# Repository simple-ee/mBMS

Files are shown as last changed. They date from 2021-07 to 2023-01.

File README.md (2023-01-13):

# WARNING!
Just a reminder that this is a DIY product/solution so don’t use this for safety 
critical systems or in any situation where there could be a risk to life. 
There is no warranty, it may not work as expected or at all.

# modular BMS by simple-ee.com
This is what I am calling the modular BMS for an 8S LiFePO4 pack.  I've designed
this as three main parts.  Currently this design is functional and running my
system but I am in the progress of overhauling the design by upgrading from an 
8-bit ATmega328PB to a 32-bit SAMD21G18 using the arduino zero bootloader.

Right now I'm essentially maxed out resources and memory on the atmega328PB and
cannot add anymore features which is why I'm planning on upgrading the design.

Even though this design is now my old design its still very functional and very
stable as it has been running my 4kWh system for about 6 months and protecting 
the cells perfectly.  

The reason for making it a modular design is for easy upgradability and also,
considering the current chip shortage, is to replace sections of the board in
case there are no parts available.  This will prevent the need to redo and 
re-layout of the entire design.

I'm posting this design because I've learned a lot from other projects and feel
this will help a lot of people and want to give back.  Also smarter people than
me could take this design and help optomize the code and design and make this a
community BMS.

## the Table of Contents
1. [the Setup](#thesetup)
    1. [Software/Bootloader](#software)
    2. [Wiring and Connection](#connect)
2. [Pinout and Block Diagram](#pinout)
3. [Board Information](#information)
    1. [the Protection Board](#theProtectionBoard)
    2. [the BMS Board](#theBMSBoard)
    3. [the Passive Board](#thePassiveBoard)
    4. [the Display](#display)

## the SETUP 

### Software/Bootloader 
[Software Setup](https://github.com/simple-ee/mBMS/tree/main/Setup)

### Wiring and Connection 
#### Single 8S Pack Wiring Diagram
Here we have the wiring diagram for connecting the mBMS to an 8S pack and is considered a single pack system:

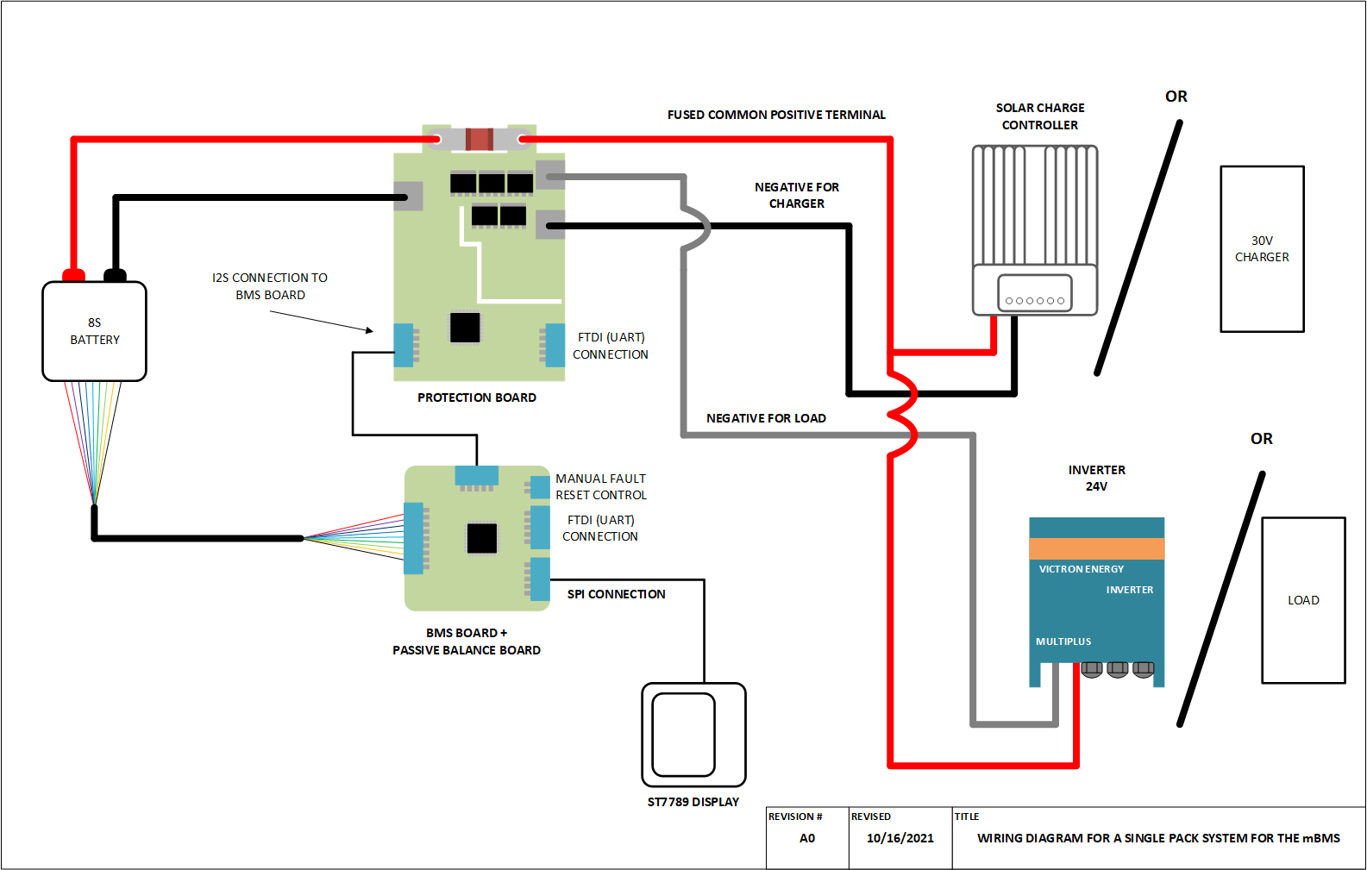
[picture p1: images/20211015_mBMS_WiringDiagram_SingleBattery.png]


#### Parallel multiple 8S Wiring Diagram
Here we have the wiring diagram for connecting multiple 8S packs in parallel.  Here each 8S pack is protected by its own mBMS and then they are paralleled together using 
ideal diodes to make sure that the other packs in parallel do not charge or discharge a pack that has gone into protection.  I designed the system this way to allow
for scalability of system storage.  By protecting each pack separately then you can, theoretically, add tens of hundreds of 8S packs in parallel when you need more storage
without having to reconfigure your system to add more storage or turn off the system to add more storage.

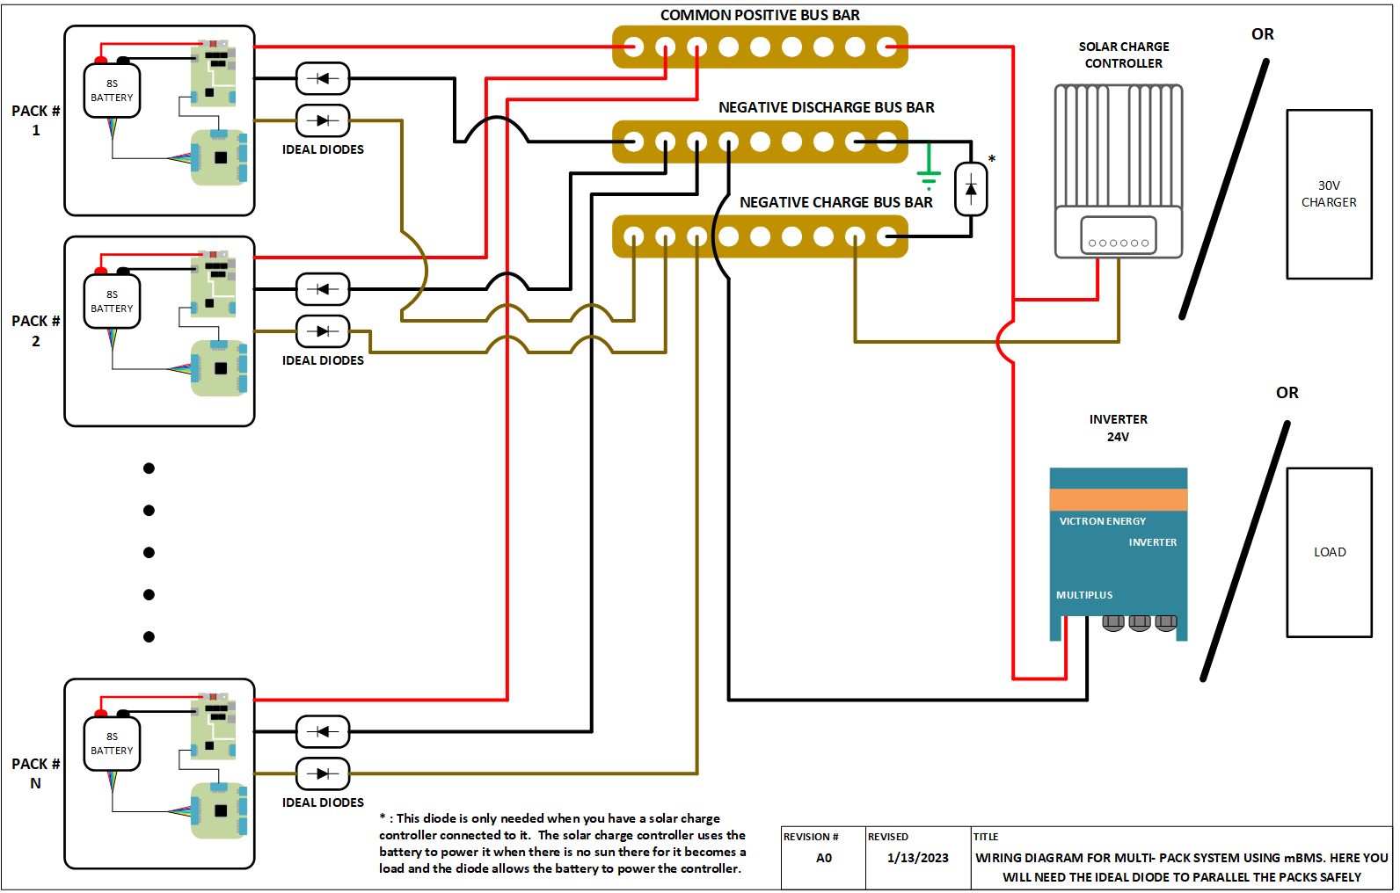
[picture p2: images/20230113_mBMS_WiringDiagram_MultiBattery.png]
 

## Pinout and Block Diagram 

### the Protection Board
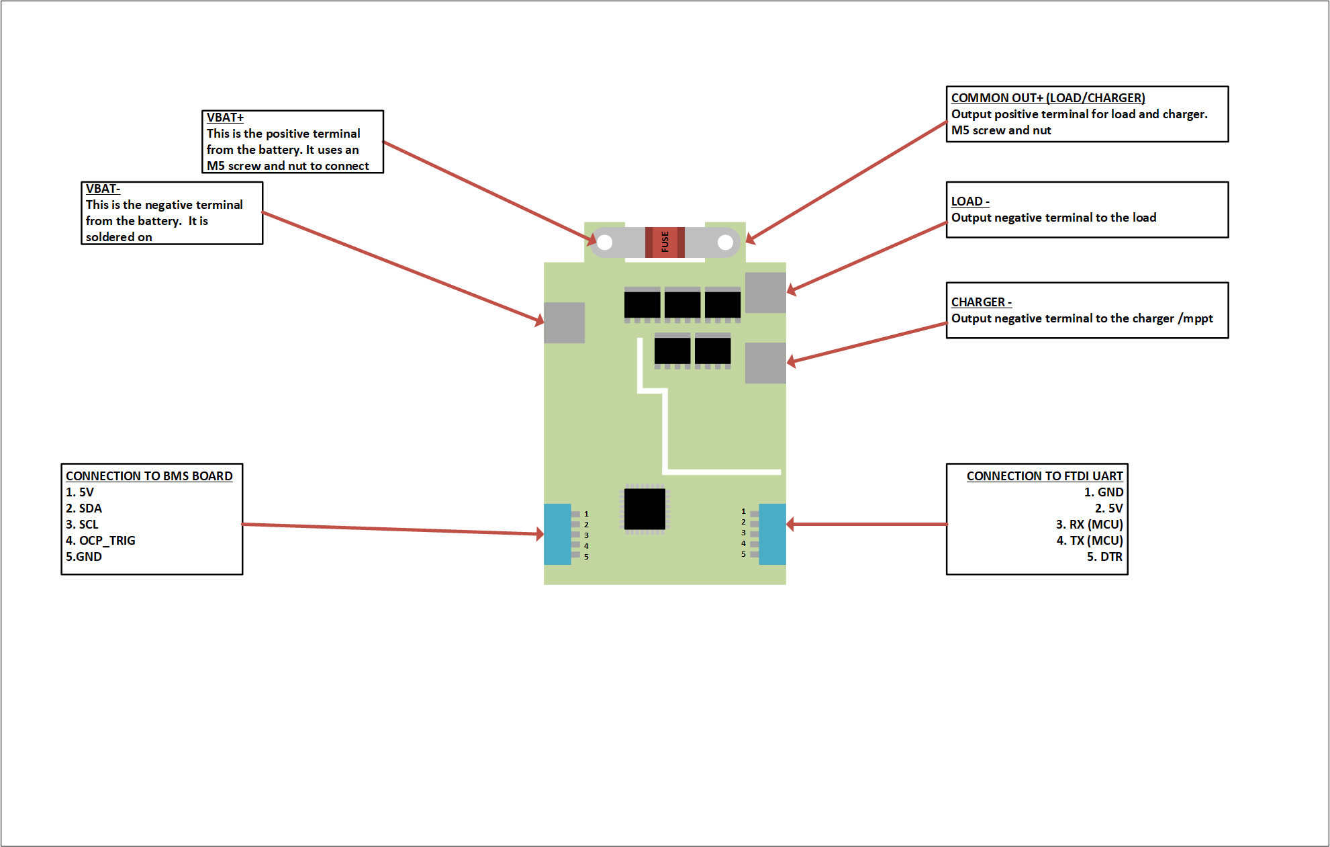
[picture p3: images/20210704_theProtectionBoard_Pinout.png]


## Board information 

### the Protection board 

[kicad Files and gerber files](https://github.com/simple-ee/mBMS/tree/main/Schematic/The%20Protection%20Board)

#### Rendered PCB
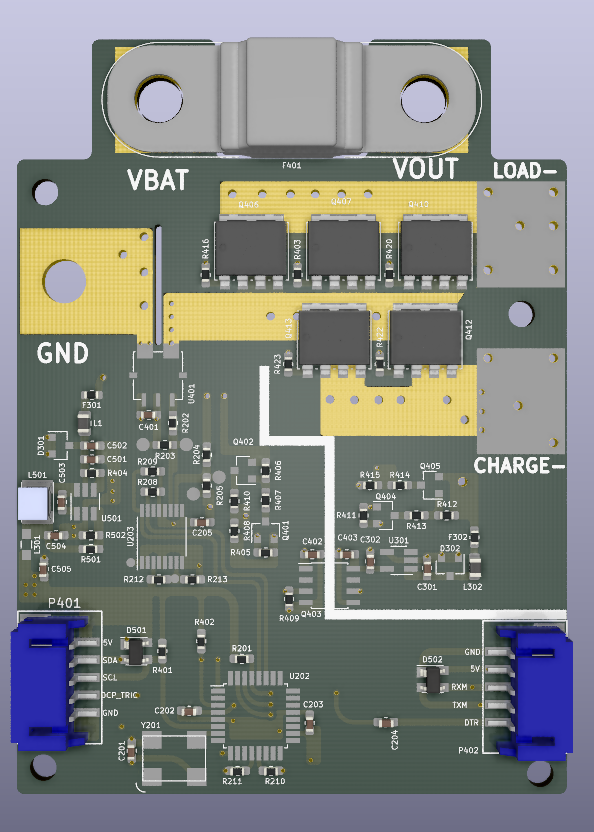
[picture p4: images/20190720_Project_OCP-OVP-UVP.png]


#### Actual PCB
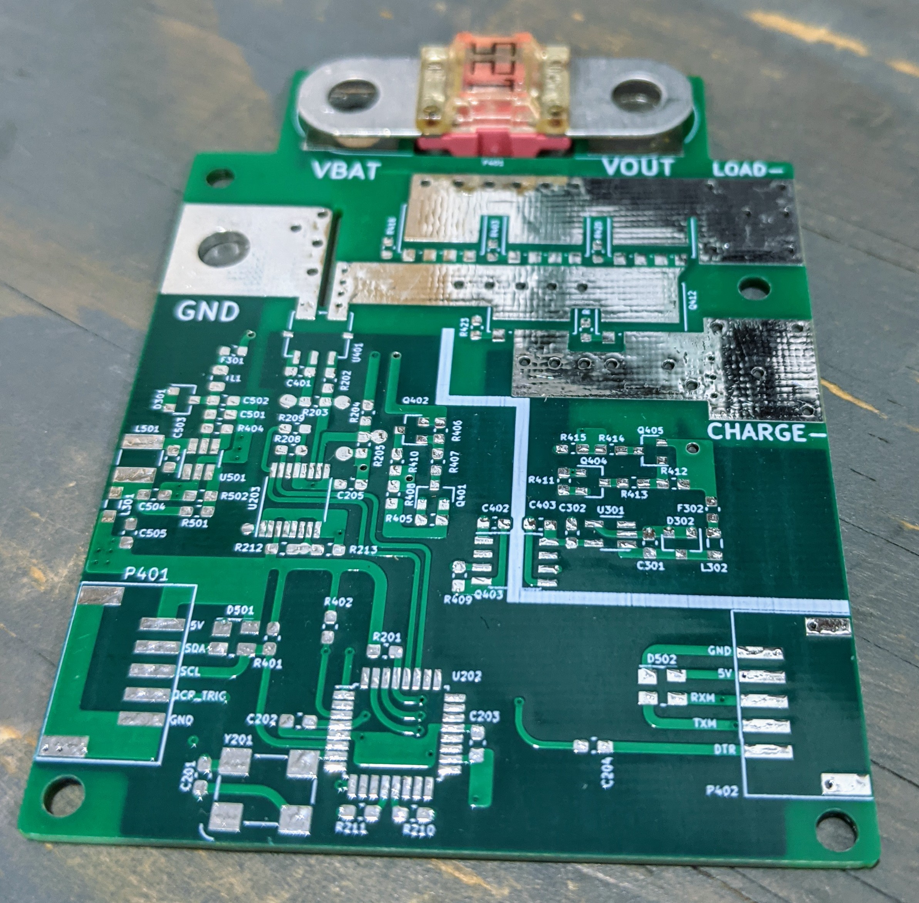
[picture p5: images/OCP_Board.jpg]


- This board will handle discharge and charge currents between the battery
and the external world.  
- It has the following specs:

    Item | Description
    -----|------------
    1 | 4-Channel 16-BIT ADC with an effective resolution of 16-Bit at 20sps
    2 | 100A hall effect current sensor
    3 | Up to 3 Discharge N-Channel MOSFETS with 0.7mOhm DCR and 425A current capability. ( Effective current handling per mosfet without heatsink is 30A)
    4 | Up to 2 charge N-Channle MOSFETS with 0.7mOhm DCR and 425A current capability. (Effective current handling per mosfet without heatsink is 30A)
    5 | Optoisolator to drive the charge mosfets as it is floating relative to the battery ground.
    6 | High efficiency buck converter to power the MCU and supporting circuits.
    7 | Low power LDO to power the secondary side of the optoisolator to drive the charge MOSFET
    8 | Two I2C ports, one to act as an internal COM for adc and display, andsecond one to act as external COM to relay information to BMS board
    9 | 125A fuse that will act as the short circuit protection with a breaking capacity of 1kA.

### the BMS Board 

[kicad Files and gerber files](https://github.com/simple-ee/mBMS/tree/main/Schematic/The%20BMS%20Board)

#### Rendered PCB
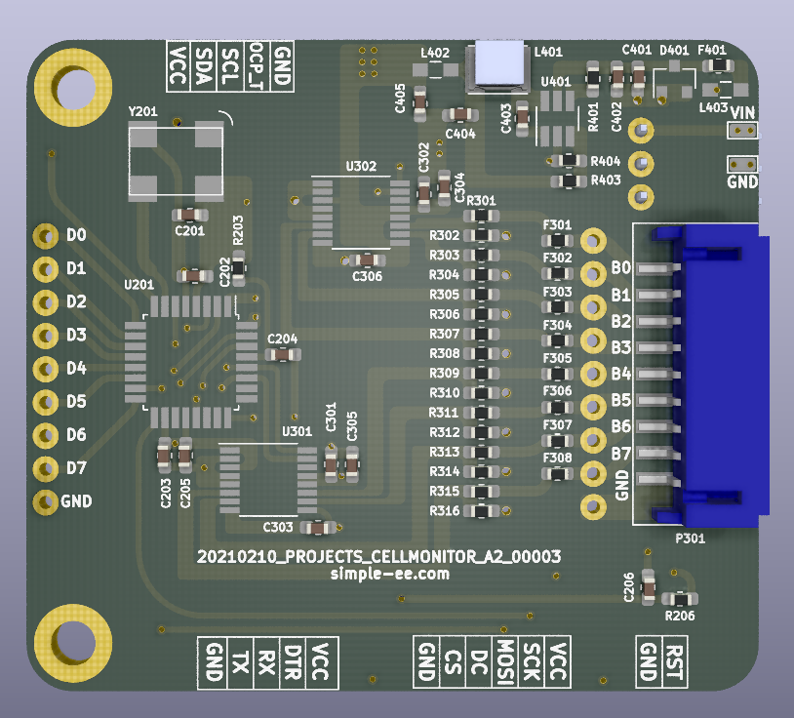
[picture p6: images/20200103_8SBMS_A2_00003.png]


#### Actual PCB
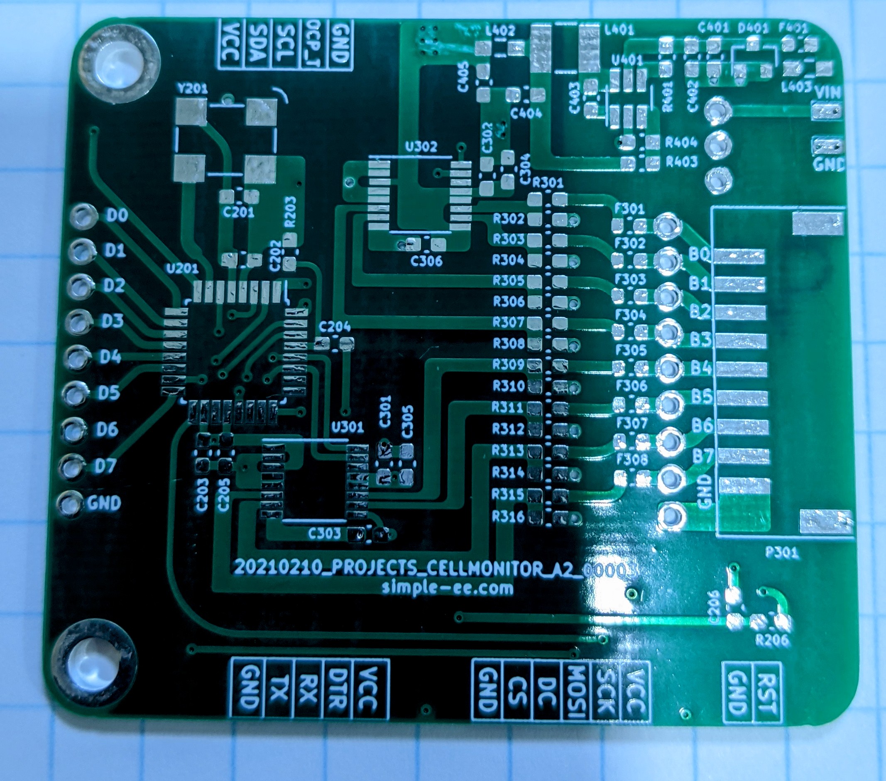
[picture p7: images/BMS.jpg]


- This board is handling the cell level monitoring function as well as sending
controls to the passive balance resistors for balancing the cells.  It 
incorporates cell level OVP and UVP which is configurable and also receives the
current values from the Protection board via I2C and then displays all values
on a TFT display either ST7735 or ST7789.  If for any reason a fault is triggered
or one of the configured protection values is triggered you can send a reset
fault command either via an external trigger button or serial command over uart.
- It has the following specs:

Item | Description
-----|------------
1 | x2 4-Channel 16-BIT ADC with an effective resolution of 16-BIT at 20sps
2 | External 16MHz Crystal oscillator
3 | External SPI port to connect TFT display
4 | Can be powered via the battery pack or external power source
5 | External action button. Default state is for reset fault condition

### the Passive Balance Board 

[kicad Files and gerber files](https://github.com/simple-ee/mBMS/tree/main/Schematic/The%20Passive%20Balance%20Board)

#### Rendered PCB
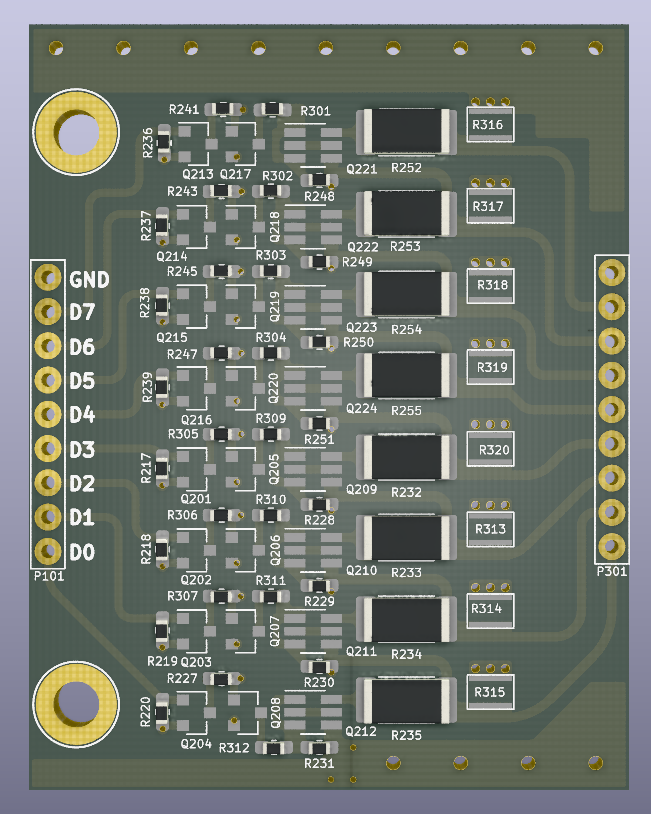
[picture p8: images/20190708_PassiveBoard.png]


#### Actual PCB
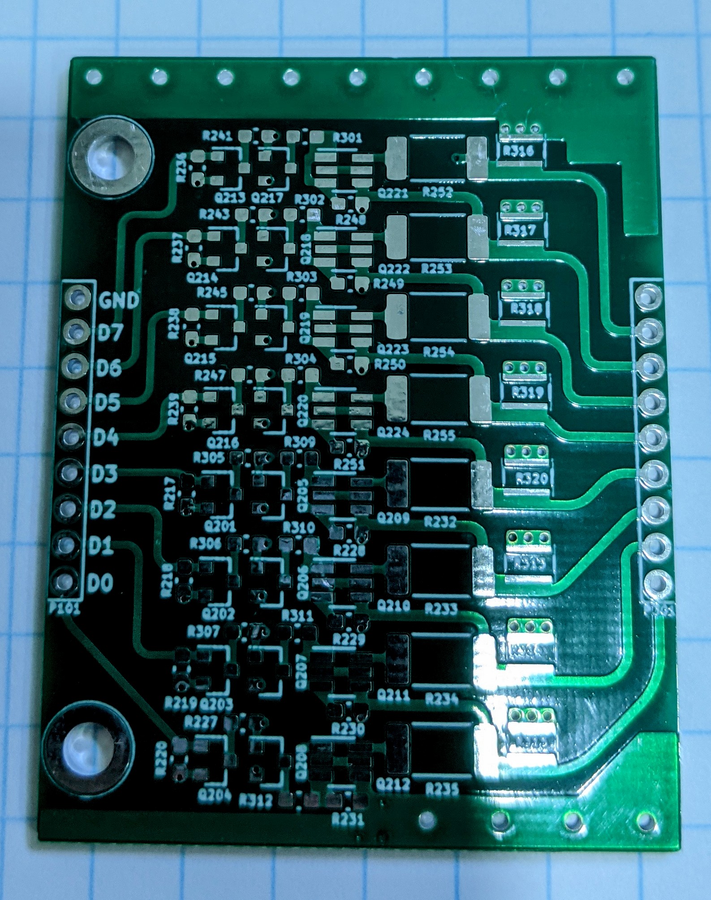
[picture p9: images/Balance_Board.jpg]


The passive board essentially is controlled by the BMS board to allow the 
bleeder resistor to slow down the rate of charge for that particular cell when
the BMS board detects that the cell is too high of a delta from the rest.

Currently I have a 2W 10R resistor but I'm having thermal issues because its 
quite a lot of power to dissapate over the whole board so I'd recommend a 22R 2W
resistor which is still good for what you need but will not cause any potential
damage.

The board also have the option of adding thermal jumpers and if you do decide to 
do that then I'd recommend a 2oz copper for that PCB.  Thermal jumpers are electrically
isolated and allow you to connect directly to ground without shorting anything
which is pretty awesome in my opinion.

Heres the link for the thermal jumpers.  They are really awesome but with the chip
shortage its a decent lead time for them.

https://www.digikey.com/en/products/detail/vishay-dale-thin-film/THJP0612AST1/11313314

### the Display (optional) 
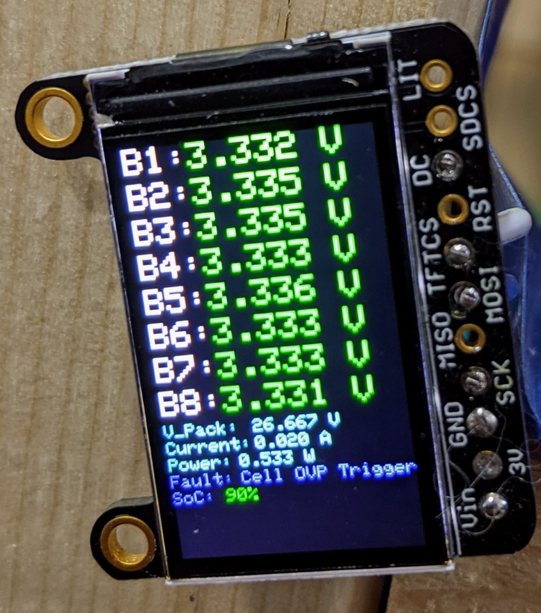
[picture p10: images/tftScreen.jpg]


Currently the SoC is not an implemented function its just a placeholder.  But if
anyone is willing to help out with this SoC code section then that would be 
awesome as I'm still not sure the best way to implement this.

The screen is to be used with the BMS board.  the Protection does not have 
the ability to use a SPI TFT display but if you use it on its own, then you can
add an I2C oled display because the secondary I2C will not be used.

Here is a link to the tft display that I used.
https://www.adafruit.com/product/4383

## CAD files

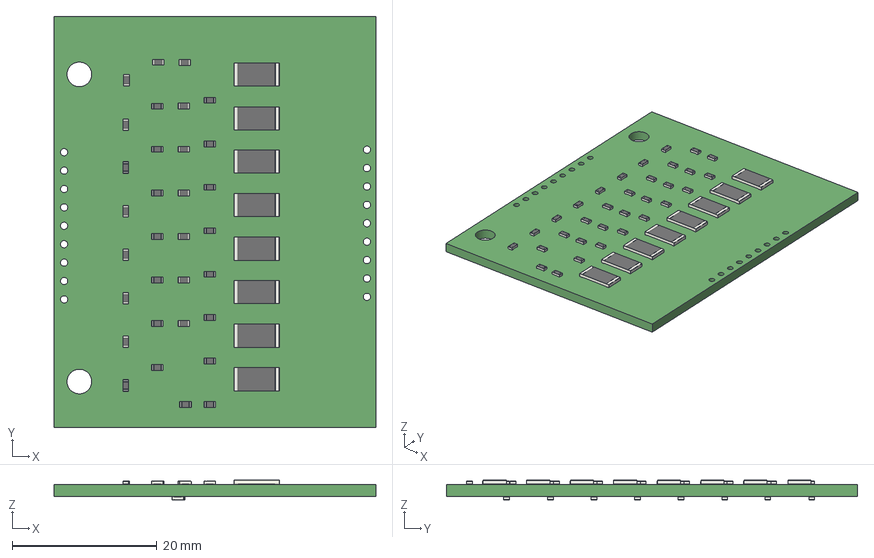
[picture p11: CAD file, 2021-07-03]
Schematic/The Passive Balance Board/20210213_Projects_PassiveBalanceBoard.step
44.5 x 56.8 x 2.75 mm

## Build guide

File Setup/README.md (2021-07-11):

# SETUP for modular BMS by simple-ee.com
Here we will choose the bootloader for this board, upload the arduino sketch,
and run through the different serial and I2C commands for both the Protection
board as well as the BMS board.

We will also run through the calibration of the adc inputs to get an accurate
voltage measurement and current measurement.

We will also run through the two different ways of using this system.
1. Using the Protection board on its own
2. Connecting the Protection board to the BMS board for cell level protection

## the Table of Contents
1. [the bootloader](#bootloader)
2. [Arduino Sketch](#sketch)
3. [the Protection Board Configuration](#protection)
4. [the BMS Board Configuration](#bms)

## Bootloader
Here I decided to use the minicore bootloader for the atmega328PB as it allowed
me to configure the arduino with various options, it seems very efficient in 
memory space and also supports the PB variant of atmega328

[minicore](https://github.com/MCUdude/MiniCore)

Note: Since I did not add the SPI pins on the board (MOSI,MISO) you will have
to install the bootloader before soldering it to the board.  You can follow the
guide below to add the bootloader using an arduino uno board:

[Install ardunio bootloader](https://www.arduino.cc/en/Tutorial/BuiltInExamples/ArduinoToBreadboard)

https://www.arduino.cc/en/Tutorial/BuiltInExamples/ArduinoToBreadboard

## Arduino sketch
Here is the source code link for both:

1. The Protection board
    1. [theProtectionBoard](https://github.com/simple-ee/mBMS/tree/main/Source%20Code/theProtectionBoard/)
2. The BMS Board
    1. [theBmsBoard](https://github.com/simple-ee/mBMS/tree/main/Source%20Code/theBMSBoard/20210703_theBMSBoard_A6)

Note: For board source code files, I created a second file called ADS1119.h which
I created to make using the ADC easier in the arduino code.  This file must be in the
same folder as the arduino ino.

## the Protection Board configuration

To perform setup you will need the following items:
1. Multimeter
2. UART FTDI adaptor, ex. [FTDI](https://www.amazon.com/HiLetgo-FT232RL-Converter-Adapter-Breakout/dp/B00IJXZQ7C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)
    1. Use the 5V configuration
3. a Pair of metal tweezers
4. 20V - 30V DC source, it could be connected to the battery 

After you upload the sketch to the Protection board, there are still a couple of
steps that need to be performed to get the unit up and operational.

In the arduino sketch, towards the end of the arduino code, you will find the
following serial monitor commands:

```c++
////////////////////////////////////////////////////////////////////////////////
// This function is called everytime a uart command is received.  We use it 
// combined with the arduino serial monitor to set variables and perform
// certain commands.
// example of command to send via serial monitor:
// ex. 1004, OCP, OVP, UVP
//     1004,30.00,29.00,21.00
//------------------------------------------------------------------------------
// List of commands
//------------------------------------------------------------------------------
// 1. 1001,2.500  | This is for performing a two point calibration for the 
//                | current measurement and then storing those values in 
//                | the eeprom.
//------------------------------------------------------------------------------
// 2. 1002,29.00  | This is for performing a two point calibration for the 
//                | voltage of the battery and then storing is in eeprom
//------------------------------------------------------------------------------
// 3. 1003,5.00   | This is for performing a two point calibration for the 
//                | system rail voltage and then storing is in eeprom
//------------------------------------------------------------------------------
// 4. 1004,30.00, | This is to enter new values for over current limit,
//    29.00,21.00 | over voltage limit, and under voltage limit
//------------------------------------------------------------------------------
// 5. 1005        | Future command place holder
//------------------------------------------------------------------------------
// 6. 1006        | Turns off the mosfets to prevent current flow
//------------------------------------------------------------------------------
// 7. 1007        | This resets any and all fault conditions and returns system
//                | to normal conditions
//------------------------------------------------------------------------------
// 8. 1008,0.01333| This sets the sensativity value for the current sensor
//------------------------------------------------------------------------------
// 9. 1009        | Outputs limits and revision number
//------------------------------------------------------------------------------
// 10. 1010       | Sets the interval value for display output
//------------------------------------------------------------------------------
// 11. 1011       | Sets the offsetcurrentzero value to help with getting a 
//                | a better current measurement
////////////////////////////////////////////////////////////////////////////////
```
Perform the following steps in order:
1. In serial monitor using the FTDI adaptor, set the BAUD rate to 115200
2. Initially you will not see anything on the monitor because we need to set
the interval of the serial print loop.
    1. Type in:
    ```c++
    1010, 1000
    ```
    This will set the interval to 1 second interval.  Since we are storing
    this value in eeprom, with a new MCU IC the eeprom has this value as 0 so
    the loop will not operate without entering a value in eeprom and this
    command stores the 1000 millisecond value in eeprom.

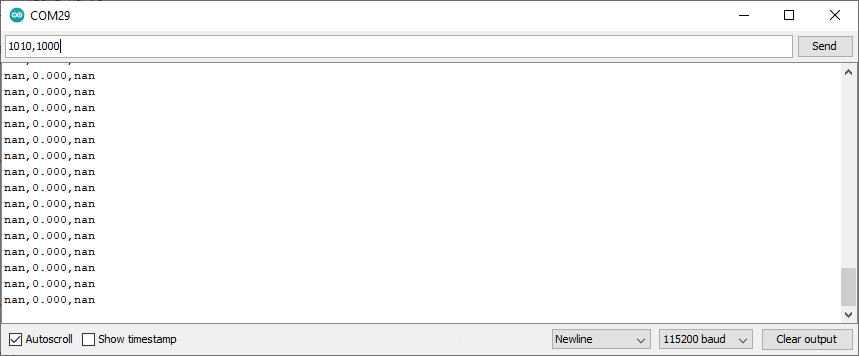
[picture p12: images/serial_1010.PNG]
    

2. Next we will set the sensativity value of the hall effect sensor
    1. Type in:
    ```c++
    1008, 0.01333
    ```
    This sets the sensativity value to 13.33mV

3. Now we will perform 1 of 3 two point calibration measurements.  Here you will
need to now power the board from a 20V-30V dc source ( your battery pack will
work just fine) instead of the ftdi board. You will also need the metal tweezers.
    1. First take a measurement of the output of the current sensor (pin 3) with
    you multimeter and write down that value.
    2. Next type in the following into the serial monitor but do not hit enter
    just yet:
    ```c++
    1001, 2.517
    ```
    The 2.500 is the voltage measurement you just took with your multimeter

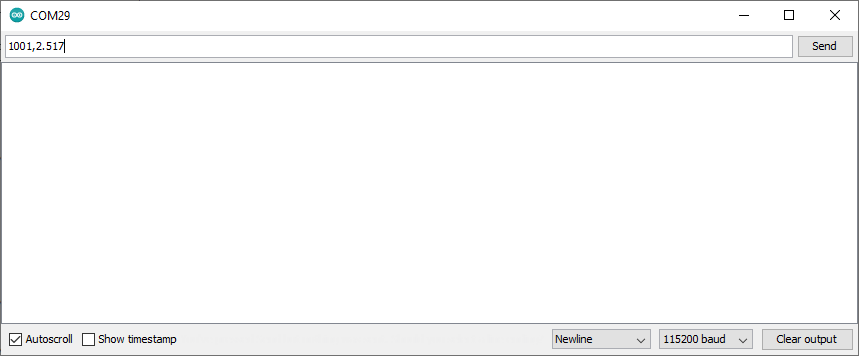
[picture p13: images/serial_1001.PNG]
    

    3. Now with the metal tweezers, short the points across resistor R203 with 
    your tweezers and then hit enter on the serial monitor.
    4. Hold the tweezers until the serial monitor prompts you with the following:
    ```c++
    Connect Full scale reference and enter value 1
    ```
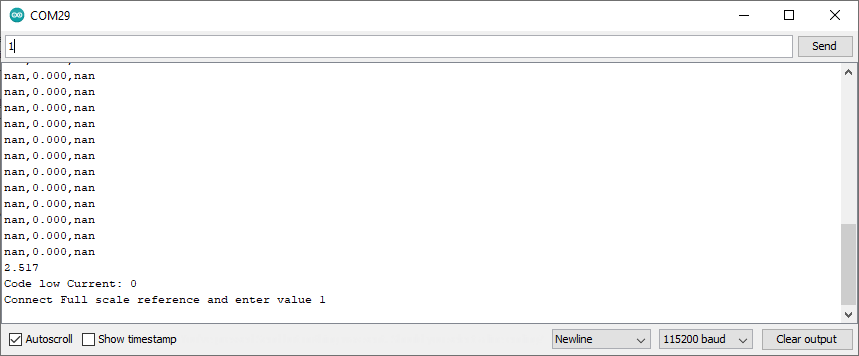
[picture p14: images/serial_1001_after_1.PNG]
    

    5. Then let go of the tweezers and enter 1 in the serial monitor.
    6. Now the current sensor is calibrated.

4. 2 of 3 two point calibration measurements.  Here you will
need to now power the board from a 20V-30V dc source ( your battery pack will
work just fine) instead of the ftdi board. You will also need the metal tweezers.
    1. First take a measurement at the VBAT+ terminal with your multimeter and
    write down that value.
    2. Next type in the following into the serial monitor but do not hit enter
    just yet:
    ```c++
    1002, 24.00
    ```

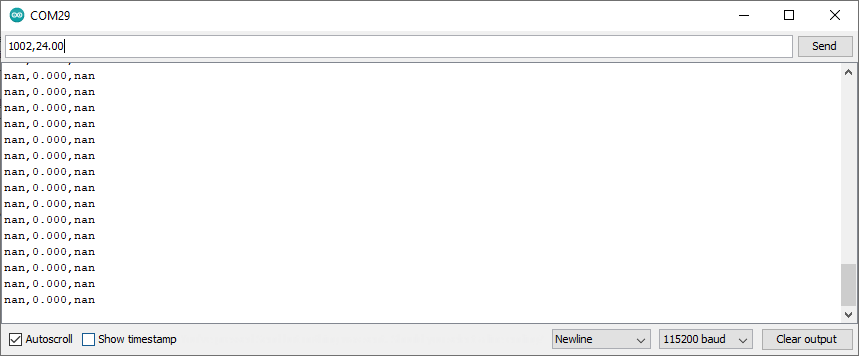
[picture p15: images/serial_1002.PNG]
    

    The 24.00 is the voltage measurement you jsut took with your multimeter

    3. Hold the tweezers across resistor R205 and then hit enter on the serial
    monitor.
    4. Hold the tweezers until the serial monitor prompts you with the following:
    ```c++
    Connect full scale reference and enter value 1
    ```

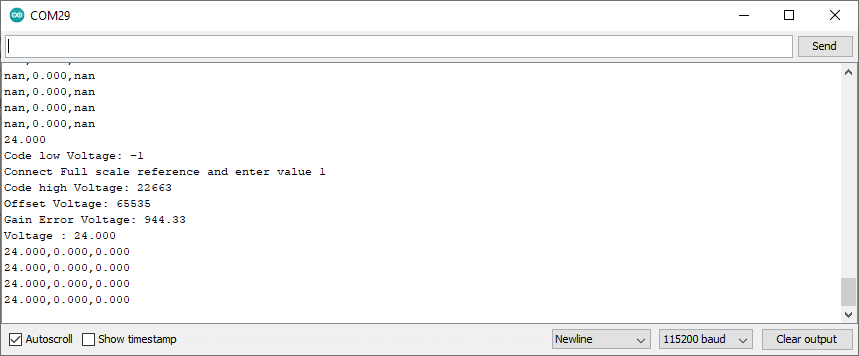
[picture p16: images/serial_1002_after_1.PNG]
    

    5. Then let go of the tweezers and enter 1 in the serial monitor.
    6. Now the battery voltage adc is calibrated.
5. Last we will perform 3 of 3 two point calibration.  This last calibration is
for the system rail at the output of the buck converter.  This is needed to get 
a good 0A reference for the current sensor since its bi-directional it takes
Vsystem/2 to get the 0A reference.
    1. First take a measurement at the output of the buck converter with the 
    multimeter and write down that value.
    2. Next type in the following into the serial monitor but do not hit enter 
    just yet:
    ```c++
    1003, 5.002
    ```
    The 5.002 represents the measurement system voltage

    3. Hold the tweezers across resistor R213 and the nhit enter on the serial
    monitor.
    4. Hold the tweezers until the serial monitor prompts you with the following:
    ```c++
    Connect full scale reference and enter value 1
    ```

    5. Then let go of the tweezers and enter 1 in the serial monitor.
    6. Now the system voltage adc is calibrated

The last step is to set the limit for the protection threshold values.
6. Enter the following into the serial monitor;
```c++
1004,30.00, 29.00, 21.00
```
The first value is the over-current threshold limit so the mosfets will stop
charging or discharging if the current hits this limit. 

The next value is the over-voltage threshold limit so the charging mosfet will
stop charging if the voltage threshold is hit.

The last value is the under-voltage threshold limit so the discharging mosfet will
stop discharging if the voltage of the pack goes below this value.

7. Last step is to set the offset zero current commands.  This automatically
eliminates any offset that will show a positive or negative current value
when no load is connected.
    1. Enter the following in serial monitor:
    ```c++ 
    1011
    ```  

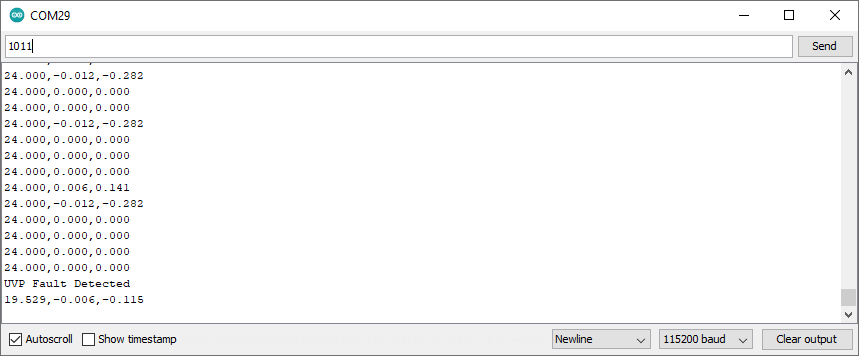
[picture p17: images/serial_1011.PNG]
    

Now you are ready to use the Protection Board.

## the BMS Board configuration

To perform setup you will need the following items:
1. Multimeter
2. UART FTDI adaptor, ex. [FTDI](https://www.amazon.com/HiLetgo-FT232RL-Converter-Adapter-Breakout/dp/B00IJXZQ7C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)
    1. Use the 5V configuration
4. Here there are two options you can go about for adc calibration:
    1. 8S battery or
    2. A stackable 8 series voltage reference. Here is a link to the REF50 which
    is what I use to calibrate my BMS:
        1. Link: [Stackable Voltage Reference](https://www.ti.com/lit/an/sbaa203/sbaa203.pdf?ts=1625974619837&ref_url=https%253A%252F%252Fwww.google.com%252F)

After you upload the sketch to the BMS boar, there are still a couple of steps that
you need to perform before the system is up and running.

In the arduino sketch, towards the end of the arduni code, you will find the 
following serial monitor commands:

```c++
////////////////////////////////////////////////////////////////////////////////
// This function is called everytime a uart command is received.  We use it 
// combined with the arduino serial monitor to set variables and perform
// certain commands.
// example of command to send via serial monitor:
// ex. 101, UVP
//     101, 2.70
//------------------------------------------------------------------------------
// List of commands
//------------------------------------------------------------------------------
// 1. 10          | Resets two point calibration values
//------------------------------------------------------------------------------
// 2. 11          | Blank Function 
//------------------------------------------------------------------------------
// 3. 12,3.00,6.00, | Two point calibration for the adc values.  First set 
//    9.00,12.00,   | the jumper to external power for the bms board, then
//    15.00,18.00,  | apply voltages to each adc input and measure each 
//    21.00,24.00   | point with a multimeter and write down those values.
//                  | Enter those values in order from lowest to highest
//                  | like so: 12,cell1,cell2,cell3,cell4,cell5,cell6,cell7,
//                  | cell8
//------------------------------------------------------------------------------
// 4. 100,0.015   | Sets new delta between the lowest cell and the rest of the 
//                | cells.  The example on the left sets the tolerance to 15mV
//------------------------------------------------------------------------------
// 5. 101, 2.70   | Sets new under voltage threshold value
//------------------------------------------------------------------------------
// 6. 102, 3.75   | Sets new over voltage threshold value
//------------------------------------------------------------------------------
// 7. 103, 1000   | Sets new value for main loop interval
//------------------------------------------------------------------------------
// 8. 1000        | Resets fault condition and returns system to normal
//------------------------------------------------------------------------------
// 9. 1001        | Test function (not used)
////////////////////////////////////////////////////////////////////////////////

```

### Wiring and Connection

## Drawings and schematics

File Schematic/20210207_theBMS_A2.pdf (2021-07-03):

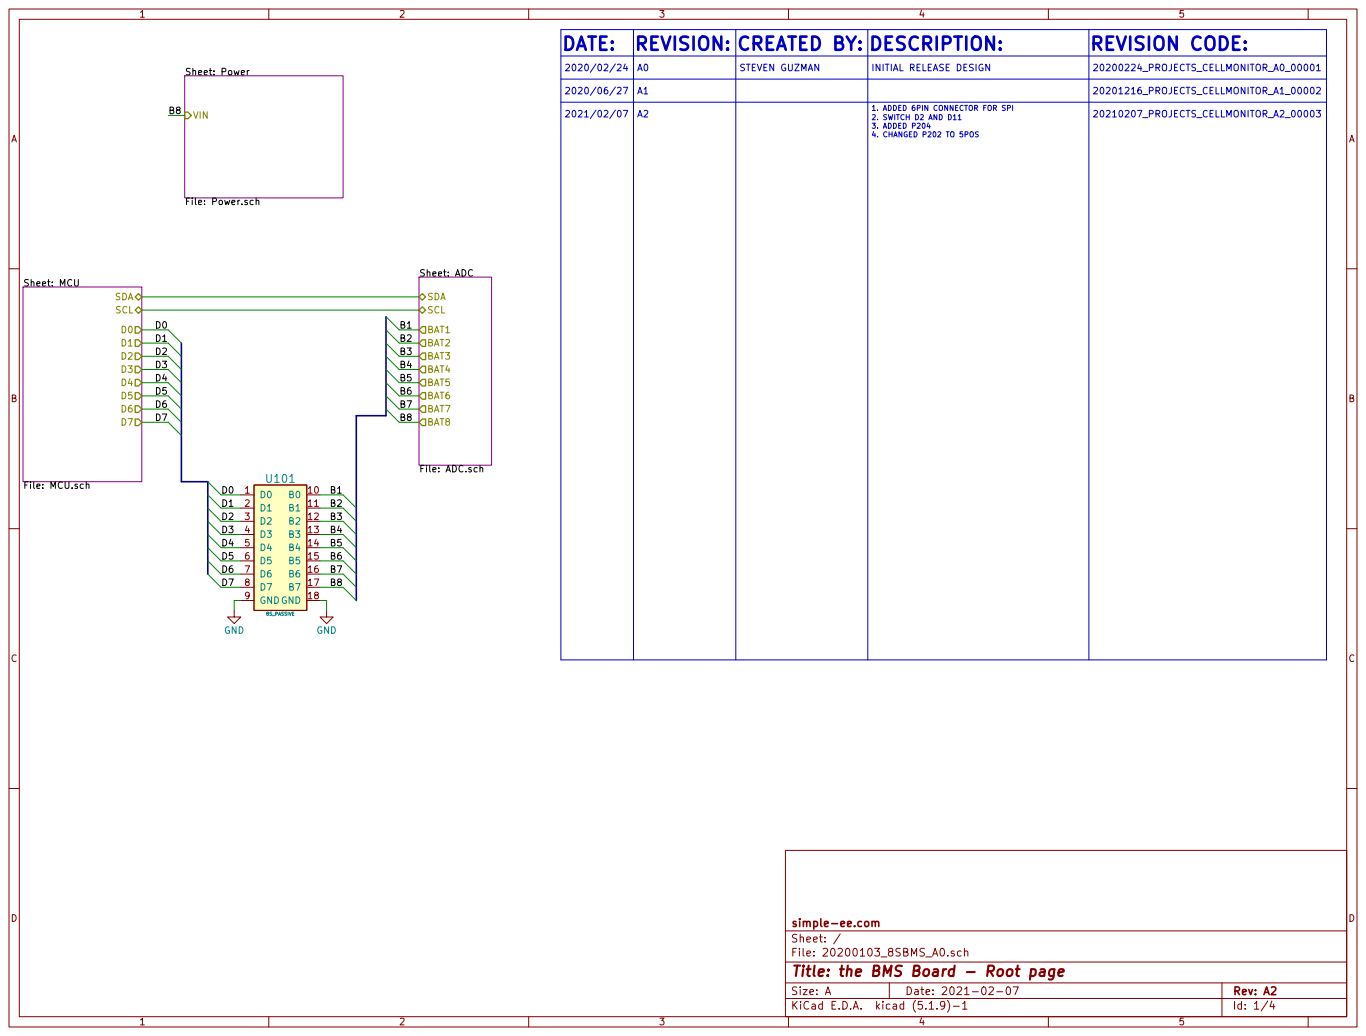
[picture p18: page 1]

Sheet: ADC
File: ADC.sch SDA

File: 20200103_8SBMS_A0.sch Sheet: / simple-ee.com

Id: 1/4 Title: the BMS Board - Root page

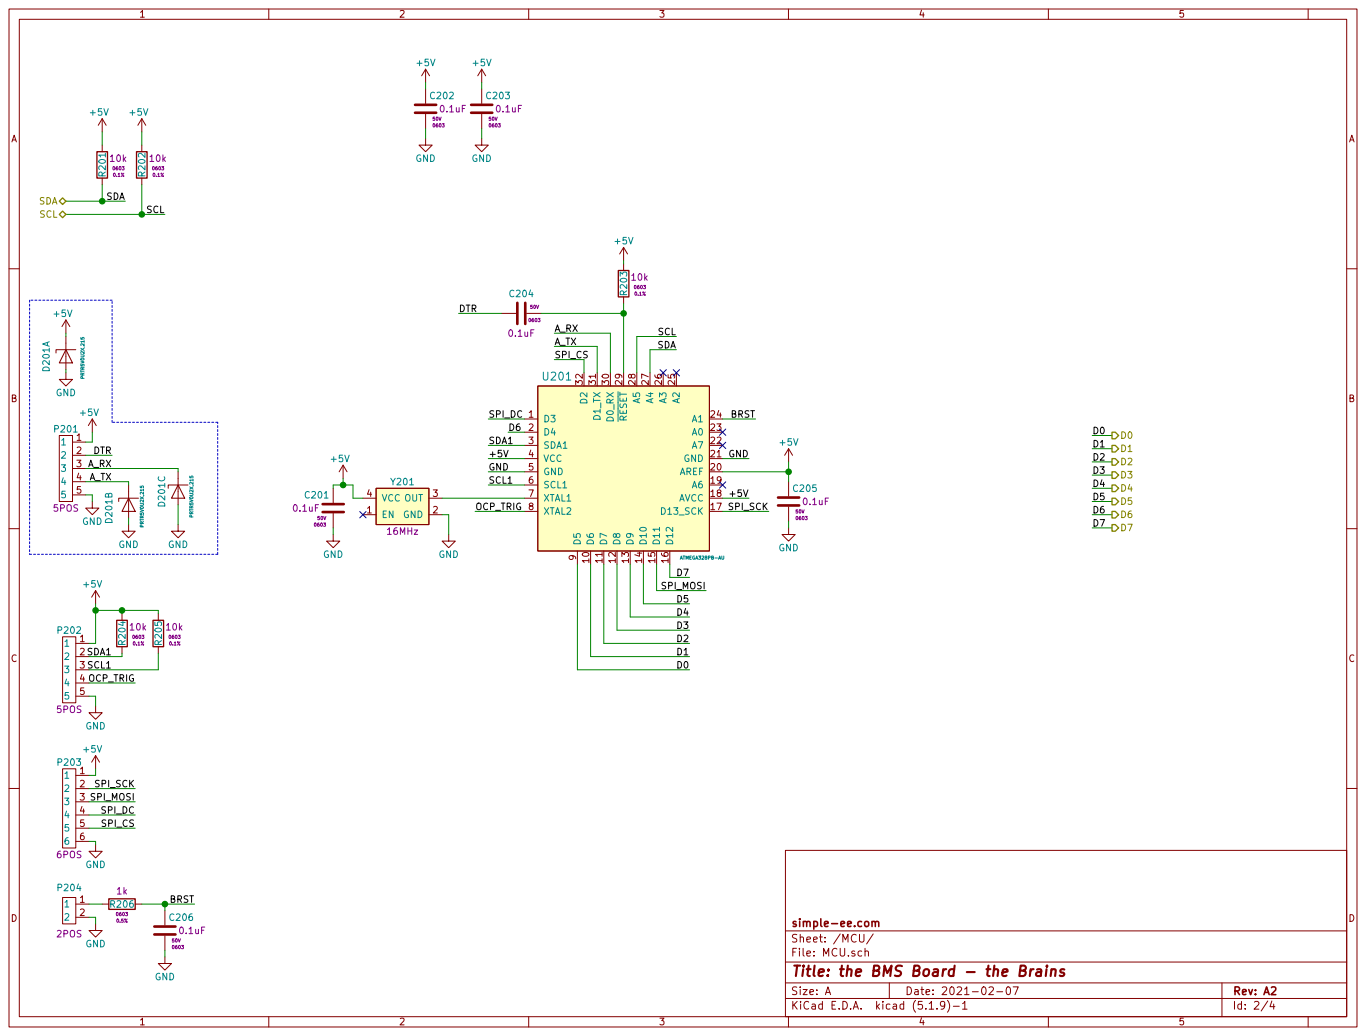
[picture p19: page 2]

Id: 2/4 Title: the BMS Board - the Brains

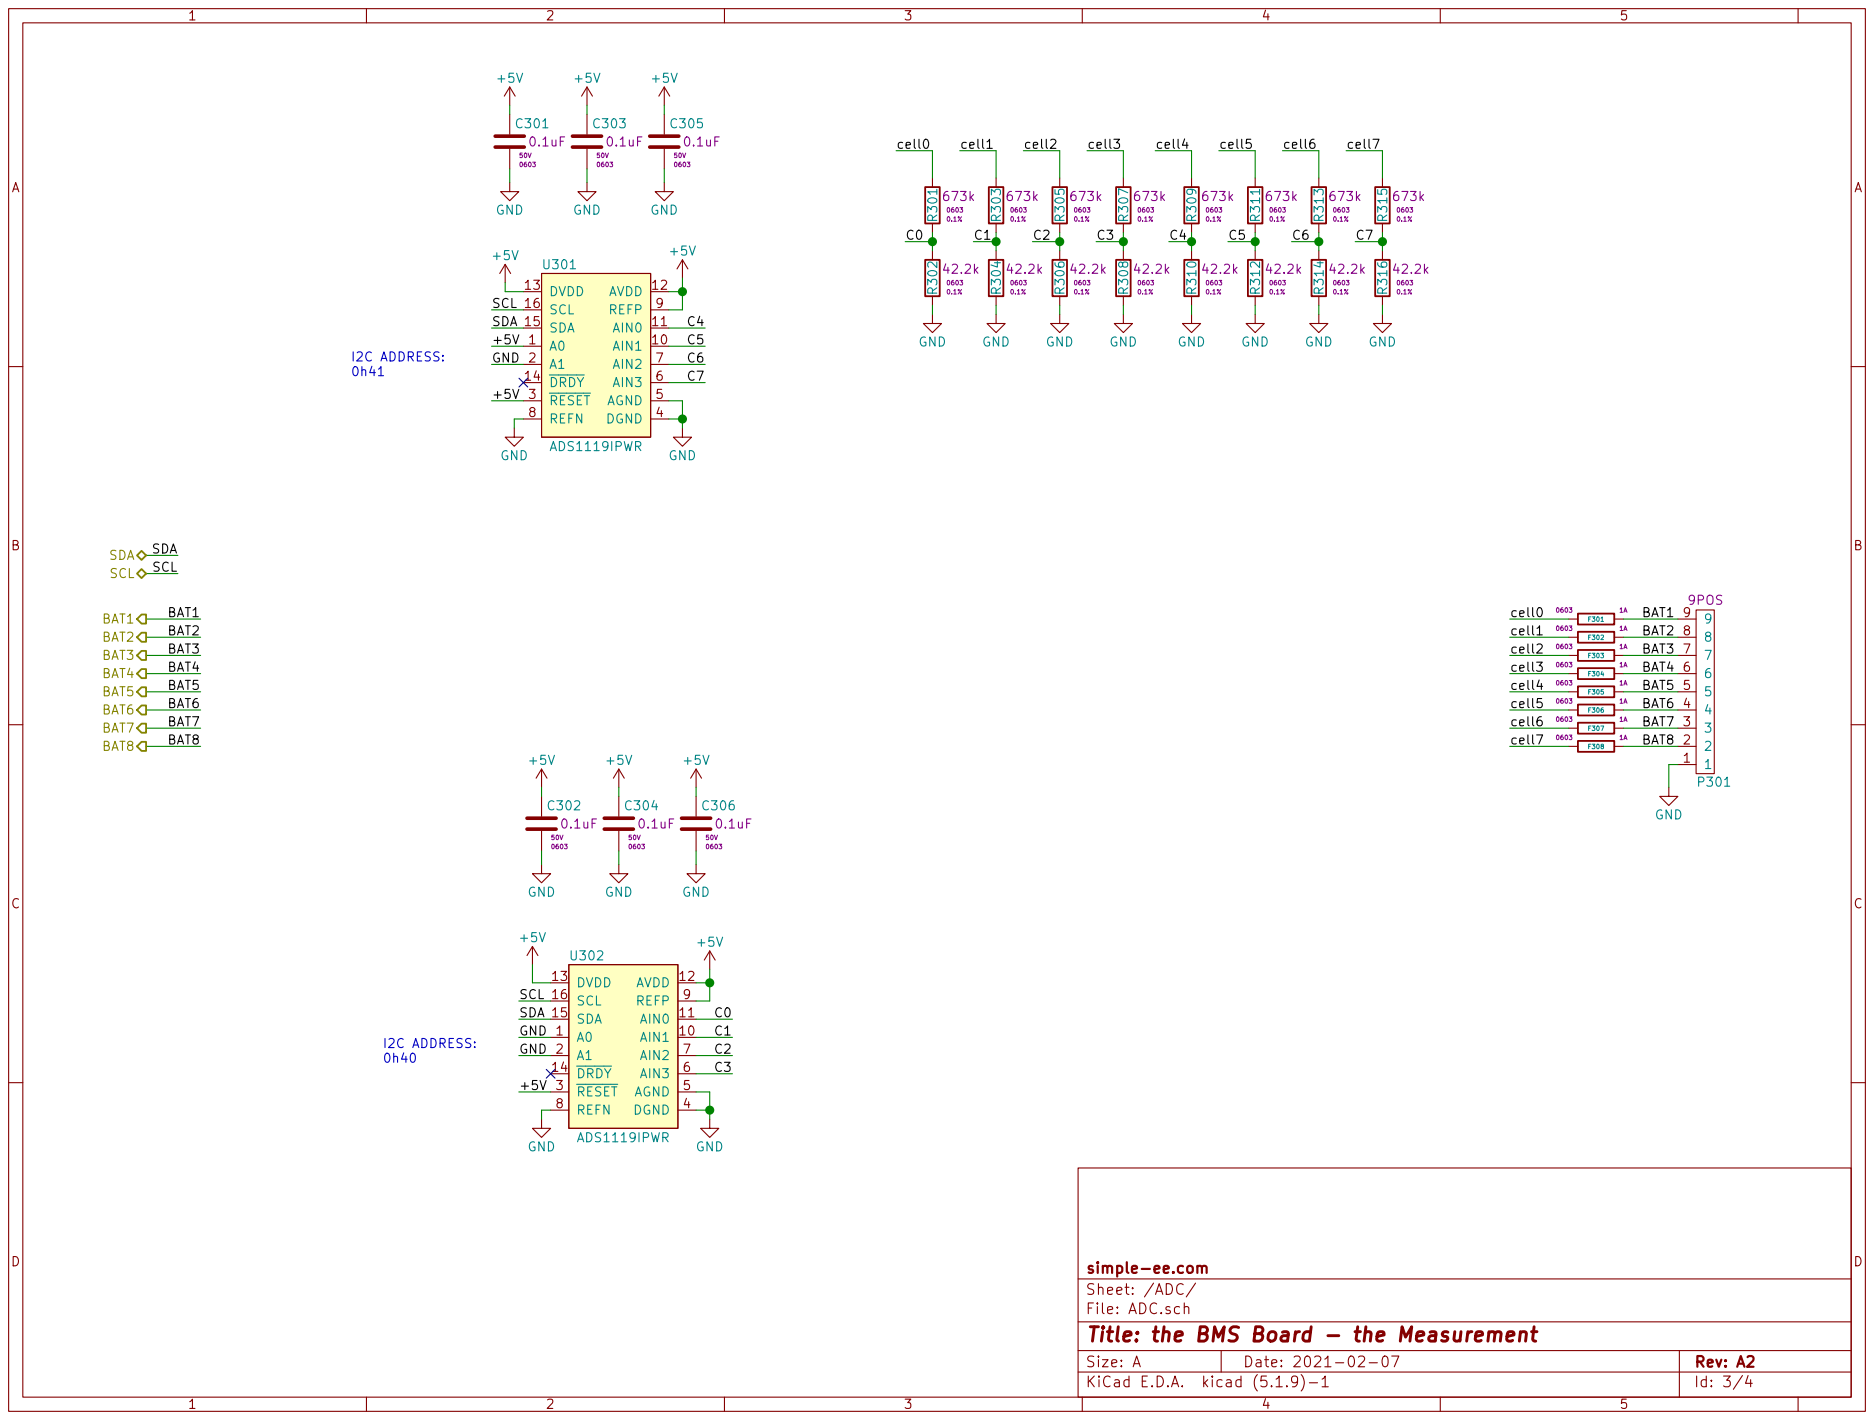
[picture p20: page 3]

Id: 3/4 Title: the BMS Board - the Measurement File: ADC.sch Sheet: /ADC/ simple-ee.com

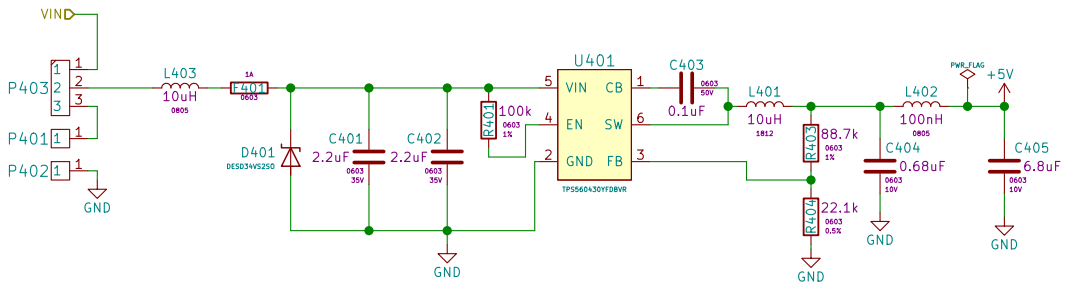
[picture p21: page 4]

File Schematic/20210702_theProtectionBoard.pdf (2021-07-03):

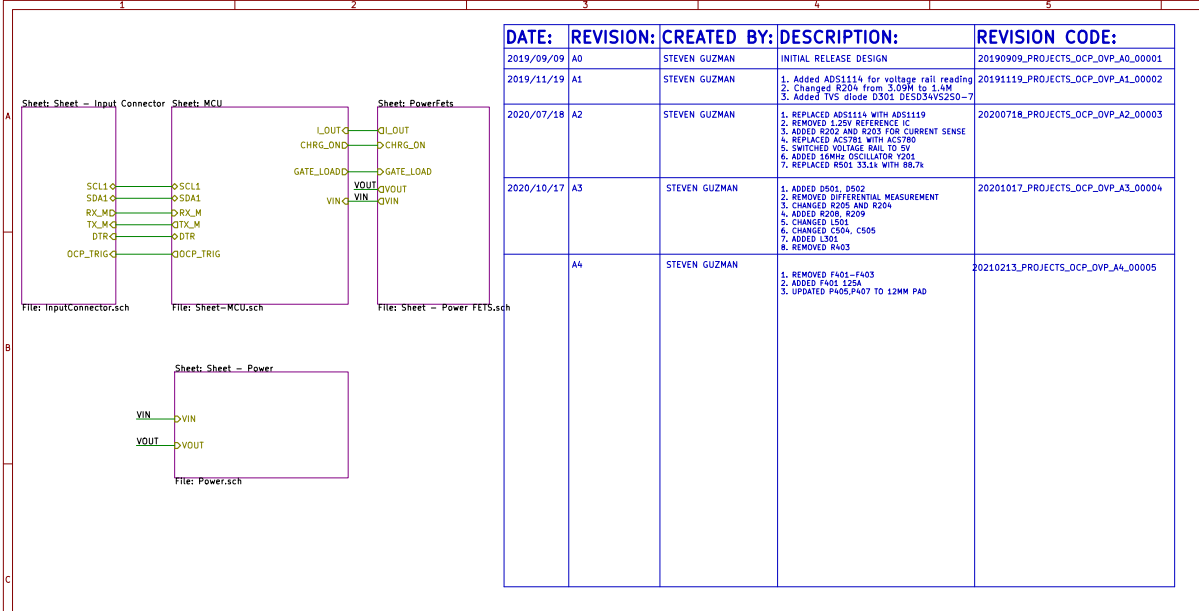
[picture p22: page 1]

Sheet: Sheet - Input Connector

Sheet: PowerFets File: Sheet - Power FETS.sch

1. REPLACED ADS1114 WITH ADS1119
2. REMOVED 1.25V REFERENCE IC
3. ADDED R202 AND R203 FOR CURRENT SENSE
4. REPLACED ACS781 WITH ACS780
5. SWITCHED VOLTAGE RAIL TO 5V
6. ADDED 16MHz OSCILLATOR Y201

2020/10/17 | A3 | STEVEN GUZMAN | 1. ADDED D501, D502 2. REMOVED DIFFERENTIAL MEASUREMENT 3. CHANGED R205 AND R204 4. ADDED R208, R209 5. CHANGED L501 6. CHANGED C504, C505 7. ADDED L301 | 20201017_PROJECTS_OCP_OVP_A3_00004

File: InputConnector.sch DTR

A4 | STEVEN GUZMAN | 1. REMOVED F401-F403 2. ADDED F401 125A 3. UPDATED P405,P407 TO 12MM PAD | 20210213_PROJECTS_OCP_OVP_A4_00005

Sheet: Sheet - Power File: Power.sch VIN

File: 20190720_Project_OCP-OVP-UVP.sch Sheet: / simple-ee.com

Id: 1/5 Title: the Protection Board - Root Page

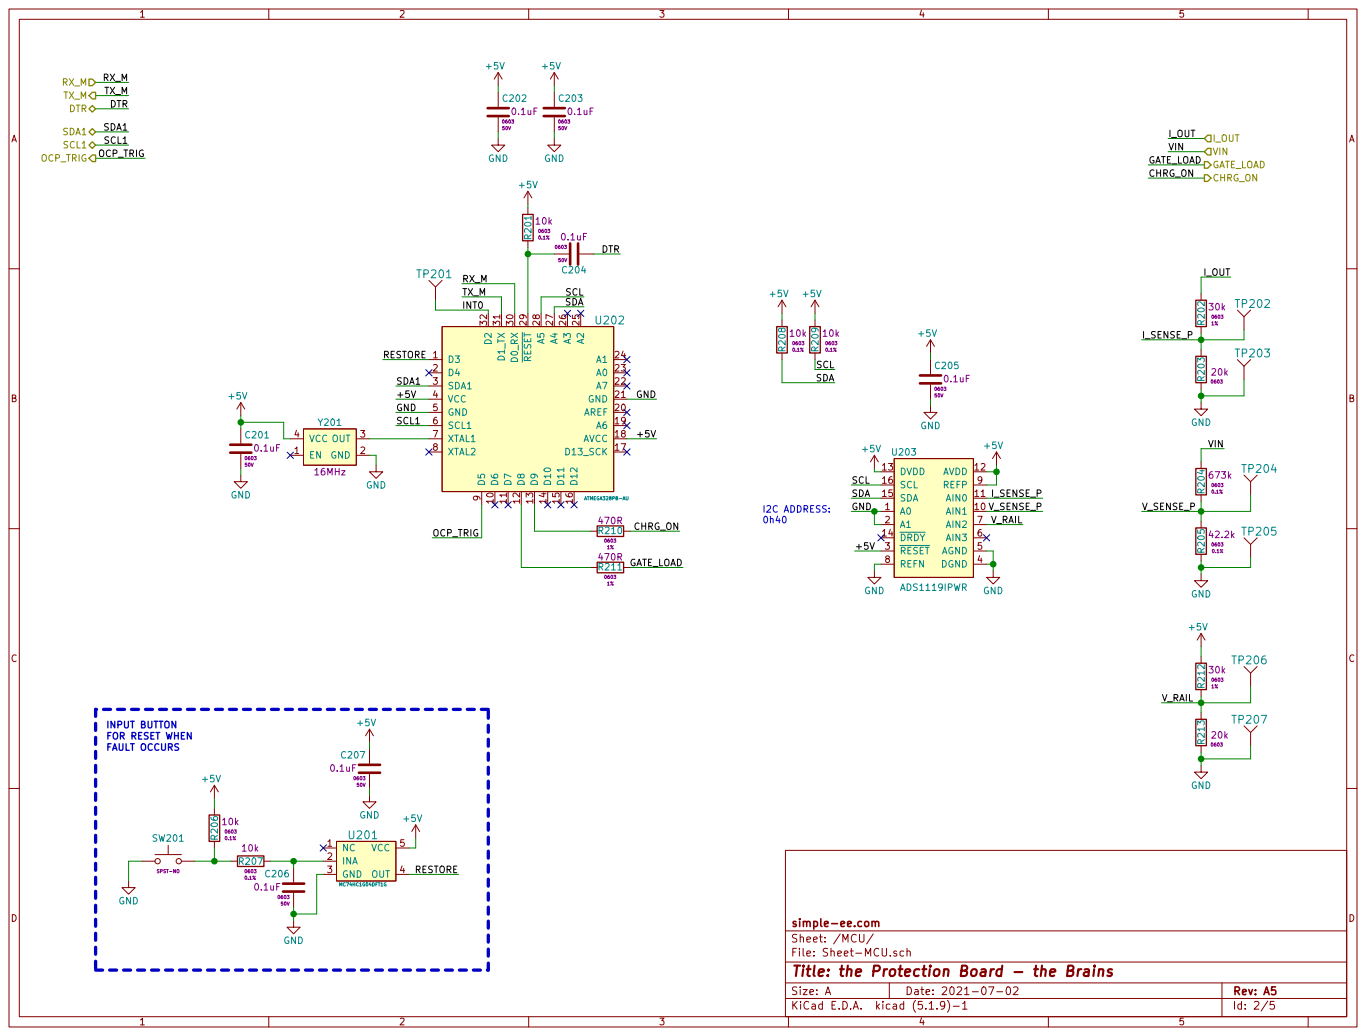
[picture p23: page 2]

INPUT BUTTON
FOR RESET WHEN FAULT OCCURS

File: Sheet-MCU.sch Sheet: /MCU/ simple-ee.com

Id: 2/5 Title: the Protection Board - the Brains

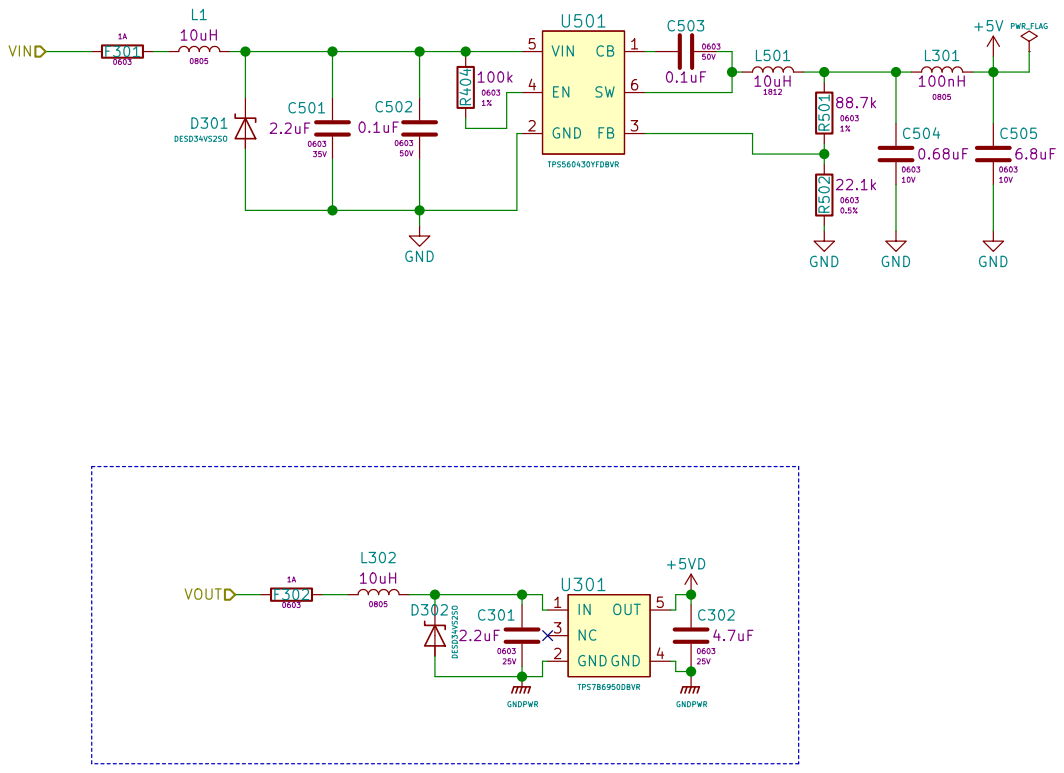
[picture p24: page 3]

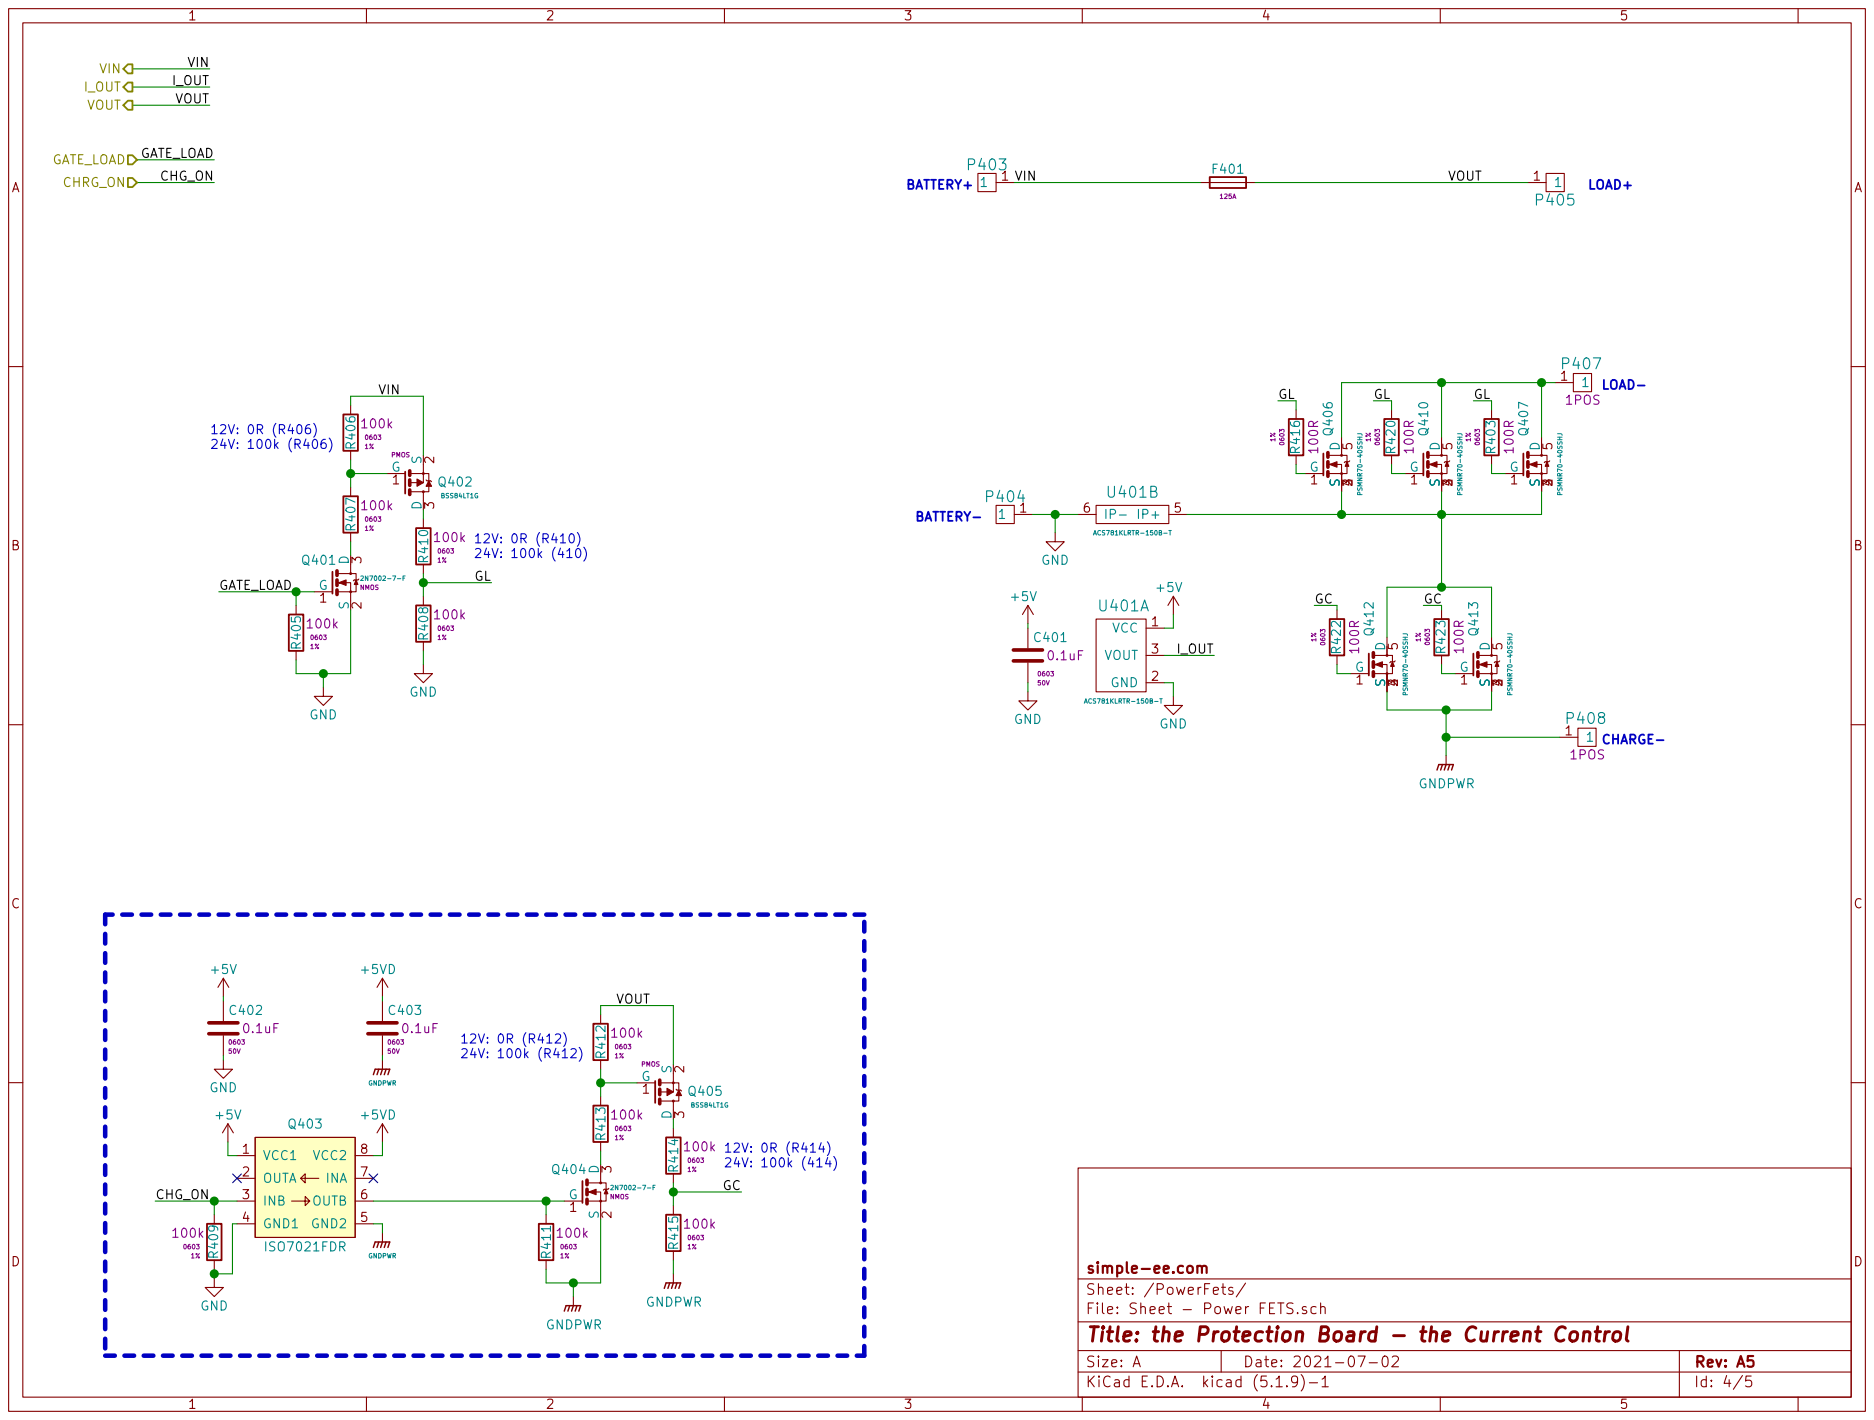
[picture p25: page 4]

Id: 4/5 Title: the Protection Board - the Current Control File: Sheet - Power FETS.sch Sheet: /PowerFets/ simple-ee.com

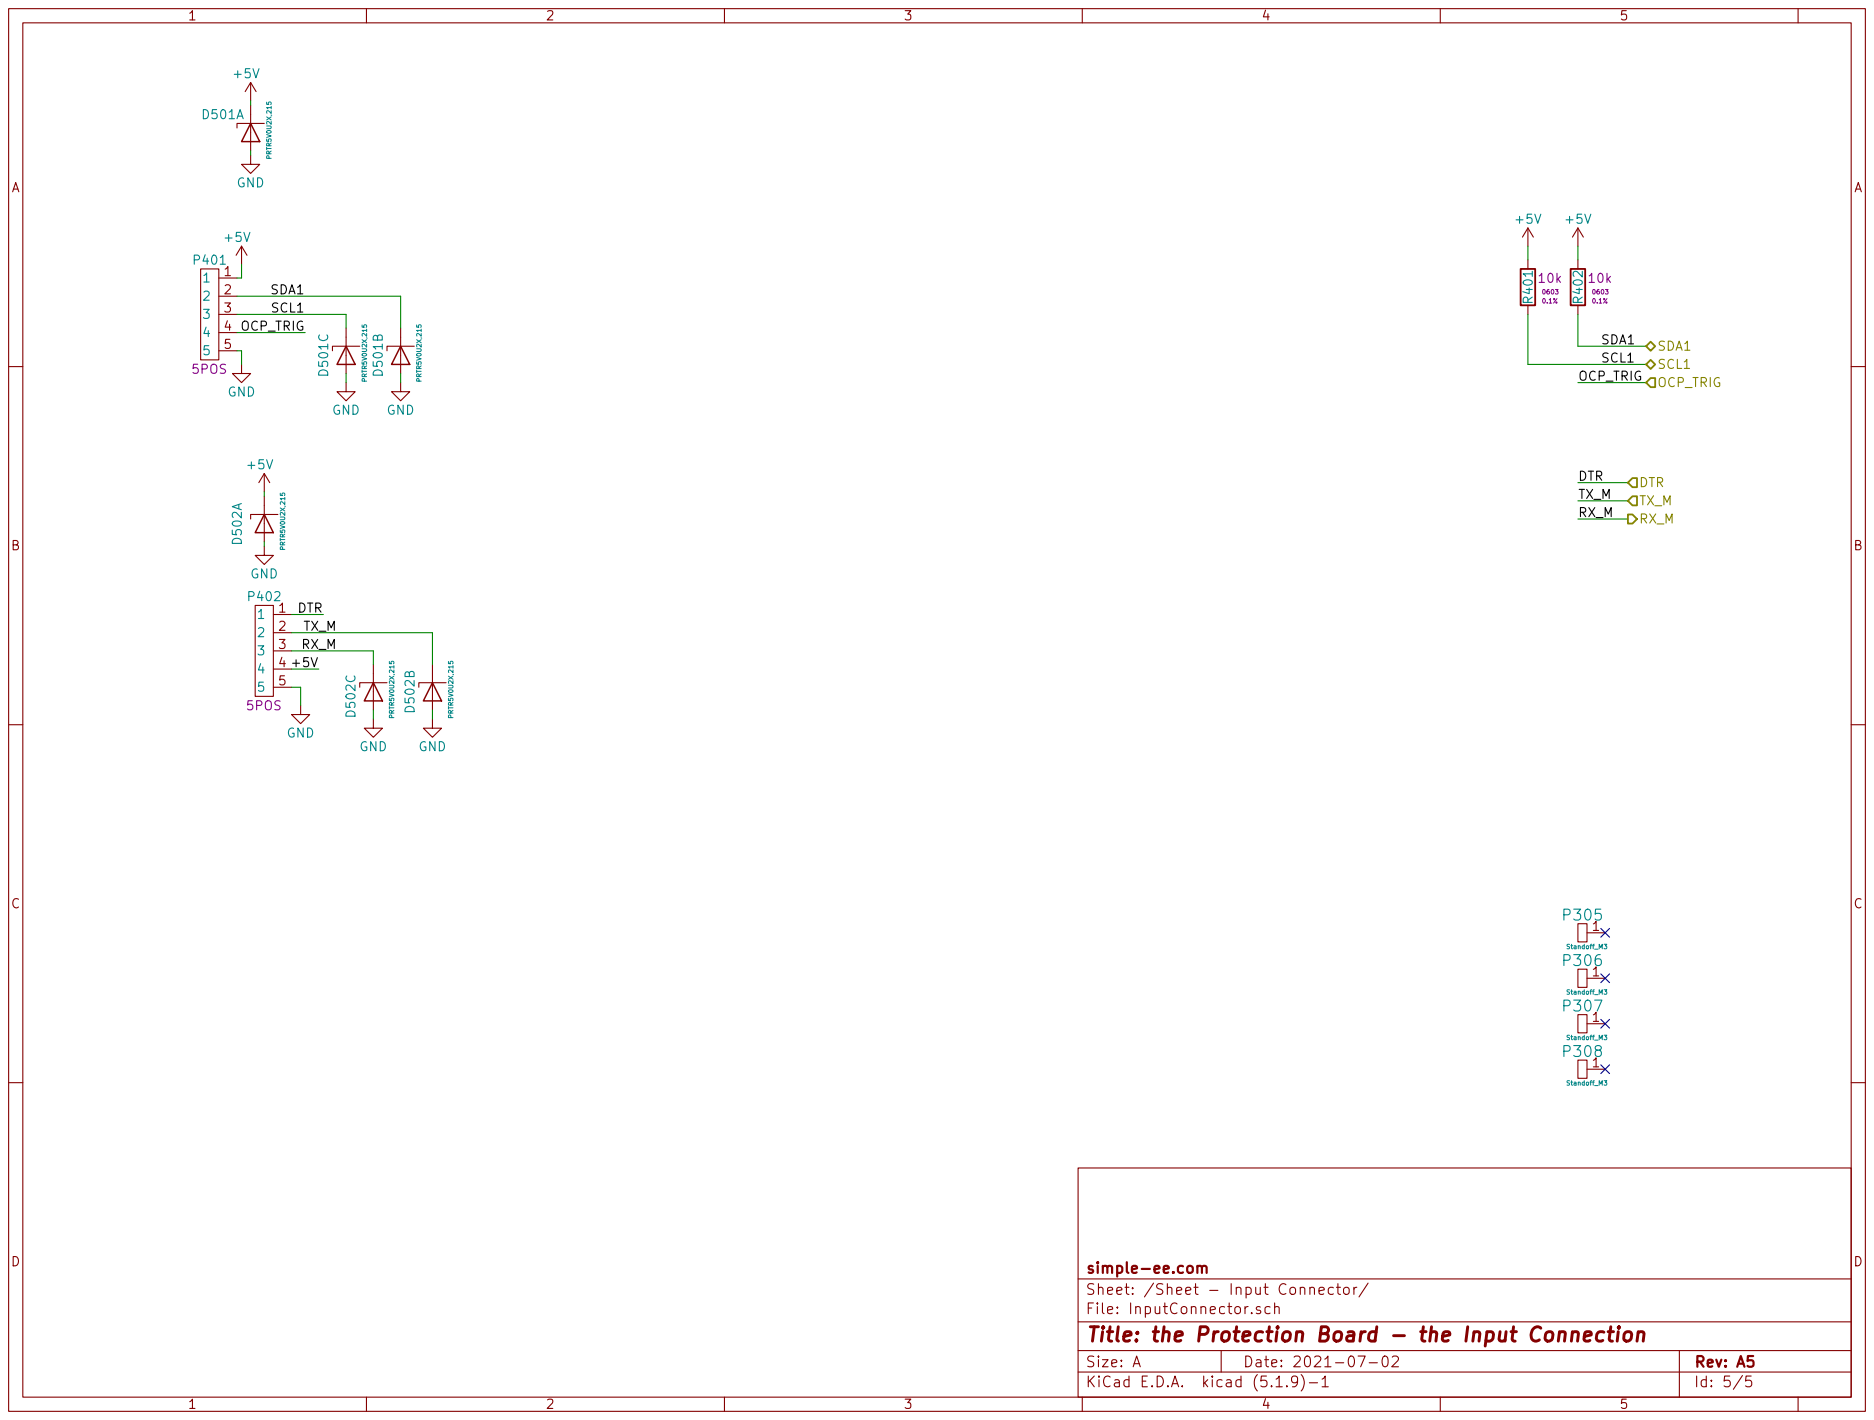
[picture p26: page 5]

simple-ee.com
Sheet: /Sheet - Input Connector/
File: InputConnector.sch
Id: 5/5 Title: the Protection Board - the Input Connection

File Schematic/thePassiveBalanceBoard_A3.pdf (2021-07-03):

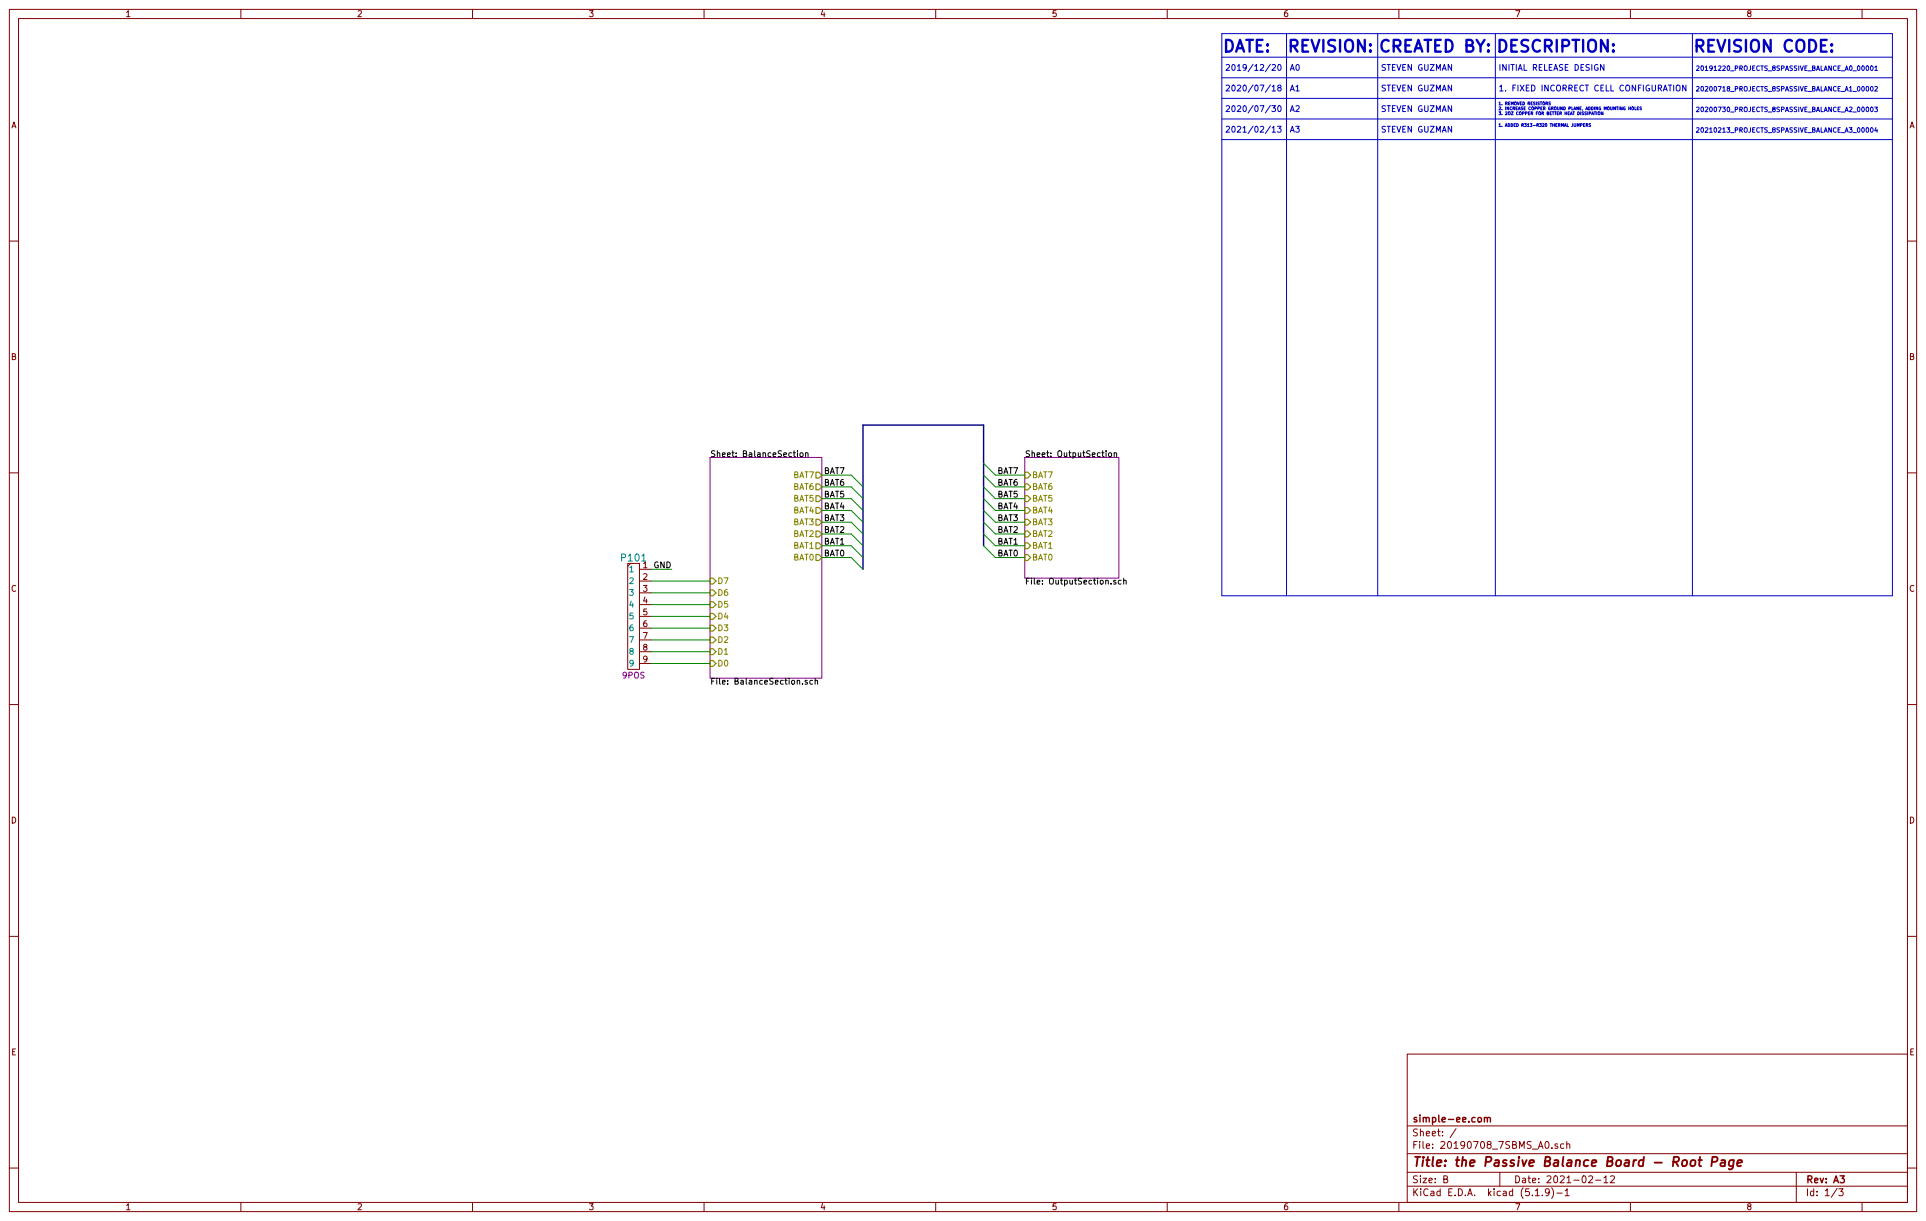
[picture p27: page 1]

3. 2OZ COPPER FOR BETTER HEAT DISSIPATION STEVEN GUZMAN

1. REMOVED RESISTORS
2. INCREASE COPPER GROUND PLANE, ADDING MOUNTING HOLES

File: 20190708_7SBMS_A0.sch Sheet: / simple-ee.com

Id: 1/3 Title: the Passive Balance Board - Root Page

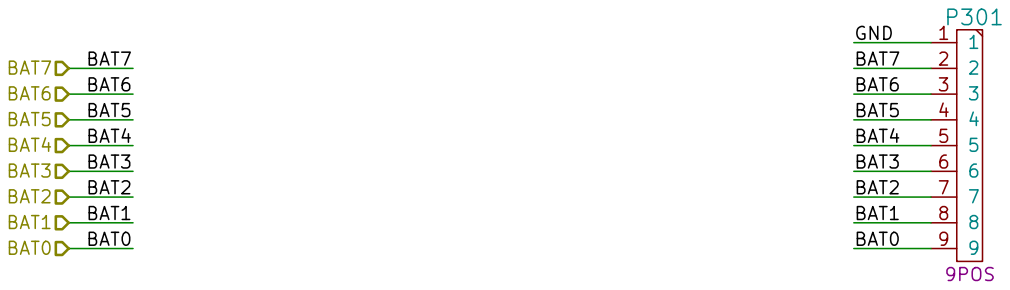
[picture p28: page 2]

simple-ee.com
Sheet: /OutputSection/
File: OutputSection.sch
Id: 2/3 Title: the Passive Balance Board - the Output Connector

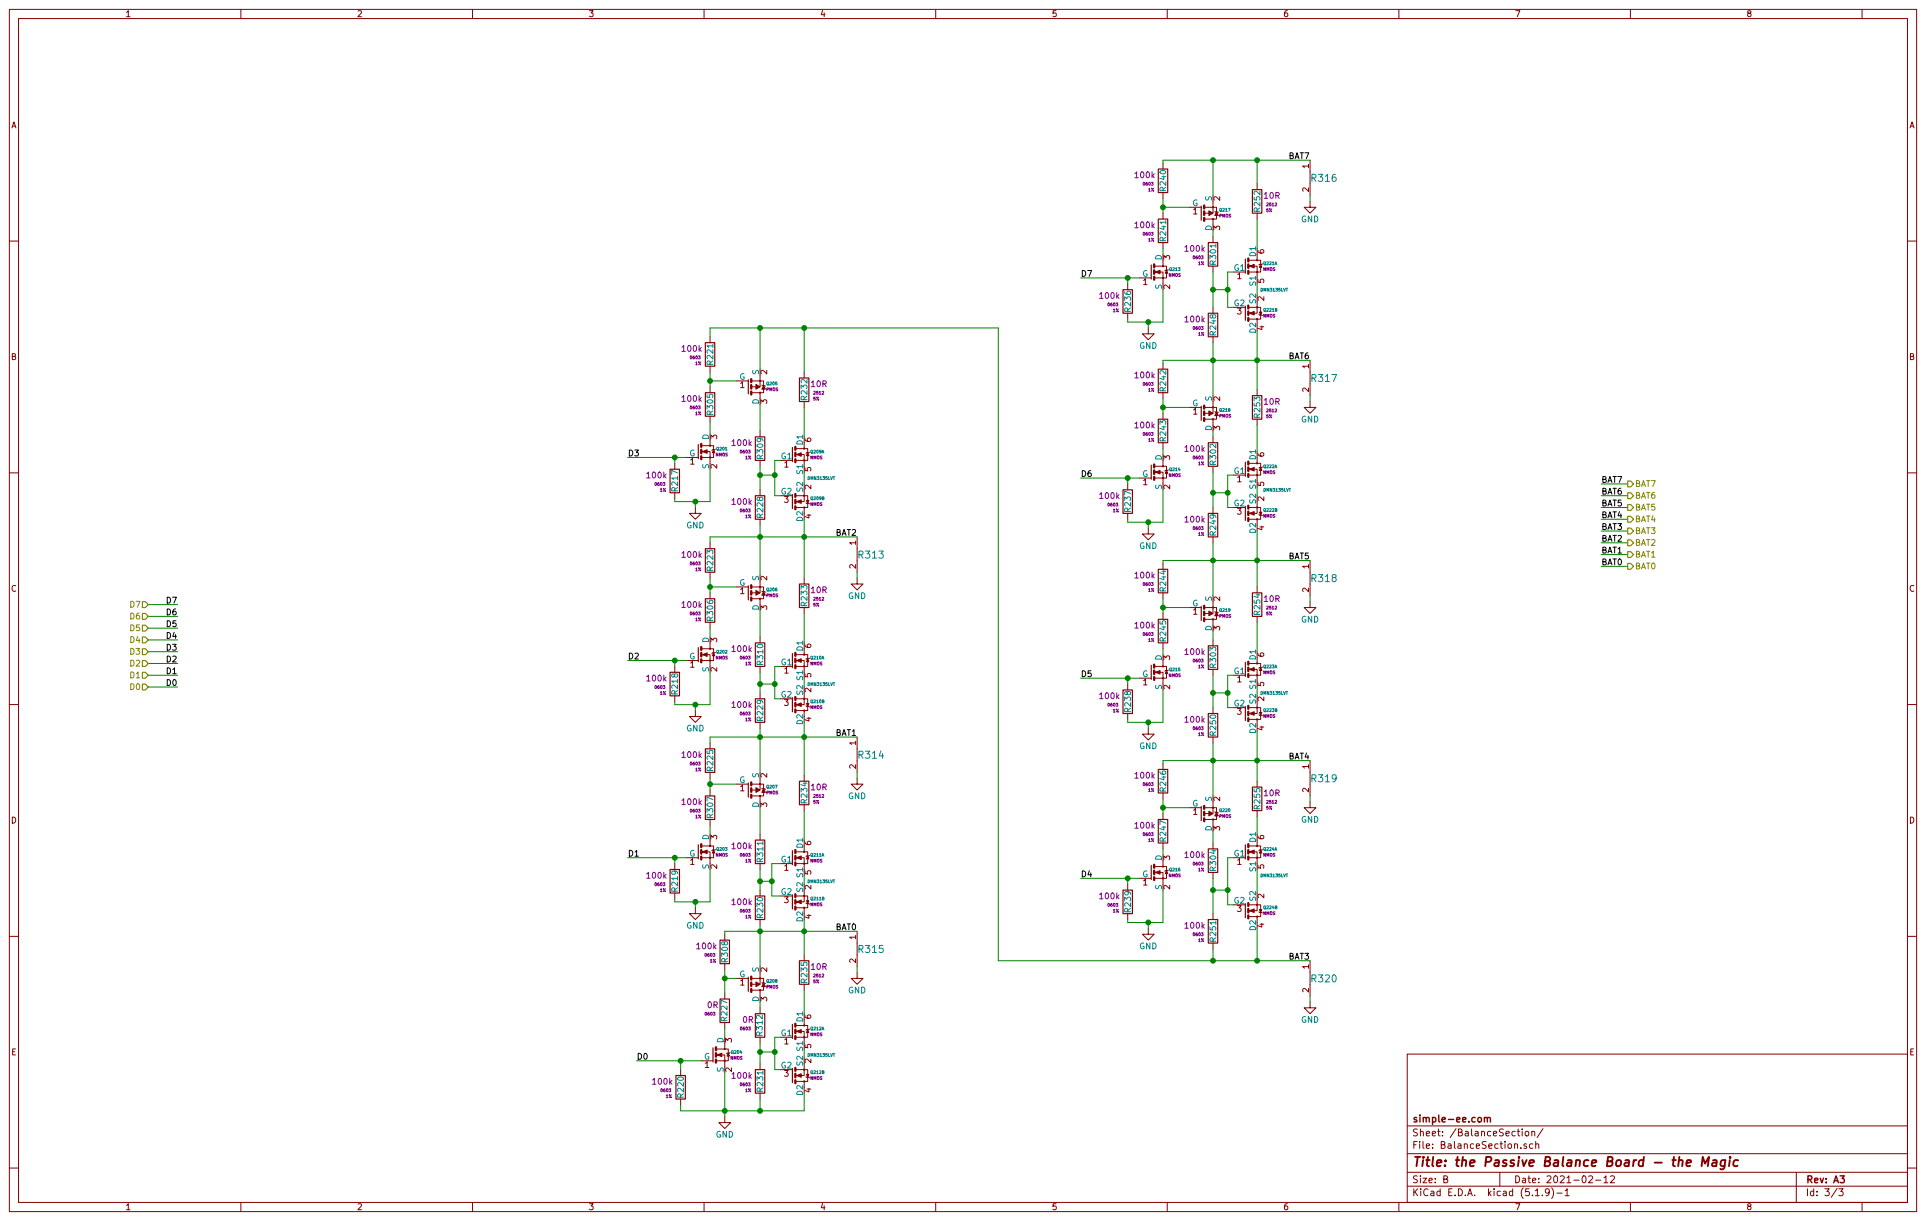
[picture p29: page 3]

File: BalanceSection.sch Sheet: /BalanceSection/ simple-ee.com G1 S2 D3 Q202 NMOS R307100k

Id: 3/3 Title: the Passive Balance Board - the Magic

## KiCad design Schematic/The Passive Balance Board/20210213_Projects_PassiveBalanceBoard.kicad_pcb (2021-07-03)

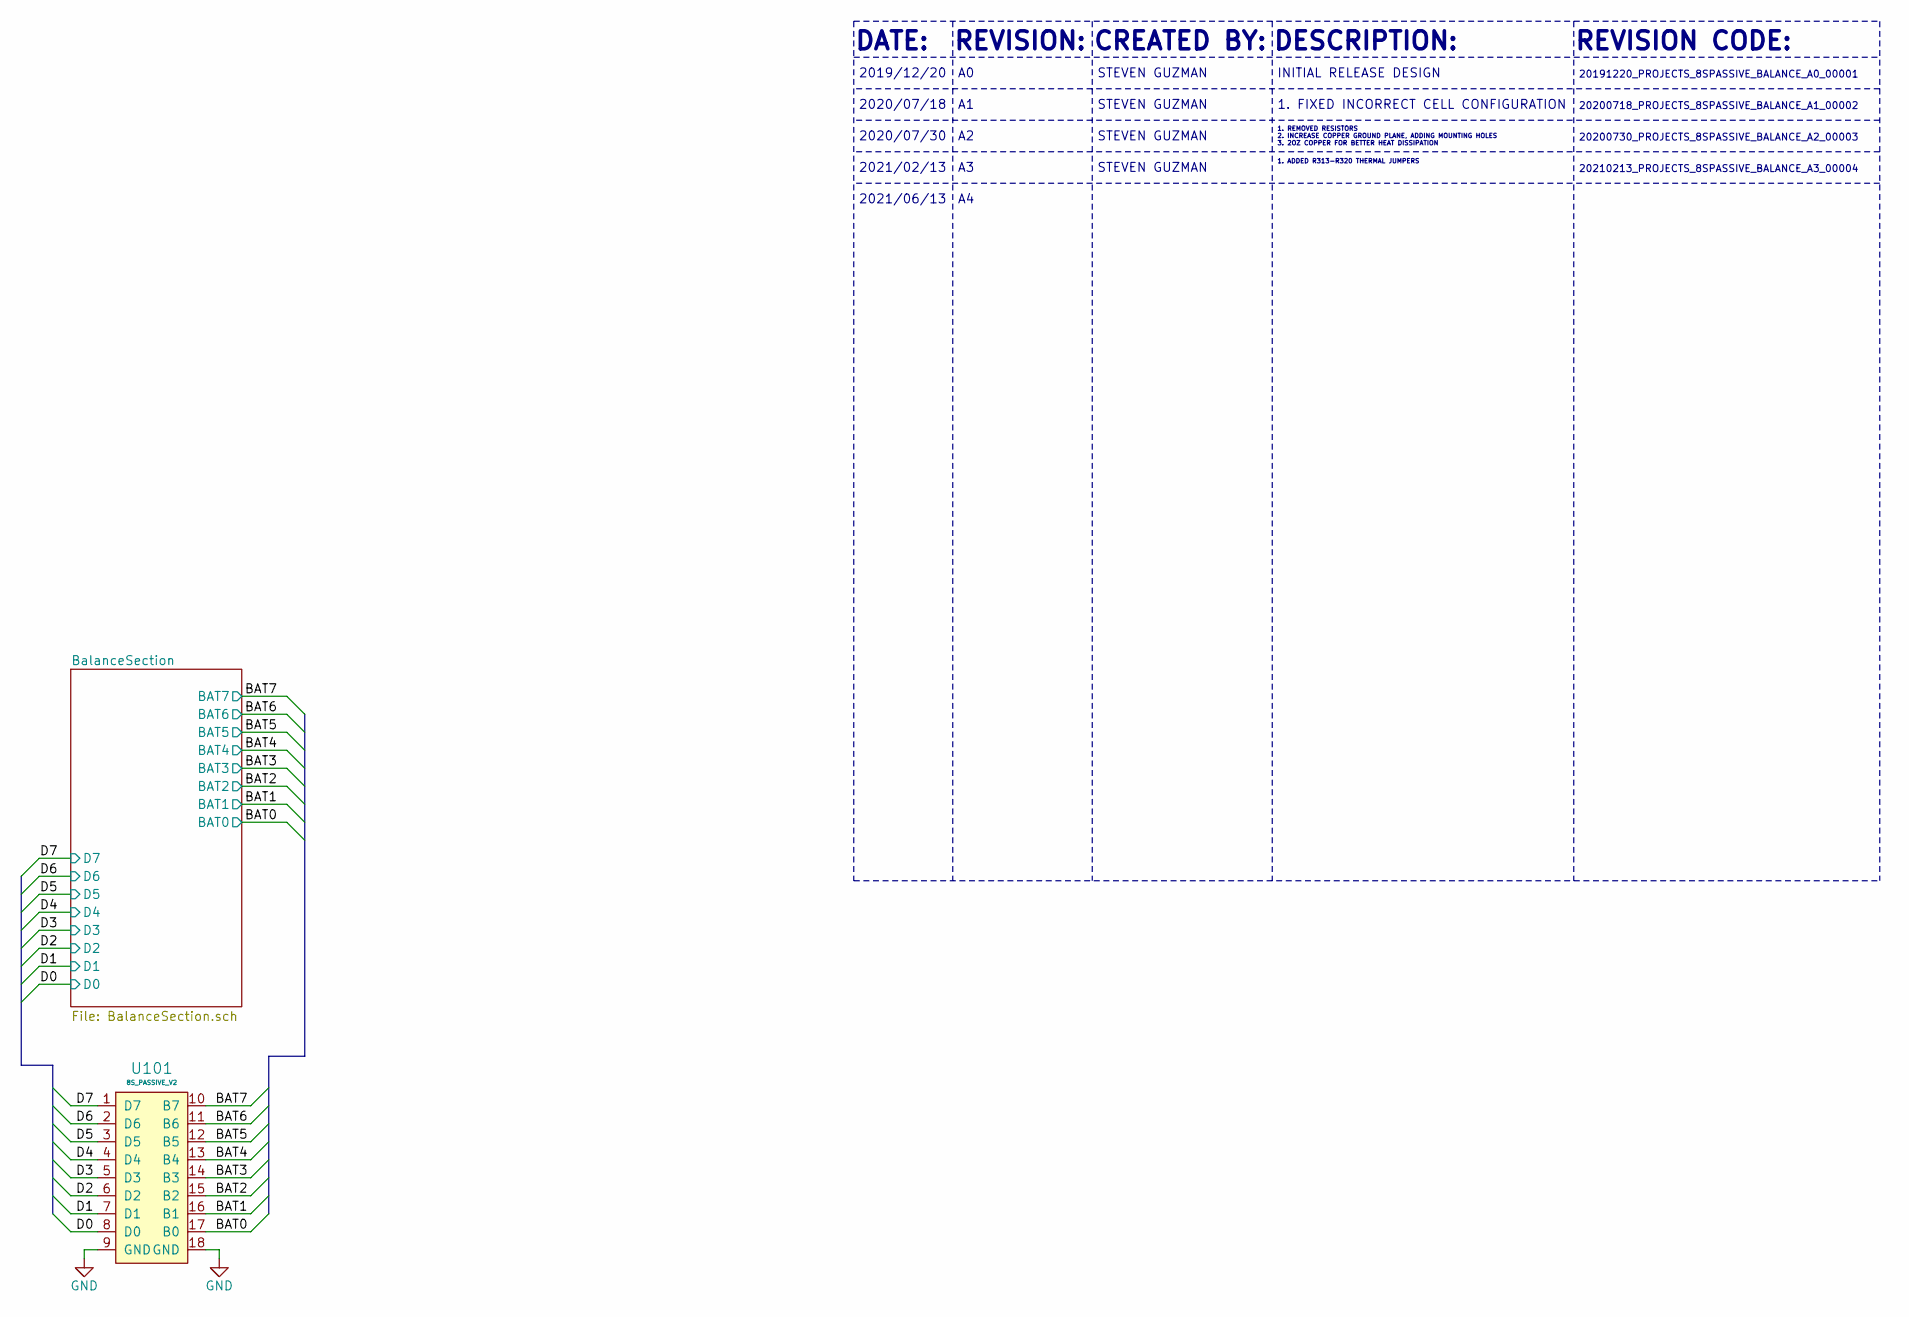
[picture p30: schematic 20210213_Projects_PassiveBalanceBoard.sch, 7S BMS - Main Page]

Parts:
U101: 8S_PASSIVE_V2

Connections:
/BAT0: U101.17 (B0); also elsewhere on the board
/BAT1: U101.16 (B1); also elsewhere on the board
/BAT2: U101.15 (B2); also elsewhere on the board
/BAT3: U101.14 (B3); also elsewhere on the board
/BAT4: U101.13 (B4); also elsewhere on the board
/BAT5: U101.12 (B5); also elsewhere on the board
/BAT6: U101.11 (B6); also elsewhere on the board
/BAT7: U101.10 (B7); also elsewhere on the board
/D0: U101.8 (D0); also elsewhere on the board
/D1: U101.7 (D1); also elsewhere on the board
/D2: U101.6 (D2); also elsewhere on the board
/D3: U101.5 (D3); also elsewhere on the board
/D4: U101.4 (D4); also elsewhere on the board
/D5: U101.3 (D5); also elsewhere on the board
/D6: U101.2 (D6); also elsewhere on the board
/D7: U101.1 (D7); also elsewhere on the board
GND: U101.9 (GND), U101.18 (GND); also elsewhere on the board

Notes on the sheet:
DATE:
DESCRIPTION:
REVISION:
REVISION CODE:
2019/12/20
CREATED BY:
STEVEN GUZMAN
INITIAL RELEASE DESIGN
20191220_PROJECTS_8SPASSIVE_BALANCE_A0_00001
2020/07/18
1. FIXED INCORRECT CELL CONFIGURATION
20200718_PROJECTS_8SPASSIVE_BALANCE_A1_00002
2020/07/30
1. REMOVED RESISTORS 2. INCREASE COPPER GROUND PLANE, ADDING MOUNTING HOLES 3. 2OZ COPPER FOR BETTER HEAT DISSIPATION
20200730_PROJECTS_8SPASSIVE_BALANCE_A2_00003
2021/02/13
1. ADDED R313-R320 THERMAL JUMPERS
20210213_PROJECTS_8SPASSIVE_BALANCE_A3_00004
2021/06/13

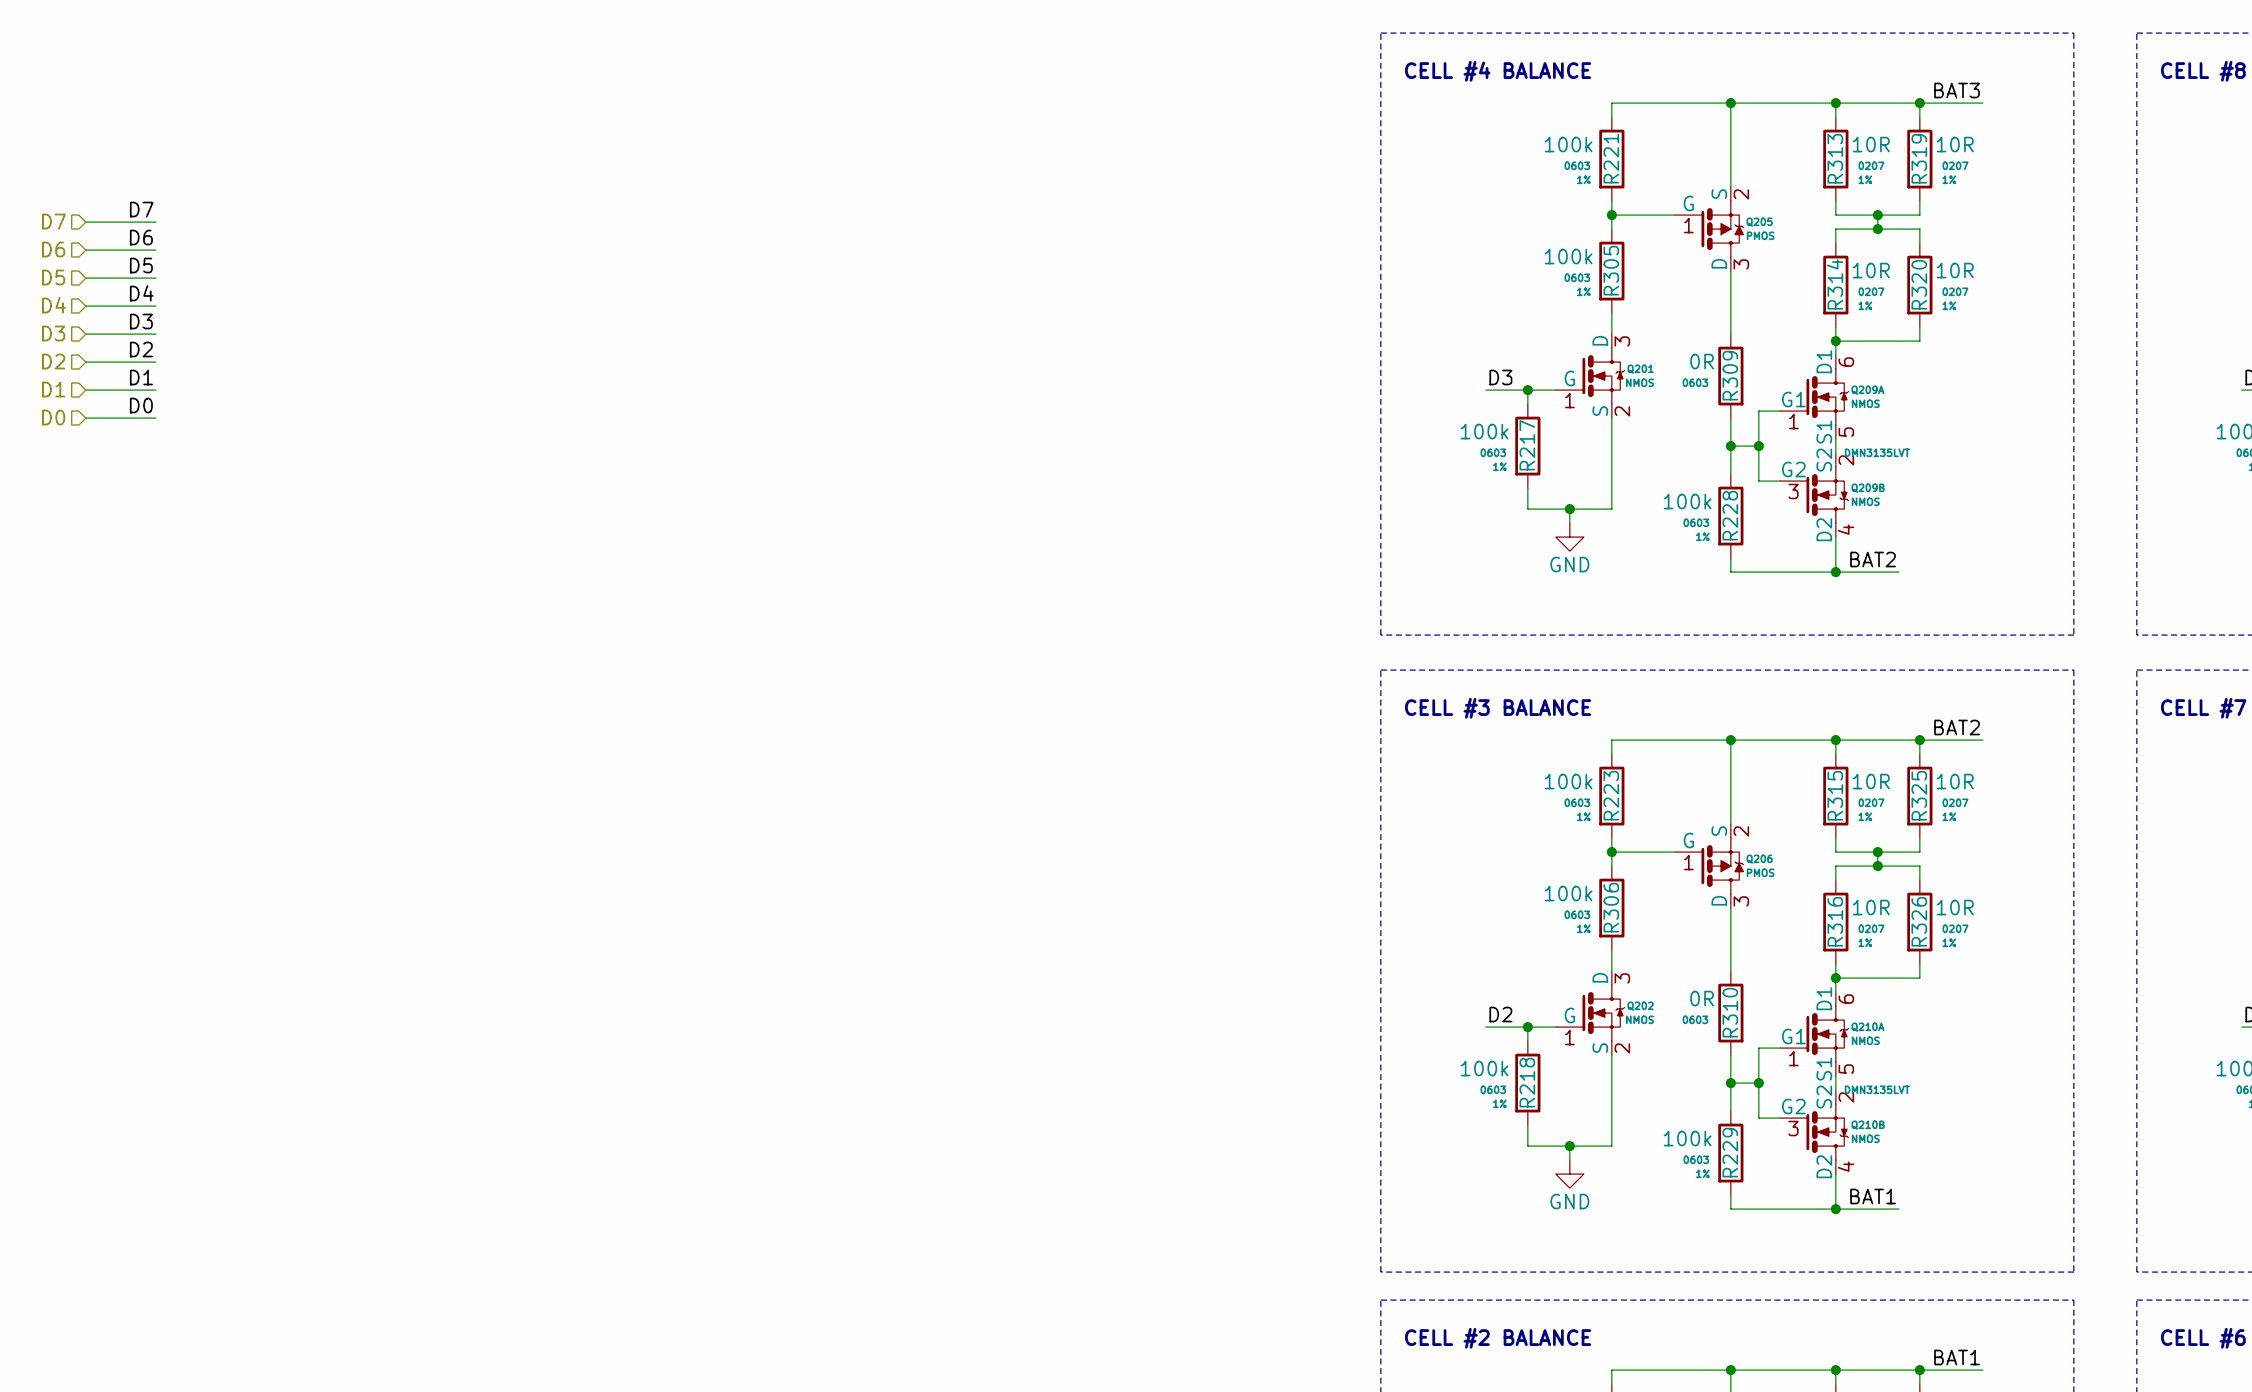
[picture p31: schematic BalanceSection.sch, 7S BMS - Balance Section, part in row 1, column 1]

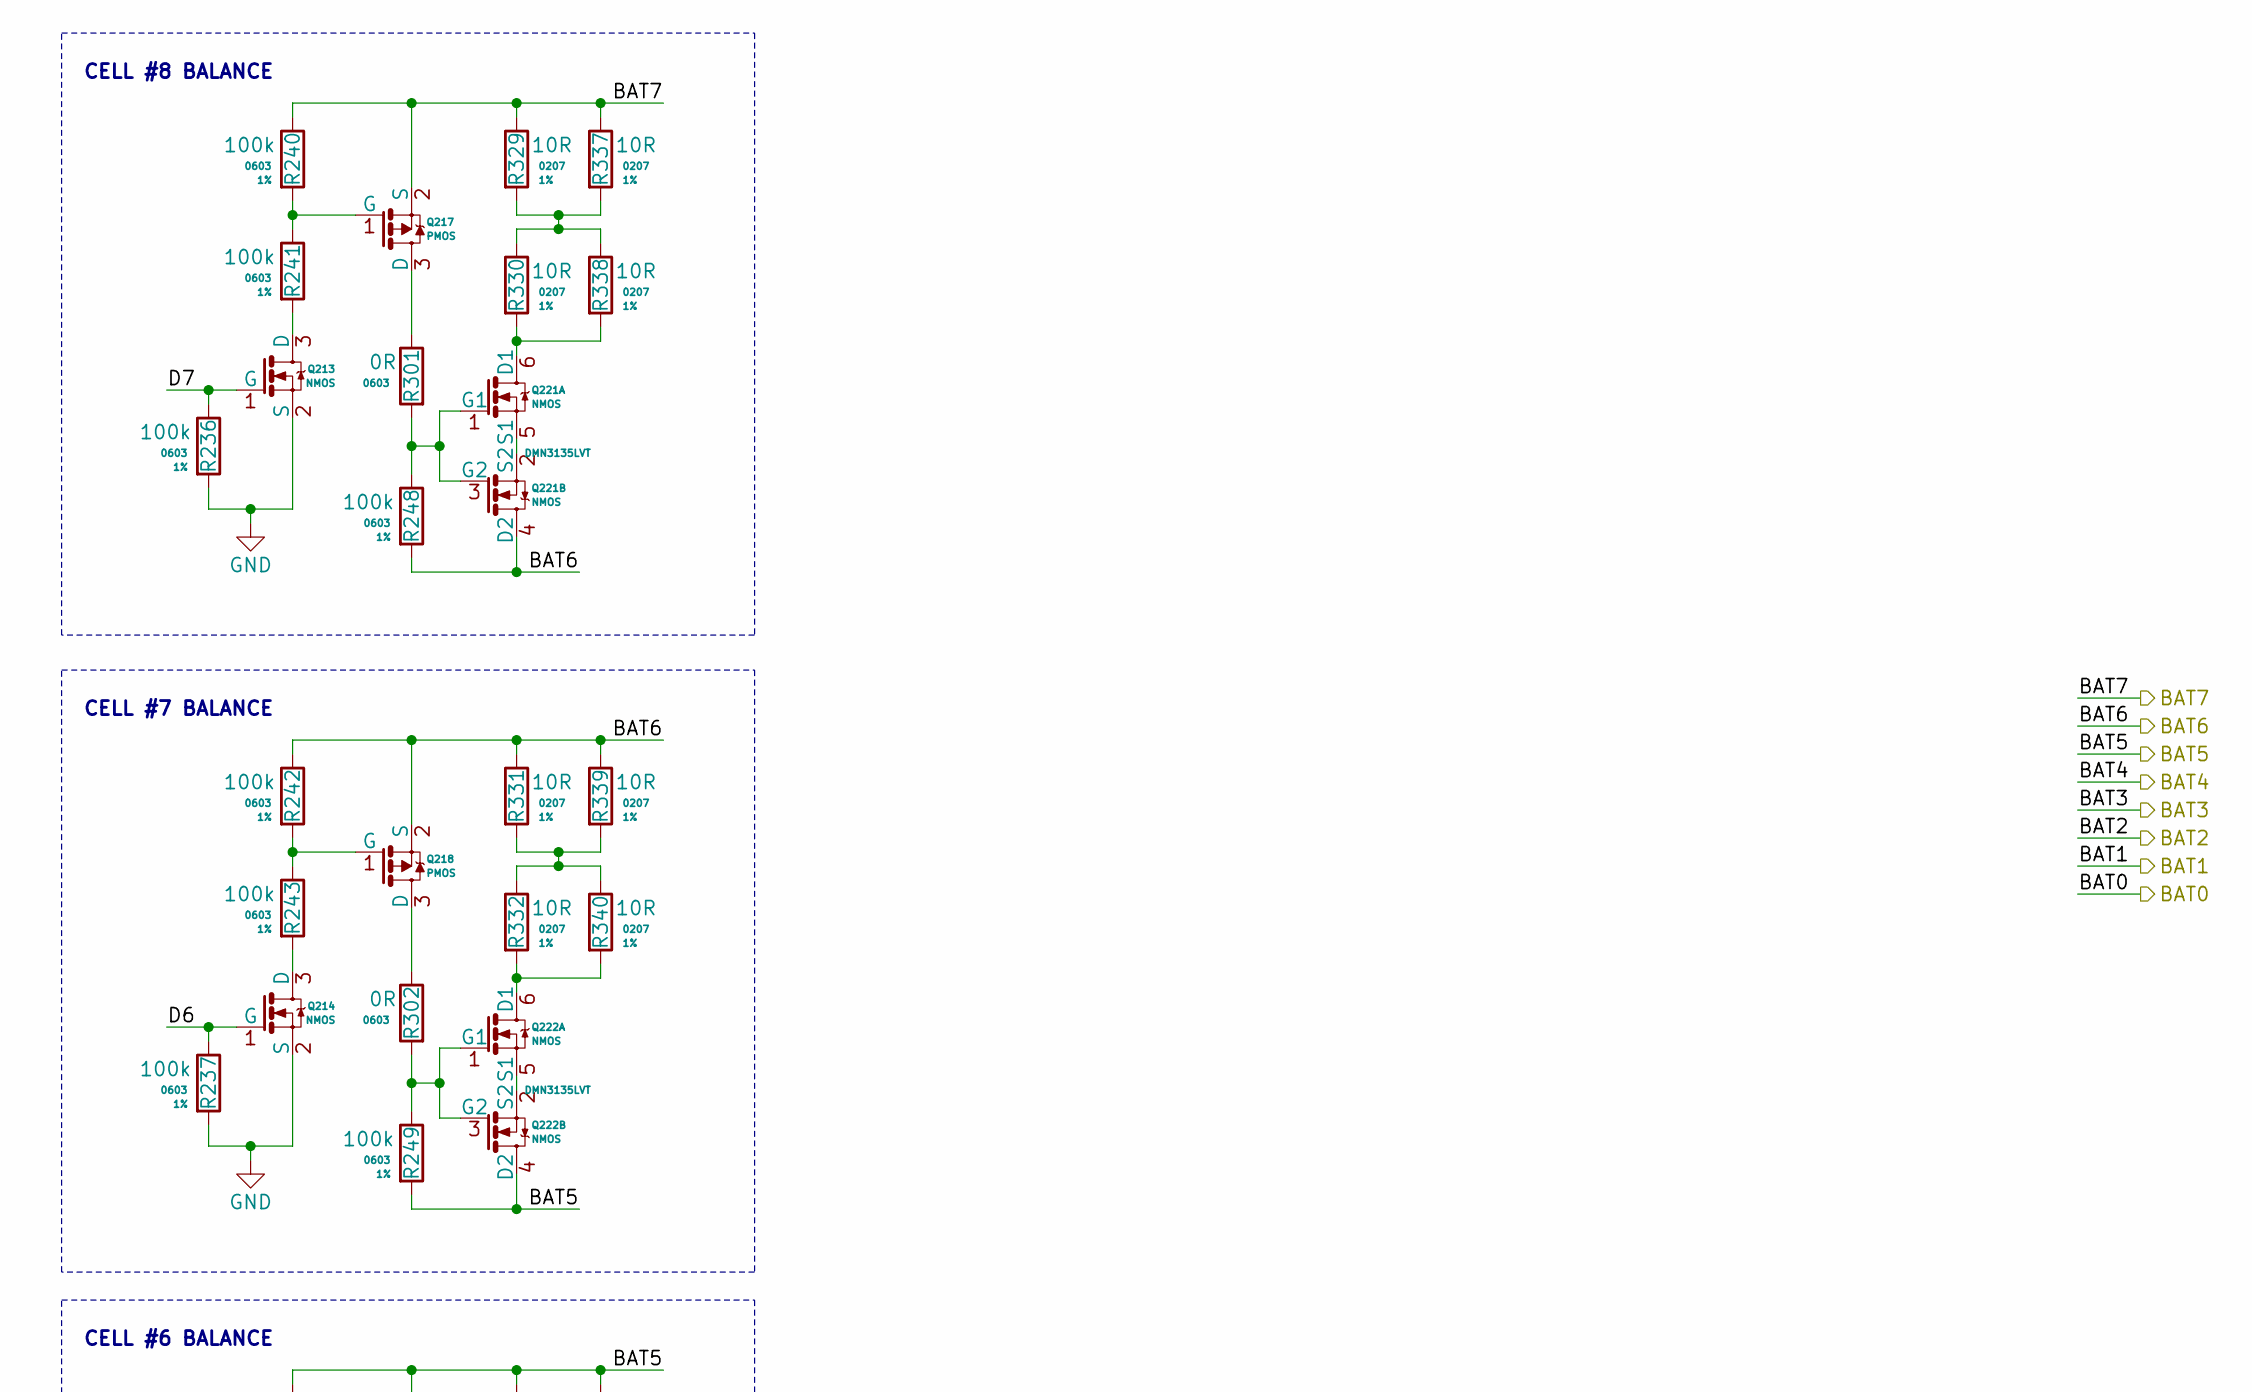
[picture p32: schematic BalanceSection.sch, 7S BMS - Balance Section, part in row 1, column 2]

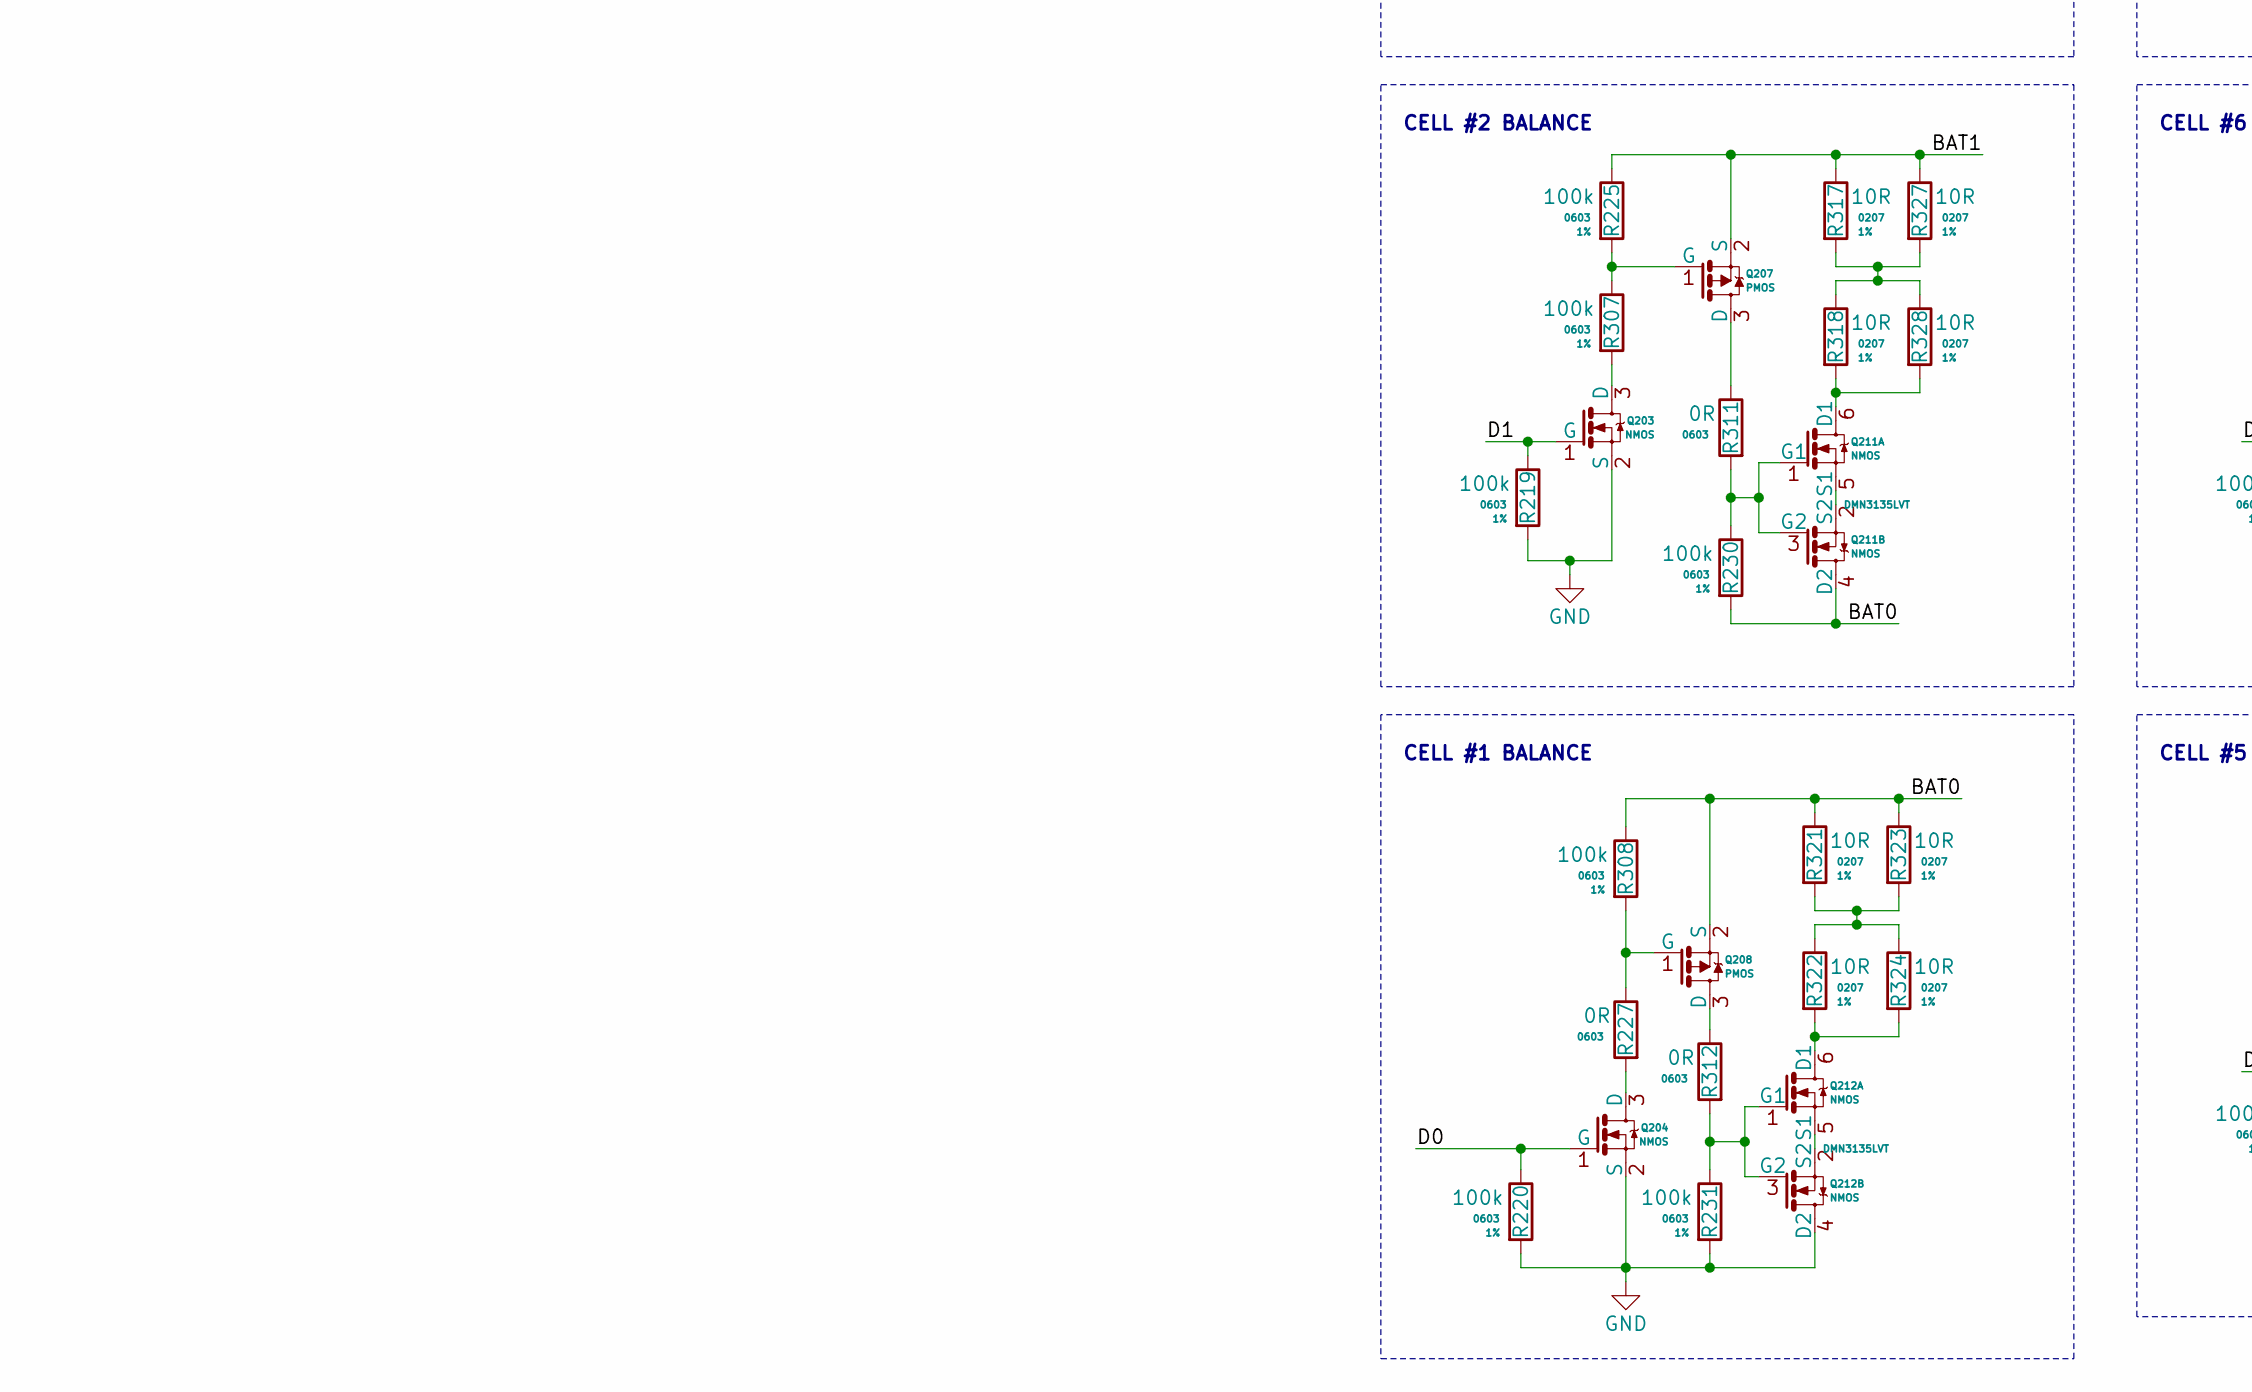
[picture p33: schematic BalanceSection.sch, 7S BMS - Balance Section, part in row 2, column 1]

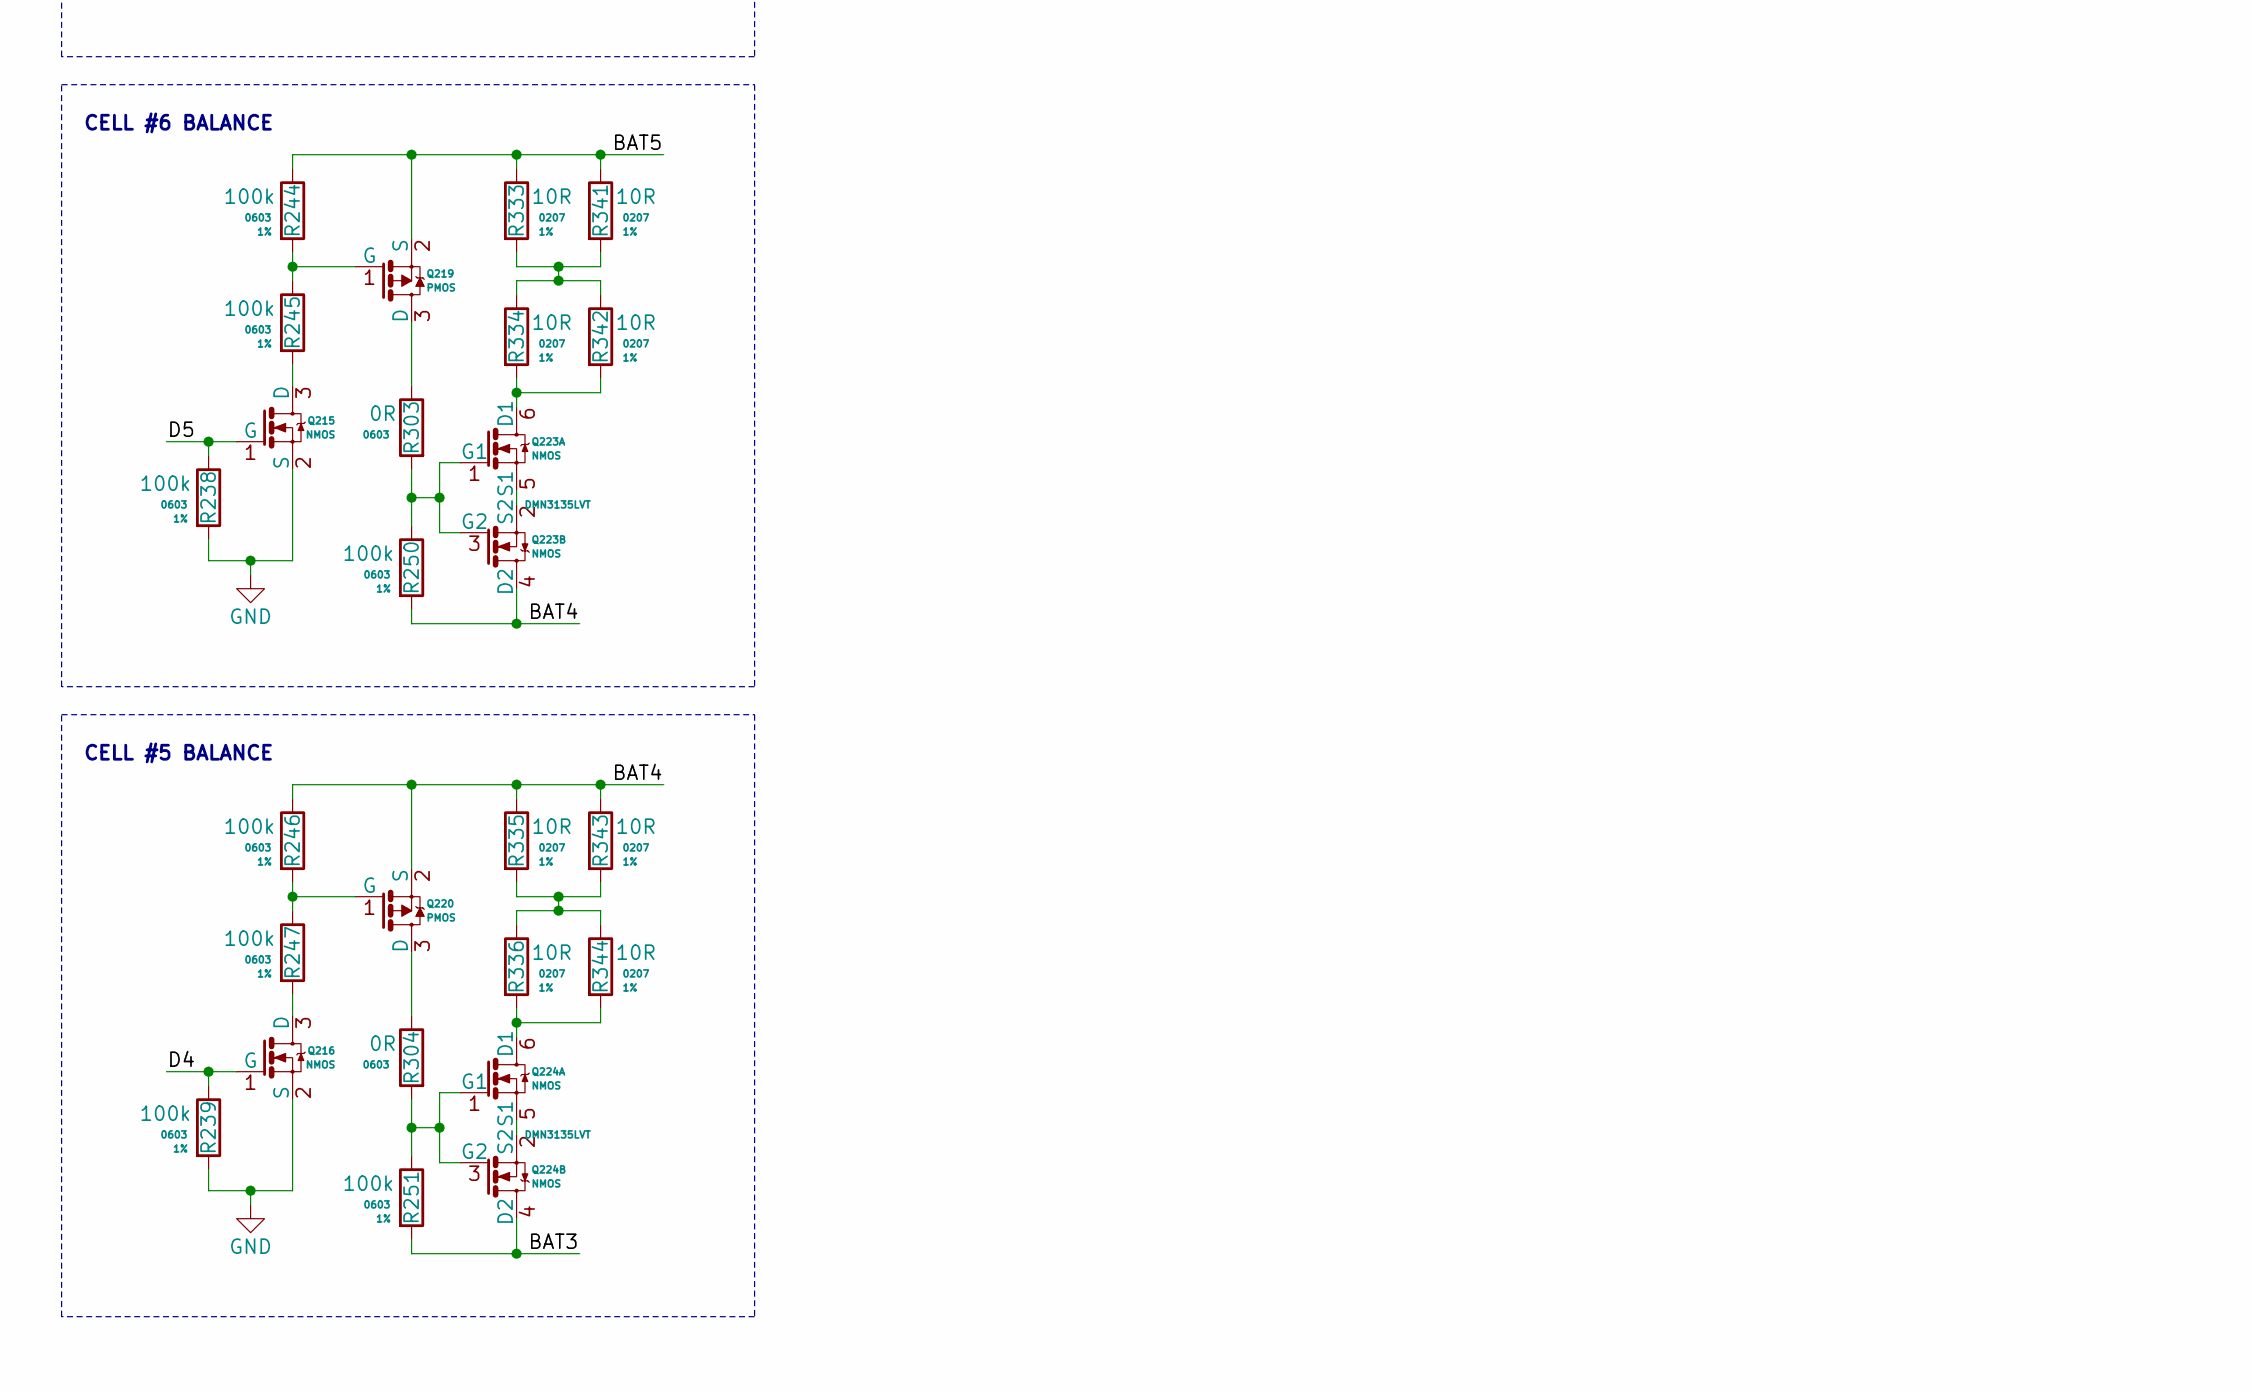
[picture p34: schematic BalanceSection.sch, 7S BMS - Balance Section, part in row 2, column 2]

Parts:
Q201, Q202, Q203, Q204, Q213, Q214, Q215, Q216: 2N7002-7-F; SOT-23-3
Q205, Q206, Q207, Q208, Q217, Q218, Q219, Q220: BSS84LT1G; SOT-23-3
Q209, Q210, Q211, Q212, Q221, Q222, Q223, Q224: DMN3135LVT; SOT-23-6
R217, R218, R219, R220, R221, R223, R225, R228, R229, R230, R231, R236, R237, R238, R239, R240, R241, R242, R243, R244, R245, R246, R247, R248, R249, R250, R251, R305, R306, R307, R308: CPF0603F100KC1; R_0603_Handsolder
R227, R301, R302, R303, R304, R309, R310, R311, R312: RMCF0603ZT0R00; R_0603_Handsolder
R313, R314, R315, R316, R317, R318, R319, R320, R321, R322, R323, R324, R325, R326, R327, R328, R329, R330, R331, R332, R333, R334, R335, R336, R337, R338, R339, R340, R341, R342, R343, R344: MLFA1FTC10R0; R_MELF_0207

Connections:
/BAT0: Q208.2 (S), Q211.4 (D2), R230.2, R308.1, R321.1, R323.1; also elsewhere on the board
/BAT1: Q207.2 (S), Q210.4 (D2), R225.1, R229.2, R317.1, R327.1; also elsewhere on the board
/BAT2: Q206.2 (S), Q209.4 (D2), R223.1, R228.2, R315.1, R325.1; also elsewhere on the board
/BAT3: Q205.2 (S), Q224.4 (D2), R221.1, R251.2, R313.1, R319.1; also elsewhere on the board
/BAT4: Q220.2 (S), Q223.4 (D2), R246.1, R250.2, R335.1, R343.1; also elsewhere on the board
/BAT5: Q219.2 (S), Q222.4 (D2), R244.1, R249.2, R333.1, R341.1; also elsewhere on the board
/BAT6: Q218.2 (S), Q221.4 (D2), R242.1, R248.2, R331.1, R339.1; also elsewhere on the board
/BAT7: Q217.2 (S), R240.1, R329.1, R337.1; also elsewhere on the board
/D0: Q204.1 (G), R220.1; also elsewhere on the board
/D1: Q203.1 (G), R219.1; also elsewhere on the board
/D2: Q202.1 (G), R218.1; also elsewhere on the board
/D3: Q201.1 (G), R217.1; also elsewhere on the board
/D4: Q216.1 (G), R239.1; also elsewhere on the board
/D5: Q215.1 (G), R238.1; also elsewhere on the board
/D6: Q214.1 (G), R237.1; also elsewhere on the board
/D7: Q213.1 (G), R236.1; also elsewhere on the board
GND: Q201.2 (S), Q202.2 (S), Q203.2 (S), Q204.2 (S), Q212.4 (D2), Q213.2 (S), Q214.2 (S), Q215.2 (S), Q216.2 (S), R217.2, R218.2, R219.2, R220.2, R231.2, R236.2, R237.2, R238.2, R239.2; also elsewhere on the board
unnamed: Q201.3 (D), R305.2
unnamed: Q202.3 (D), R306.2
unnamed: Q203.3 (D), R307.2
unnamed: Q204.3 (D), R227.2
unnamed: Q205.1 (G), R221.2, R305.1
unnamed: Q205.3 (D), R309.1
unnamed: Q206.1 (G), R223.2, R306.1
unnamed: Q206.3 (D), R310.1
unnamed: Q207.1 (G), R225.2, R307.1
unnamed: Q207.3 (D), R311.1
unnamed: Q208.1 (G), R227.1, R308.2
unnamed: Q208.3 (D), R312.1
unnamed: Q209.1 (G1), Q209.3 (G2), R228.1, R309.2
unnamed: Q209.2 (S2), Q209.5 (S1)
unnamed: Q209.6 (D1), R314.2, R320.2
unnamed: Q210.1 (G1), Q210.3 (G2), R229.1, R310.2
unnamed: Q210.2 (S2), Q210.5 (S1)
unnamed: Q210.6 (D1), R316.2, R326.2
unnamed: Q211.1 (G1), Q211.3 (G2), R230.1, R311.2
unnamed: Q211.2 (S2), Q211.5 (S1)
unnamed: Q211.6 (D1), R318.2, R328.2
unnamed: Q212.1 (G1), Q212.3 (G2), R231.1, R312.2
unnamed: Q212.2 (S2), Q212.5 (S1)
unnamed: Q212.6 (D1), R322.2, R324.2
unnamed: Q213.3 (D), R241.2
unnamed: Q214.3 (D), R243.2
unnamed: Q215.3 (D), R245.2
unnamed: Q216.3 (D), R247.2
unnamed: Q217.1 (G), R240.2, R241.1
unnamed: Q217.3 (D), R301.1
unnamed: Q218.1 (G), R242.2, R243.1
unnamed: Q218.3 (D), R302.1
unnamed: Q219.1 (G), R244.2, R245.1
unnamed: Q219.3 (D), R303.1
unnamed: Q220.1 (G), R246.2, R247.1
unnamed: Q220.3 (D), R304.1
unnamed: Q221.1 (G1), Q221.3 (G2), R248.1, R301.2
unnamed: Q221.2 (S2), Q221.5 (S1)
unnamed: Q221.6 (D1), R330.2, R338.2
unnamed: Q222.1 (G1), Q222.3 (G2), R249.1, R302.2
unnamed: Q222.2 (S2), Q222.5 (S1)
unnamed: Q222.6 (D1), R332.2, R340.2
unnamed: Q223.1 (G1), Q223.3 (G2), R250.1, R303.2
unnamed: Q223.2 (S2), Q223.5 (S1)
unnamed: Q223.6 (D1), R334.2, R342.2
unnamed: Q224.1 (G1), Q224.3 (G2), R251.1, R304.2
unnamed: Q224.2 (S2), Q224.5 (S1)
unnamed: Q224.6 (D1), R336.2, R344.2
unnamed: R313.2, R314.1, R319.2, R320.1
unnamed: R315.2, R316.1, R325.2, R326.1
unnamed: R317.2, R318.1, R327.2, R328.1
unnamed: R321.2, R322.1, R323.2, R324.1
unnamed: R329.2, R330.1, R337.2, R338.1
unnamed: R331.2, R332.1, R339.2, R340.1
unnamed: R333.2, R334.1, R341.2, R342.1
unnamed: R335.2, R336.1, R343.2, R344.1

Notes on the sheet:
CELL #1 BALANCE
CELL #2 BALANCE
CELL #3 BALANCE
CELL #4 BALANCE
CELL #5 BALANCE
CELL #6 BALANCE
CELL #7 BALANCE
CELL #8 BALANCE

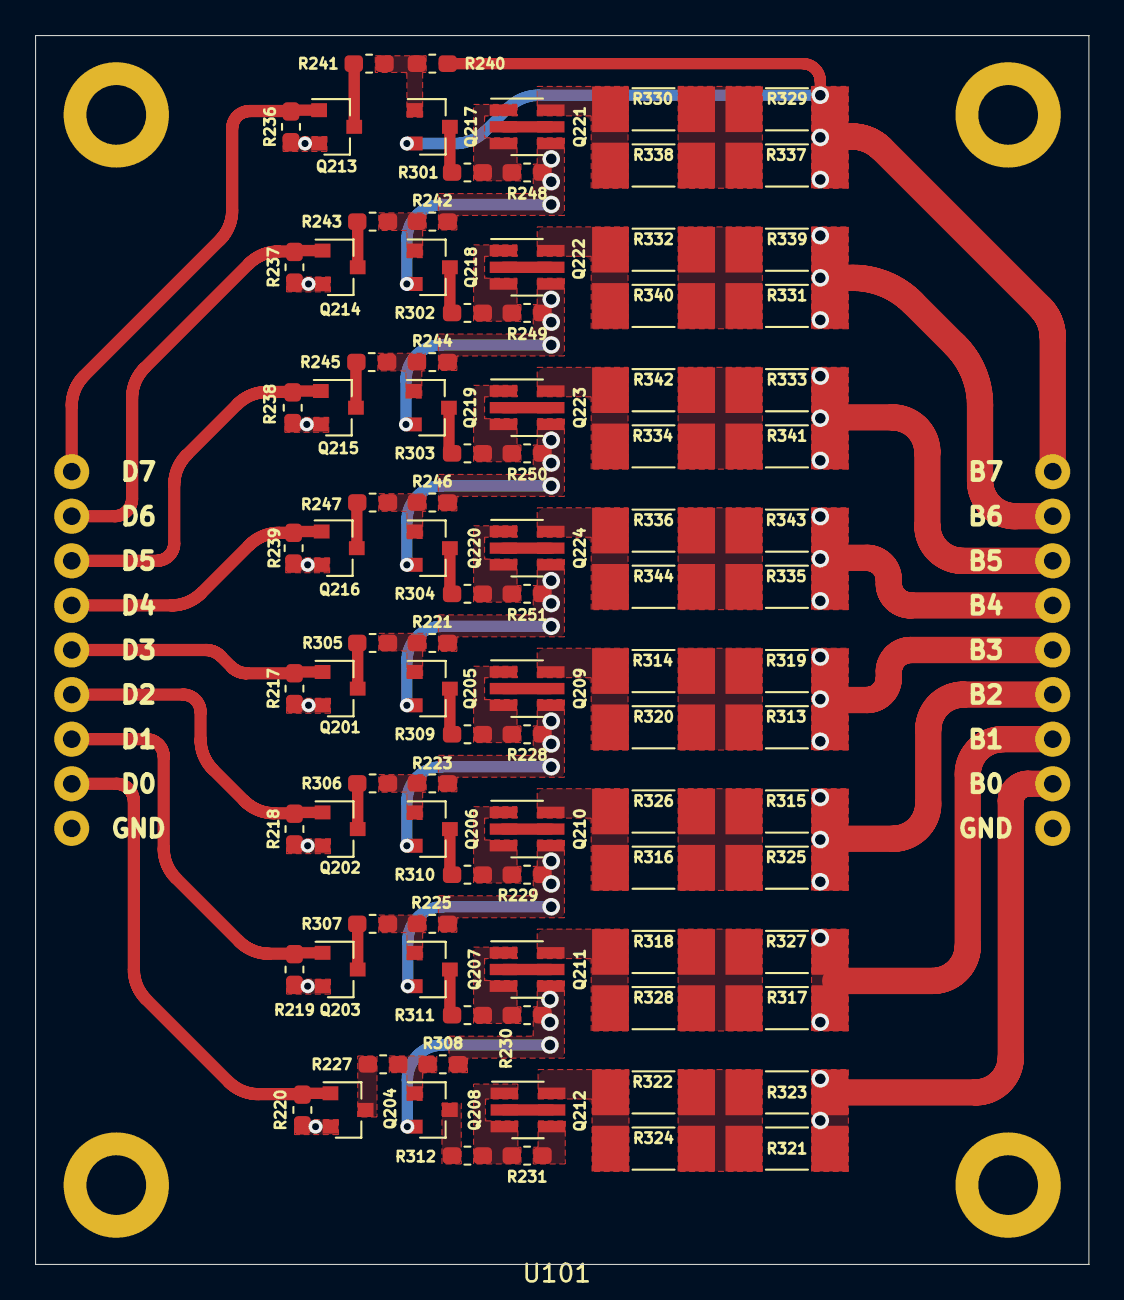
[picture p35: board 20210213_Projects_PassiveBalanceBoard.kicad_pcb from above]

Board: 2 copper layers, 60.0 x 70.0 mm, 97 parts (0 on the bottom side), 73 nets.

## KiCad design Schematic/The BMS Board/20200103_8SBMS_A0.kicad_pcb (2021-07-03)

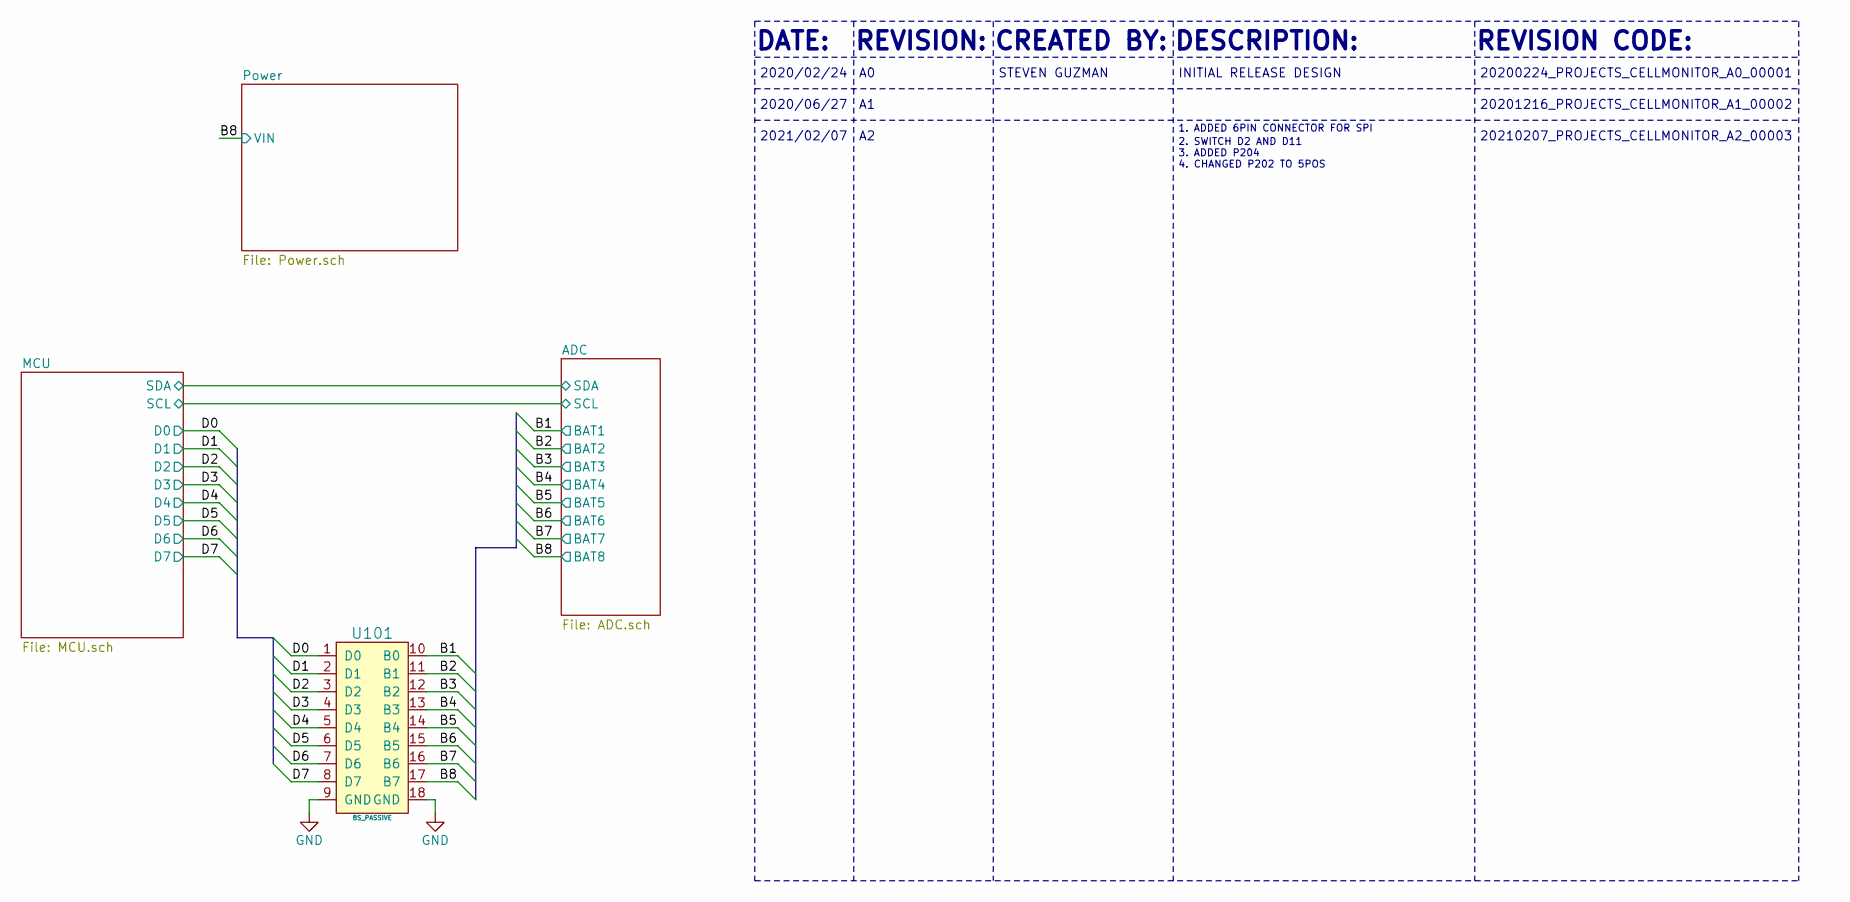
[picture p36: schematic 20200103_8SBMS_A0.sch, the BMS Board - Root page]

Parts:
U101: 8S_PASSIVE

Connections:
/B1: U101.10 (B0); also elsewhere on the board
/B2: U101.11 (B1); also elsewhere on the board
/B3: U101.12 (B2); also elsewhere on the board
/B4: U101.13 (B3); also elsewhere on the board
/B5: U101.14 (B4); also elsewhere on the board
/B6: U101.15 (B5); also elsewhere on the board
/B7: U101.16 (B6); also elsewhere on the board
/B8: U101.17 (B7); also elsewhere on the board
/D0: U101.1 (D0); also elsewhere on the board
/D1: U101.2 (D1); also elsewhere on the board
/D2: U101.3 (D2); also elsewhere on the board
/D3: U101.4 (D3); also elsewhere on the board
/D4: U101.5 (D4); also elsewhere on the board
/D5: U101.6 (D5); also elsewhere on the board
/D6: U101.7 (D6); also elsewhere on the board
/D7: U101.8 (D7); also elsewhere on the board
GND: U101.9 (GND), U101.18 (GND); also elsewhere on the board

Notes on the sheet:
DATE:
DESCRIPTION:
REVISION:
REVISION CODE:
2020/02/24
CREATED BY:
STEVEN GUZMAN
INITIAL RELEASE DESIGN
20200224_PROJECTS_CELLMONITOR_A0_00001
2020/06/27
20201216_PROJECTS_CELLMONITOR_A1_00002
1. ADDED 6PIN CONNECTOR FOR SPI
2021/02/07
2. SWITCH D2 AND D11 3. ADDED P204 4. CHANGED P202 TO 5POS
20210207_PROJECTS_CELLMONITOR_A2_00003

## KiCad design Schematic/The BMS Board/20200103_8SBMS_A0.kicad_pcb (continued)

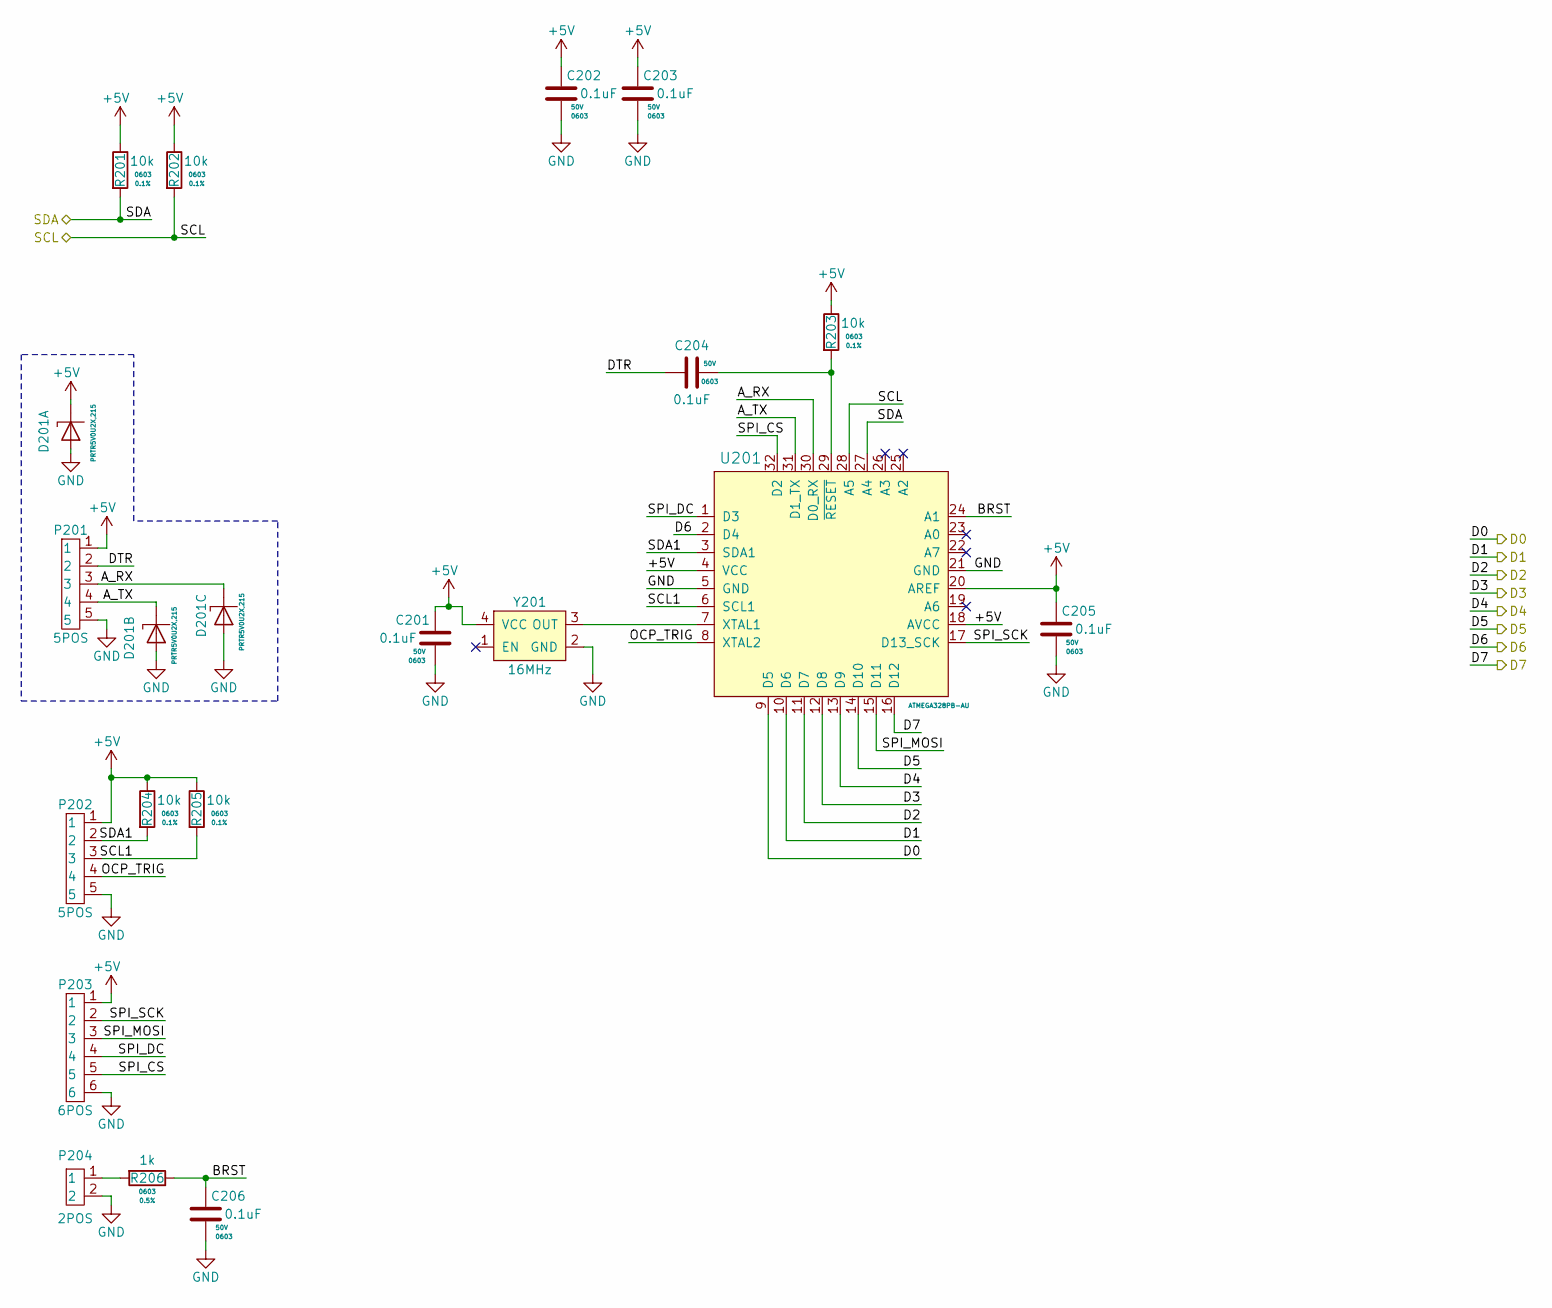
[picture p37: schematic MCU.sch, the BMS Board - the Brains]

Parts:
C201, C202, C203, C204, C205, C206: CL10B104KB8NNNC; C_0603_Handsolder
D201: PRTR5V0U2X,215; SOT-143
P201, P202: S5B-PH-SM4-TB(LF)(SN); S5B-PH-SM4-TB
P203: S6B-PH-SM4-TB(LF)(SN); S6B-PH-SM4-TB
P204: S2B-PH-SM4-TB(LF)(SN)
R201, R202, R203, R204, R205: ERA-3AEB103V; R_0603_Handsolder
R206: RR0816P-102-D; R_0603_Handsolder
U201: ATMEGA328PB-AU; TQFP-32
Y201: CB3-3I-16M0000; CB3

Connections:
+5V: C201.1, C202.1, C203.1, C205.1, D201.4 (K), P201.1, P202.1, P203.1, R201.1, R202.1, R203.1, R204.1, R205.1, U201.4 (VCC), U201.18 (AVCC), U201.20 (AREF), Y201.4 (VCC); also elsewhere on the board
/ADC/SCL: R202.2, U201.28 (A5); also elsewhere on the board
/ADC/SDA: R201.2, U201.27 (A4); also elsewhere on the board
/D0: U201.9 (D5); also elsewhere on the board
/D1: U201.10 (D6); also elsewhere on the board
/D2: U201.11 (D7); also elsewhere on the board
/D3: U201.12 (D8); also elsewhere on the board
/D4: U201.13 (D9); also elsewhere on the board
/D5: U201.14 (D10); also elsewhere on the board
/D6: U201.2 (D4); also elsewhere on the board
/D7: U201.16 (D12); also elsewhere on the board
/MCU/A_RX: D201.3 (K), P201.3, U201.30 (D0_RX)
/MCU/A_TX: D201.2 (K), P201.4, U201.31 (D1_TX)
/MCU/BRST: C206.1, R206.1, U201.24 (A1)
/MCU/DTR: C204.2, P201.2
/MCU/FAN1: U201.23 (A0)
/MCU/OCP_TRIG: P202.4, U201.8 (XTAL2)
/MCU/SCL1: P202.3, R205.2, U201.6 (SCL1)
/MCU/SDA1: P202.2, R204.2, U201.3 (SDA1)
/MCU/SPI_CS: P203.5, U201.32 (D2)
/MCU/SPI_DC: P203.4, U201.1 (D3)
/MCU/SPI_MOSI: P203.3, U201.15 (D11)
/MCU/SPI_SCK: P203.2, U201.17 (D13_SCK)
GND: C201.2, C202.2, C203.2, C205.2, C206.2, D201.1 (A), P201.5, P202.5, P203.6, P204.2, P204.~, U201.5 (GND), U201.21 (GND), Y201.2 (GND); also elsewhere on the board
unnamed: C204.1, R203.2, U201.29 (~RESET~)
unnamed: P204.1, R206.2
unnamed: U201.7 (XTAL1), Y201.3 (OUT)

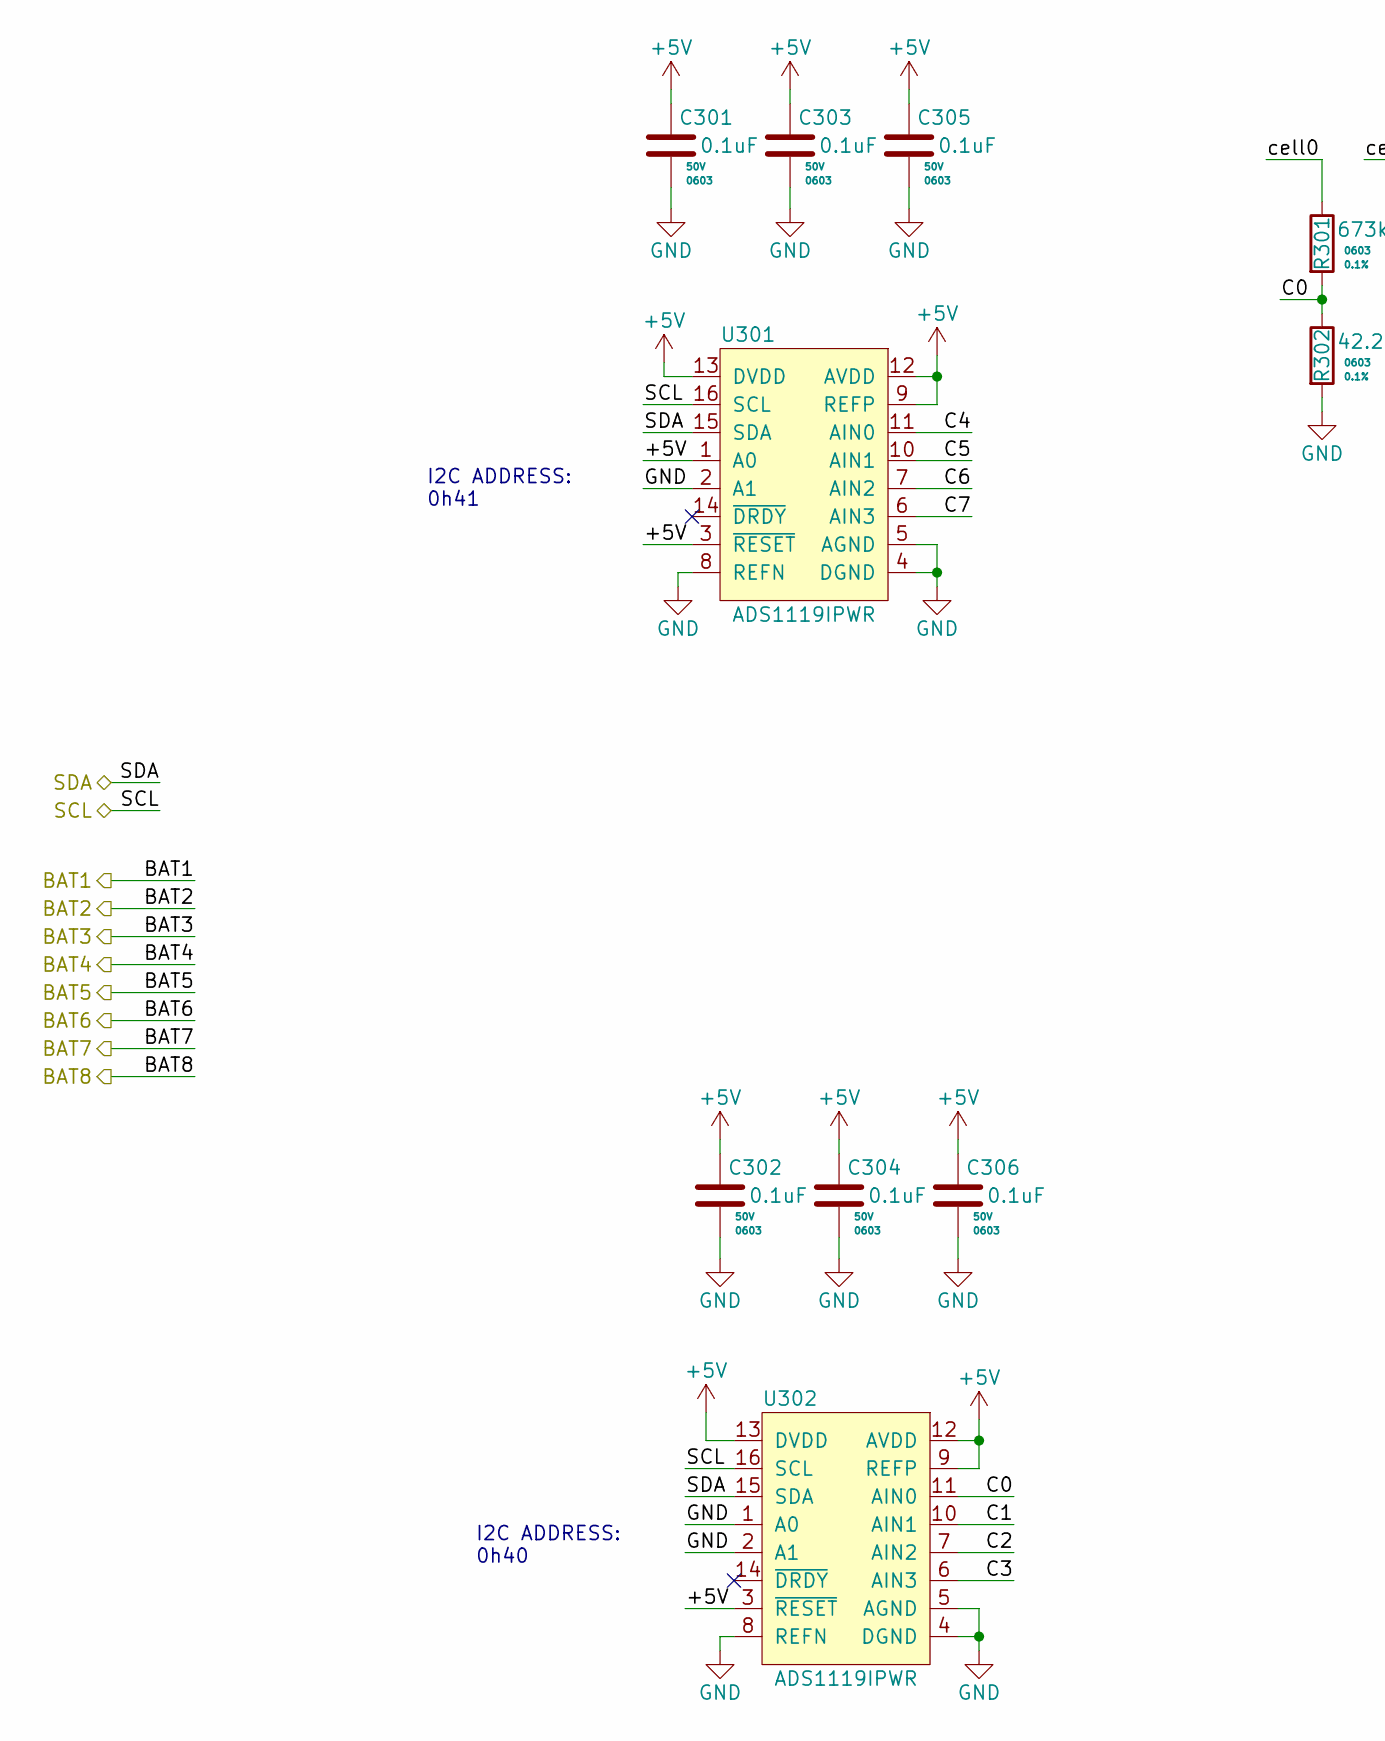
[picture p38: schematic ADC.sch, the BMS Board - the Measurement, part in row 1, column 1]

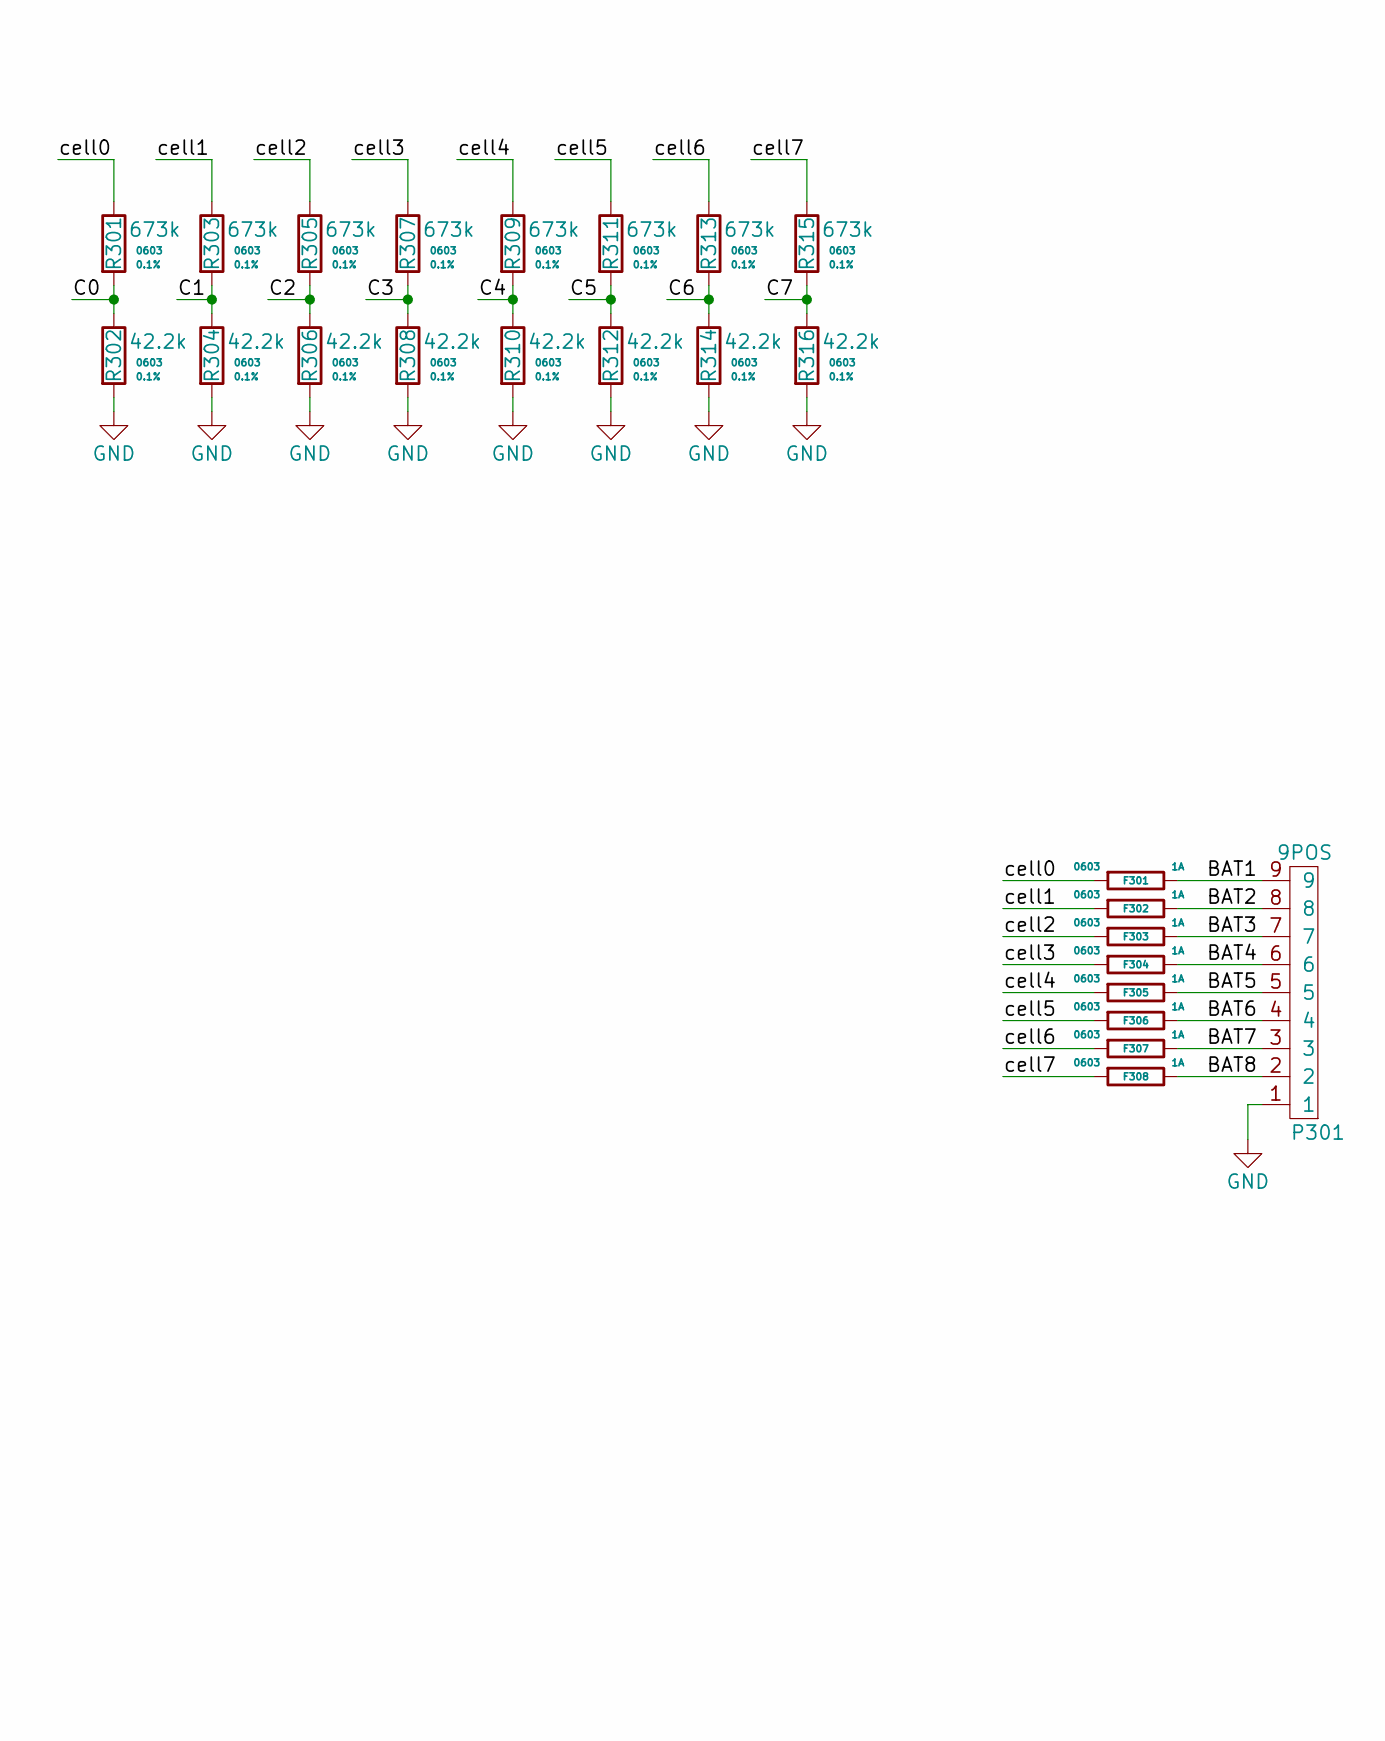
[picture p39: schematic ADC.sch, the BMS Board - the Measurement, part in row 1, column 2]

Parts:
C301, C302, C303, C304, C305, C306: CL10B104KB8NNNC; C_0603_Handsolder
F301, F302, F303, F304, F305, F306, F307, F308: 0686F1000-01; Fuse_0603_1608Metric
P301: S9B-PH-SM4-TB(LF)(SN); S9B-PH-SM4-TB
R301, R303, R305, R307, R309, R311, R313, R315: RT0603BRE07673KL; R_0603_Handsolder
R302, R304, R306, R308, R310, R312, R314, R316: ERJ-PB3B4222V; R_0603_Handsolder
U301, U302: ADS1119IPWR; TSSOP-16

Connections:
+5V: C301.1, C302.1, C303.1, C304.1, C305.1, C306.1, U301.1 (A0), U301.3 (~RESET), U301.9 (REFP), U301.12 (AVDD), U301.13 (DVDD), U302.3 (~RESET), U302.9 (REFP), U302.12 (AVDD), U302.13 (DVDD); also elsewhere on the board
/ADC/C0: R301.2, R302.1, U302.11 (AIN0)
/ADC/C1: R303.2, R304.1, U302.10 (AIN1)
/ADC/C2: R305.2, R306.1, U302.7 (AIN2)
/ADC/C3: R307.2, R308.1, U302.6 (AIN3)
/ADC/C4: R309.2, R310.1, U301.11 (AIN0)
/ADC/C5: R311.2, R312.1, U301.10 (AIN1)
/ADC/C6: R313.2, R314.1, U301.7 (AIN2)
/ADC/C7: R315.2, R316.1, U301.6 (AIN3)
/ADC/SCL: U301.16 (SCL), U302.16 (SCL); also elsewhere on the board
/ADC/SDA: U301.15 (SDA), U302.15 (SDA); also elsewhere on the board
/ADC/cell0: F301.2, R301.1
/ADC/cell1: F302.2, R303.1
/ADC/cell2: F303.2, R305.1
/ADC/cell3: F304.2, R307.1
/ADC/cell4: F305.2, R309.1
/ADC/cell5: F306.2, R311.1
/ADC/cell6: F307.2, R313.1
/ADC/cell7: F308.2, R315.1
/B1: F301.1, P301.9; also elsewhere on the board
/B2: F302.1, P301.8; also elsewhere on the board
/B3: F303.1, P301.7; also elsewhere on the board
/B4: F304.1, P301.6; also elsewhere on the board
/B5: F305.1, P301.5; also elsewhere on the board
/B6: F306.1, P301.4; also elsewhere on the board
/B7: F307.1, P301.3; also elsewhere on the board
/B8: F308.1, P301.2; also elsewhere on the board
GND: C301.2, C302.2, C303.2, C304.2, C305.2, C306.2, P301.1, R302.2, R304.2, R306.2, R308.2, R310.2, R312.2, R314.2, R316.2, U301.2 (A1), U301.4 (DGND), U301.5 (AGND), U301.8 (REFN), U302.1 (A0), U302.2 (A1), U302.4 (DGND), U302.5 (AGND), U302.8 (REFN); also elsewhere on the board

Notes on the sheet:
I2C ADDRESS: 0h41
I2C ADDRESS: 0h40

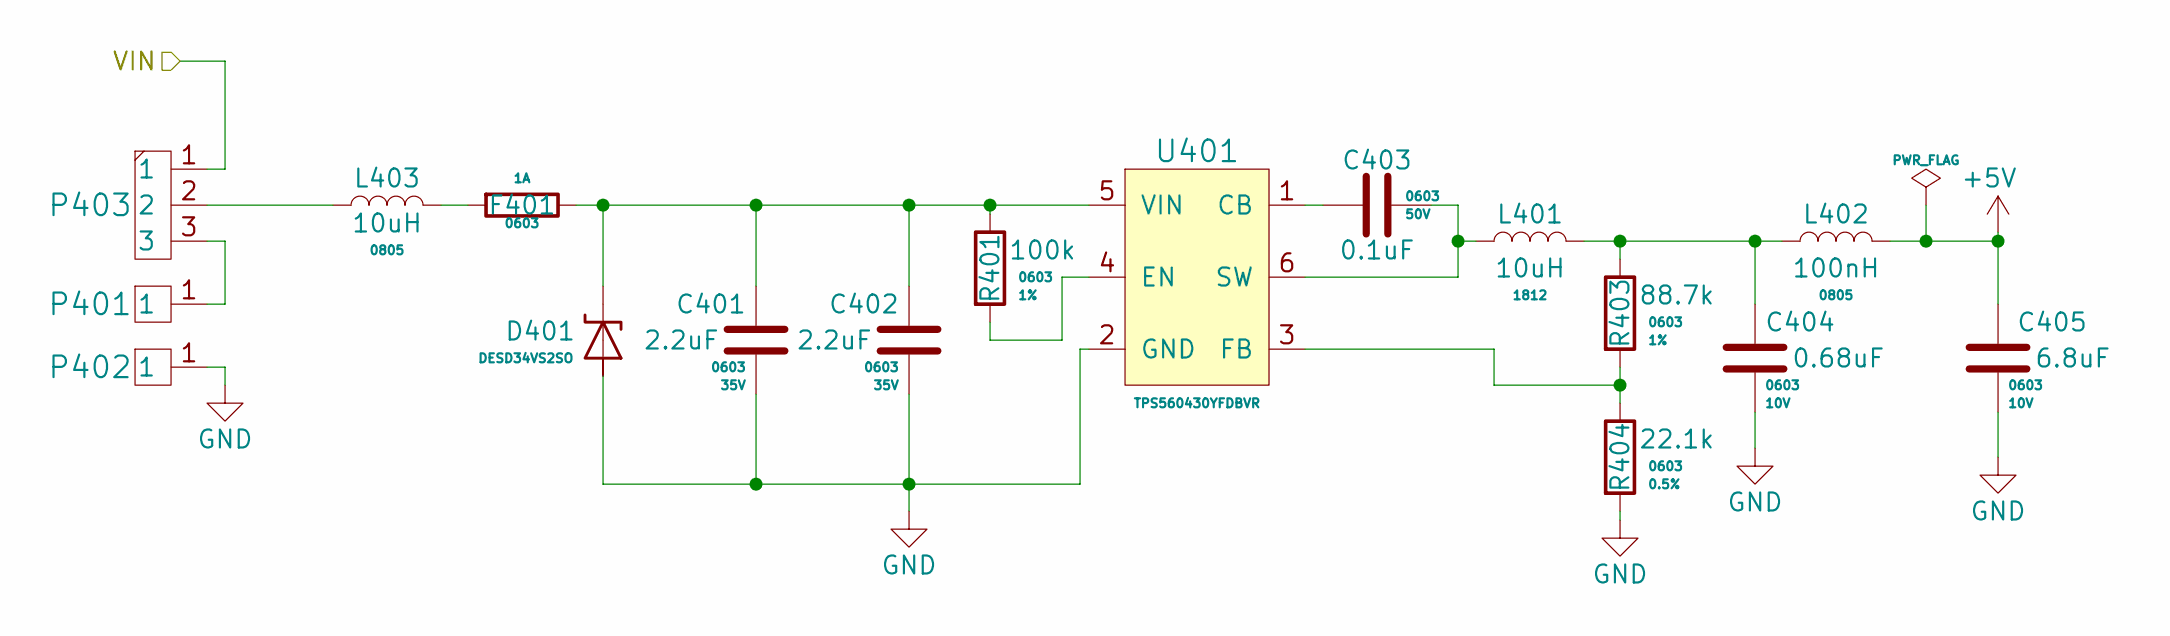
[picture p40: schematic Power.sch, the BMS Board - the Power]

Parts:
C401, C402: GRM188R6YA225MA12D; C_0603_Handsolder
C403: C0603C104K5RACAUTO; C_0603_Handsolder
C404: CC0603KRX7R6BB684; C_0603_Handsolder
C405: C1608X5R1A685M080AC; C_0603_Handsolder
D401: DESD34VS2SO; SOT-23-3
F401: 0686F1000-01; Fuse_0603_1608Metric
L401: LQH43PN100M26L
L402: MLZ2012DR10DT000; L_0805
L403: MLZ2012N100LT000; L_0805
P401, P402: SMD_1POS_1x2mm; SMD_1POS_1MMx2MM
P403: PH1RB-03-UA
R401: CPF0603F100KC1; R_0603_Handsolder
R403: ERJ-3EKF8872V; R_0603_Handsolder
R404: RR0816P-2212-D-34C; R_0603_Handsolder
U401: TPS560430YFDBVR; SOT-23-6

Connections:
+5V: C405.1, L402.2; also elsewhere on the board
/B8: P403.1; also elsewhere on the board
GND: C401.2, C402.2, C404.2, C405.2, D401.1 (A), D401.2 (A), P402.1, R404.2, U401.2 (GND); also elsewhere on the board
unnamed: C401.1, C402.1, D401.3 (K), F401.1, R401.1, U401.5 (VIN)
unnamed: C403.1, L401.1, U401.6 (SW)
unnamed: C403.2, U401.1 (CB)
unnamed: C404.1, L401.2, L402.1, R403.1
unnamed: F401.2, L403.2
unnamed: L403.1, P403.2
unnamed: P401.1, P403.3
unnamed: R401.2, U401.4 (EN)
unnamed: R403.2, R404.1, U401.3 (FB)

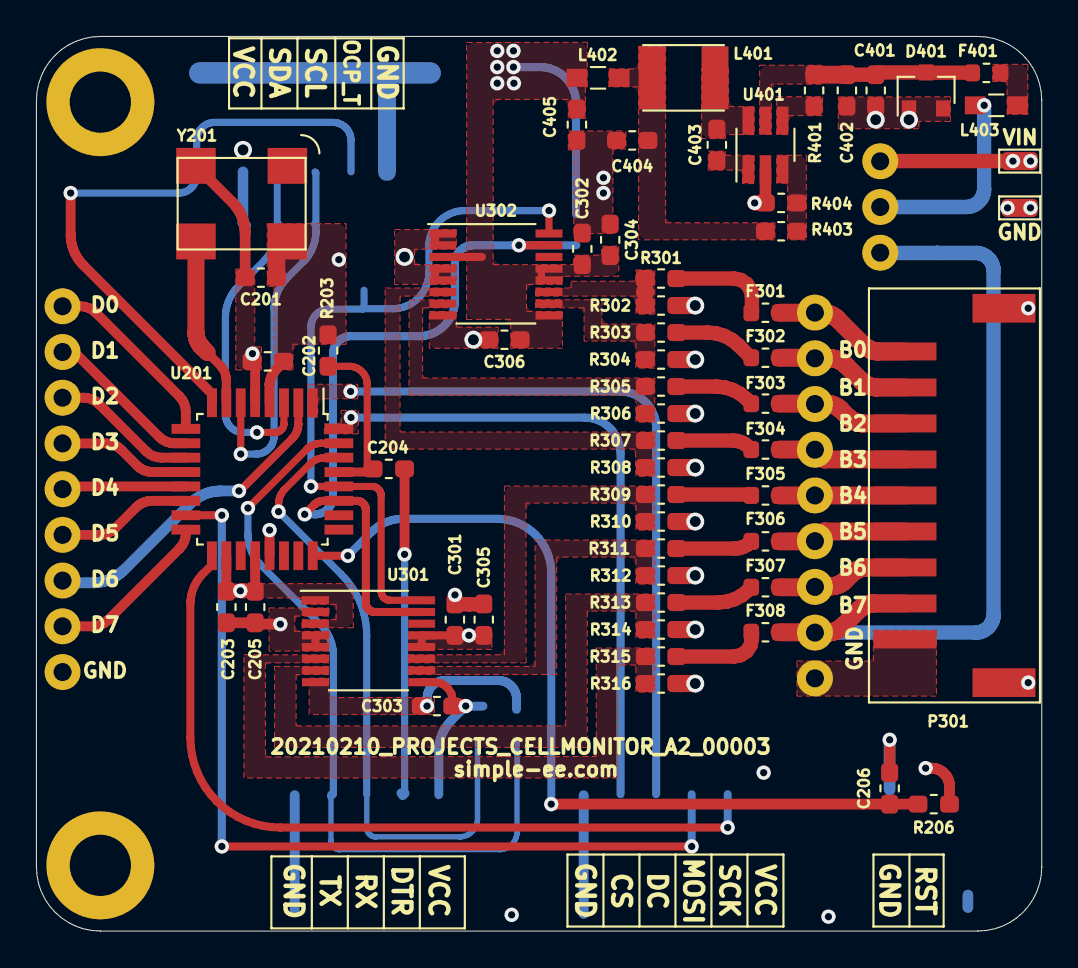
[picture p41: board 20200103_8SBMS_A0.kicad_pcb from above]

Board: 4 copper layers, 55.9 x 49.7 mm, 70 parts (0 on the bottom side), 59 nets.

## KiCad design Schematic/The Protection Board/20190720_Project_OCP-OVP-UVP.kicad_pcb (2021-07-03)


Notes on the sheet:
20190909_PROJECTS_OCP_OVP_A0_00001
INITIAL RELEASE DESIGN
STEVEN GUZMAN
CREATED BY:
2019/09/09
REVISION CODE:
REVISION:
DESCRIPTION:
DATE:
2019/11/19
1. Added ADS1114 for voltage rail reading
20191119_PROJECTS_OCP_OVP_A1_00002
2. Changed R204 from 3.09M to 1.4M
3. Added TVS diode D301 DESD34VS2S0-7
2020/07/18
1. REPLACED ADS1114 WITH ADS1119 2. REMOVED 1.25V REFERENCE IC 3. ADDED R202 AND R203 FOR CURRENT SENSE 4. REPLACED ACS781 WITH ACS780 5. SWITCHED VOLTAGE RAIL TO 5V 6. ADDED 16MHz OSCILLATOR Y201 7. REPLACED R501 33.1k WITH 88.7k
20200718_PROJECTS_OCP_OVP_A2_00003
20201017_PROJECTS_OCP_OVP_A3_00004
2020/10/17
1. ADDED D501, D502 2. REMOVED DIFFERENTIAL MEASUREMENT 3. CHANGED R205 AND R204 4. ADDED R208, R209 5. CHANGED L501 6. CHANGED C504, C505 7. ADDED L301 8. REMOVED R403
1. REMOVED F401-F403 2. ADDED F401 125A 3. UPDATED P405,P407 TO 12MM PAD
20210213_PROJECTS_OCP_OVP_A4_00005


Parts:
C201, C202, C203, C204, C205, C206, C207: C0603C104K5RACAUTO; C_0603_Handsolder
R201, R206, R207, R208, R209: ERA-3AEB103V; R_0603_Handsolder
R202, R212: RC0603FR-0730KL; R_0603_Handsolder
R203, R213: RR0816P-203-D; R_0603_Handsolder
R204: RT0603BRE07673KL; R_0603_Handsolder
R205: ERJ-PB3B4222V; R_0603_Handsolder
R210, R211: RC0603FR-07470RL; R_0603_Handsolder
SW201: KSC721G
TP201: TP_CIRCLE_1MM
TP202, TP203, TP204, TP205: TP_CIRCLE_1.5MM
TP206, TP207: TP_CIRCLE_1MM-TestPoint; TP_CIRCLE_1MM
U201: MC74HC1G04DFT1G; SOT-353_SC-70-5
U202: ATMEGA328PB-AU; TQFP-32
U203: ADS1119IPWR; TSSOP-16
Y201: CB3-3I-16M0000; CB3

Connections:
+5V: C201.2, C202.2, C203.2, C205.2, C207.2, R201.1, R206.1, R208.1, R209.1, R212.1, U201.5 (VCC), U202.4 (VCC), U202.18 (AVCC), U203.3 (~RESET), U203.9 (REFP), U203.12 (AVDD), U203.13 (DVDD), Y201.4 (VCC); also elsewhere on the board
/MCU/CHRG_ON: R210.2; also elsewhere on the board
/MCU/DTR: C204.2; also elsewhere on the board
/MCU/GATE_LOAD: R211.2; also elsewhere on the board
/MCU/INT0: TP201.1, U202.32 (D2)
/MCU/I_OUT: R202.1; also elsewhere on the board
/MCU/I_SENSE_P: R202.2, R203.1, TP202.1, U203.11 (AIN0)
/MCU/OCP_TRIG: U202.9 (D5); also elsewhere on the board
/MCU/RESTORE: U201.4 (OUT), U202.1 (D3)
/MCU/RX_M: U202.30 (D0_RX); also elsewhere on the board
/MCU/SCL: R209.2, U202.28 (A5), U203.16 (SCL)
/MCU/SCL1: U202.6 (SCL1); also elsewhere on the board
/MCU/SDA: R208.2, U202.27 (A4), U203.15 (SDA)
/MCU/SDA1: U202.3 (SDA1); also elsewhere on the board
/MCU/TX_M: U202.31 (D1_TX); also elsewhere on the board
/MCU/V_RAIL: R212.2, R213.1, TP206.1, U203.7 (AIN2)
/MCU/V_SENSE_P: R204.2, R205.1, TP204.1, U203.10 (AIN1)
/VIN: R204.1; also elsewhere on the board
GND: C201.1, C202.1, C203.1, C205.1, C206.1, C207.1, R203.2, R205.2, R213.2, SW201.1, TP203.1, TP205.1, TP207.1, U201.3 (GND), U202.5 (GND), U202.21 (GND), U203.1 (A0), U203.2 (A1), U203.4 (DGND), U203.5 (AGND), U203.8 (REFN), Y201.2 (GND); also elsewhere on the board
unnamed: C204.1, R201.2, U202.29 (~RESET~)
unnamed: C206.2, R207.1, U201.2 (INA)
unnamed: R206.2, R207.2, SW201.2
unnamed: R210.1, U202.13 (D9)
unnamed: R211.1, U202.12 (D8)
unnamed: U202.7 (XTAL1), Y201.3 (OUT)

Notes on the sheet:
I2C ADDRESS: 0h40
INPUT BUTTON FOR RESET WHEN FAULT OCCURS


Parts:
C301: GRM188R61E225KA12D; C_0603_Handsolder
C302: CL10A475MA8NQNC; C_0603_Handsolder
C501: GRM188R6YA225MA12D; C_0603_Handsolder
C502, C503: C0603C104K5RACAUTO; C_0603_Handsolder
C504: CC0603KRX7R6BB684; C_0603_Handsolder
C505: C1608X5R1A685M080AC; C_0603_Handsolder
D301, D302: DESD34VS2SO; SOT-23-3
F301, F302: 0686F1000-01; Fuse_0603_1608Metric
L1, L302: MLZ2012N100LT000; L_0805_2012Metric
L301: MLZ2012DR10DT000; L_0805
L501: LQH43PN100M26L
R404: CPF0603F100KC1; R_0603_Handsolder
R501: ERJ-3EKF8872V; R_0603_Handsolder
R502: RR0816P-2212-D-34C; R_0603_Handsolder
U301: TPS7B6950DBVR; SOT-23-5_HandSoldering
U501: TPS560430YFDBVR; SOT-23-6

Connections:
+5V: C505.1, L301.2; also elsewhere on the board
+5VD: C302.1, U301.5 (OUT); also elsewhere on the board
/VIN: F301.2; also elsewhere on the board
/VOUT: F302.2; also elsewhere on the board
GND: C501.2, C502.1, C504.2, C505.2, D301.1 (A), D301.2 (A), R502.2, U501.2 (GND); also elsewhere on the board
GNDPWR: C301.2, C302.2, D302.1 (A), D302.2 (A), U301.2 (GND), U301.4 (GND); also elsewhere on the board
unnamed: C301.1, D302.3 (K), L302.2, U301.1 (IN)
unnamed: C501.1, C502.2, D301.3 (K), L1.2, R404.1, U501.5 (VIN)
unnamed: C503.1, L501.1, U501.6 (SW)
unnamed: C503.2, U501.1 (CB)
unnamed: C504.1, L301.1, L501.2, R501.1
unnamed: F301.1, L1.1
unnamed: F302.1, L302.1
unnamed: R404.2, U501.4 (EN)
unnamed: R501.2, R502.1, U501.3 (FB)

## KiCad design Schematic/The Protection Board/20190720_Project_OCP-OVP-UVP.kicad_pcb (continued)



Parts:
C401, C402, C403: C0603C104K5RACAUTO; C_0603_Handsolder
F401: 142.5631.6122; 142.5631.5702
P403, P404, P405: TH_1POS_10MMx12MM_M6_copy; TH_1POS_10MMx12MM_M6
P407, P408: SMD_1POS_12MM
Q401, Q404: 2N7002-7-F; SOT-23-3
Q402, Q405: BSS84LT1G; SOT-23-3
Q403: ISO7021FDR; SOIC-8
Q406, Q407, Q410, Q412, Q413: PSMNR70-40SSHJ; SOT-1235
R403, R416, R420, R422, R423: RC0603FR-07100RL; R_0603_Handsolder
R405, R406, R407, R408, R409, R410, R411, R412, R413, R414, R415: CPF0603F100KC1; R_0603_Handsolder
U401: ACS781KLRTR-150B-T; PowerSMD-7

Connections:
+5V: C401.1, C402.1, Q403.1 (VCC1), U401.1 (VCC); also elsewhere on the board
+5VD: C403.1, Q403.8 (VCC2); also elsewhere on the board
/MCU/CHRG_ON: Q403.3 (INB), R409.1; also elsewhere on the board
/MCU/GATE_LOAD: Q401.1 (G), R405.1; also elsewhere on the board
/MCU/I_OUT: U401.3 (VOUT); also elsewhere on the board
/PowerFets/GC: R414.2, R415.1, R422.2, R423.1
/PowerFets/GL: R403.2, R408.1, R410.2, R416.2, R420.2
/VIN: F401.2, P403.1, Q402.2 (S), R406.1; also elsewhere on the board
/VOUT: F401.1, P405.1, Q405.2 (S), R412.1; also elsewhere on the board
GND: C401.2, C402.2, P404.1, Q401.2 (S), Q403.4 (GND1), R405.2, R408.2, R409.2, U401.2 (GND), U401.6 (IP-); also elsewhere on the board
GNDPWR: C403.2, P408.1, Q403.5 (GND2), Q404.2 (S), Q412.2 (S), Q412.3 (S), Q412.4 (S), Q413.2 (S), Q413.3 (S), Q413.4 (S), R411.2, R415.2; also elsewhere on the board
unnamed: P407.1, Q406.5 (D), Q407.5 (D), Q410.5 (D)
unnamed: Q401.3 (D), R407.2
unnamed: Q402.1 (G), R406.2, R407.1
unnamed: Q402.3 (D), R410.1
unnamed: Q403.6 (OUTB), Q404.1 (G), R411.1
unnamed: Q404.3 (D), R413.2
unnamed: Q405.1 (G), R412.2, R413.1
unnamed: Q405.3 (D), R414.1
unnamed: Q406.1 (G), R416.1
unnamed: Q406.2 (S), Q406.3 (S), Q406.4 (S), Q407.2 (S), Q407.3 (S), Q407.4 (S), Q410.2 (S), Q410.3 (S), Q410.4 (S), Q412.5 (D), Q413.5 (D), U401.5 (IP+)
unnamed: Q407.1 (G), R403.1
unnamed: Q410.1 (G), R420.1
unnamed: Q412.1 (G), R422.1
unnamed: Q413.1 (G), R423.2

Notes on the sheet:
12V: 0R (R406) 24V: 100k (R406)
12V: 0R (R410) 24V: 100k (410)
12V: 0R (R412) 24V: 100k (R412)
12V: 0R (R414) 24V: 100k (414)
LOAD-
LOAD+
CHARGE-
BATTERY-
BATTERY+


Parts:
D501, D502: PRTR5V0U2X,215; SOT-143
P305, P306, P307, P308: Standoff_M3; M3X3.00MM; Part Number M3
P401, P402: S5B-PH-SM4-TB(LF)(SN); S5B-PH-SM4-TB
R401, R402: ERA-3AEB103V; R_0603_Handsolder

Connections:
+5V: D501.4 (K), D502.4 (K), P401.1, P402.4, R401.1, R402.1; also elsewhere on the board
/MCU/DTR: P402.1; also elsewhere on the board
/MCU/OCP_TRIG: P401.4; also elsewhere on the board
/MCU/RX_M: D502.3 (K), P402.3; also elsewhere on the board
/MCU/SCL1: D501.3 (K), P401.3, R401.2; also elsewhere on the board
/MCU/SDA1: D501.2 (K), P401.2, R402.2; also elsewhere on the board
/MCU/TX_M: D502.2 (K), P402.2; also elsewhere on the board
GND: D501.1 (A), D502.1 (A), P401.5, P402.5; also elsewhere on the board


Board: 4 copper layers, 62.3 x 85.5 mm, 97 parts (0 on the bottom side), 52 nets.

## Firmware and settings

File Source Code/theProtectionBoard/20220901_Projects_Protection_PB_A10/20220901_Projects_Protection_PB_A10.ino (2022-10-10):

////////////////////////////////////////////////////////////////////////////////
// Title:       OCP, OVP, Battery protection board
// Date:        20220901
// Author:      Steven Guzman
// Revision:    A10
// Description: This is an over current and over voltage protection board for 
//              battery packs, all my examples are based on LiFePO4 packs
// -----------------------------------------------------------------------------
// Bootloader settings: Minicore
// https://github.com/MCUdude/MiniCore#supported-microcontrollers
// -----------------------------------------------------------------------------
// 1. Clock: External 16 MHz 
// 2. BOD: BOD 2.7V
// 3. Compiler LTO: LTO disabled
// 4. Varient: 328PB
// 5. Bootloader: Yes (UART0)
////////////////////////////////////////////////////////////////////////////////

#include <Wire1.h>
#include <Wire.h>
#include <EEPROM.h>
#include <avr/wdt.h>
#include "ADS1119.h"    // Custom adc library 


/////////////////////////////////////////////////////////////
// Two point calibration method values
// array variable 0 = current, 1 = voltage
/////////////////////////////////////////////////////////////
int Code_low[3];  
int Code_high[3];

float Gain_error[3];
unsigned int Offset[3];

//////////////////////////////////////////////////////////////
// Misc variables
//////////////////////////////////////////////////////////////

char income;
char t[6];
char Amps[6];
int a;

long Timer = 100;   // Used for interval of Display refresh rate

float Vpack = 0.000;
float SenseCurrent = 0.000;
float temp[3] = {0.000,0.000};
float Power = 0.000;
float CurrentNow = 0.000;
float mV_A = 0.01333;

float tempCurrentZero = 0.000;
float SenseCurrentZero = 0.000; // This is the zero point for current sensing 0A
float offsetCurrentZero = 0.000;

////////////////////////////////////////////////////////////////////////////////
// Coulomb counting variables
////////////////////////////////////////////////////////////////////////////////
float Ah_Pack = 60.00;
float Ah_Now = 0.000;
float Coulomb = 0.000;
float SOC = 0.000;
long dt = 0;
float Full_Pack = 0.000;
float Empty_Pack = 0.000;


////////////////////////////////////////////////////////////////////////////////
// Variables used for protecting parameters
////////////////////////////////////////////////////////////////////////////////
float OCP = 50.00;
float OVP = 29.2;
float UVP = 21.6;

int OVPCount = 0;
int UVPCount = 0;
int OCPCount = 0;

long currentTime = 0;

int previousTimeOVP = 0;
int previousTimeUVP = 0;
int previousTimeOCP = 0;

long deltaTime = 0;

int count = 0;

int ResetFaultO = 0;  // Overcurrent fault reset flag 
int ResetFaultV = 0;  // Overvoltage fault reset flag
int ResetFaultU = 0;  // Undervoltage fault reset falg

int OCPGood = 0; int OVPGood = 0; int UVPGood = 0;

void setup()
{
    Wire1.begin(2); // This is initiating the atmega328PB wire library 
                    // client address # 2 for use with communicating with the
                    // BMS board.

    Wire.begin();   // Initiating the wire library for internal use

    Wire1.onReceive(requestEvent); // This will trigger when a byte is sent over
    Wire1.onRequest(requestEvent2); // This will trigger when a requestFrom is sent

    Serial.begin(115200);

    /* Used as a hardware fault flag to tie into the BMS board and notify
    when an OCP condition was triggered */
    pinMode(5,OUTPUT);
    digitalWrite(5,HIGH);

    /* This digital pin is configured to control the charging mosfet */
    pinMode(9,OUTPUT);      
    digitalWrite(9,HIGH);

    /* This digital pin is configured to control the discharge mosfet */
    pinMode(8,OUTPUT);
    digitalWrite(8,HIGH);

    /* Initiate wire I2C events for when the BMS board request or sends data
    over via the secondary I2C */
    Wire1.onReceive(requestEvent);
    Wire1.onRequest(requestEvent2);


    ////////////////////////////////////////////////////////////////////////////
    // Here we are saving certain variables in EEPROM memory as they do no 
    // change often and will initiate upon startup
    ////////////////////////////////////////////////////////////////////////////
    
    /* The offset and Gain_error variable is used for a two point calibration of 
    the ADS1119 ADC so that we can have accurate measured values */
    EEPROM.get(0,Offset[0]);
    EEPROM.get(4,Offset[1]);
    EEPROM.get(8,Offset[2]);

    EEPROM.get(30,Gain_error[0]);
    EEPROM.get(34,Gain_error[1]);
    EEPROM.get(38,Gain_error[2]);

    /* Store OCP, OVP, UVP limits in EEPROM that way we can change them later
    via serial port and have the changes permanent when system powers down */
    EEPROM.get(100,OCP);
    EEPROM.get(104,OVP);
    EEPROM.get(108,UVP);

    /* Misc variables stored in eeprom */
    EEPROM.get(1000,mV_A);
    EEPROM.get(1004,Timer);
    EEPROM.get(1008,offsetCurrentZero);

    /* Coulomb counting variables */
    //EEPROM.get(204,Ah_Now);
    //EEPROM.get(208,Coulomb);
    EEPROM.get(212,SOC);
    EEPROM.get(216,Full_Pack);
    EEPROM.get(220,Empty_Pack);

    wdt_enable(WDTO_8S);    // Enable watchdog timer 8 second reset 

    Serial.println("Initialized");
    Serial.print(" OCP Limit: ");
    Serial.print(OCP);

    Serial.print(" OVP Limit: ");
    Serial.print(OVP);   

    Serial.print(" UVP Limit: ");
    Serial.print(UVP); 
}

void loop()
{
    currentTime = millis(); 
 
    ReadADC(1); // This reads Voltage of the pack
    Vpack = (ReadValue[1] - Offset[1])/(Gain_error[1]);

    CurrentFunction();
    
    Power = Vpack * CurrentNow;

    EnableSwitch();

    WireDisplay();

    if (Vpack >= Full_Pack)
    {
        Coulomb = Ah_Pack * 3600.00*1000;
    }
    if (Vpack < Empty_Pack)
    {
        Coulomb = 0.00;
    }
    wdt_reset();
}

////////////////////////////////////////////////////////////////////////////////
// Here I created a function for reading the current value by calling the adc
// and applying the offset and gain error variables obtained from the two point
// calibration process
////////////////////////////////////////////////////////////////////////////////
void CurrentFunction()
{
    /* Reset the last measured current value */
    temp[1] = 0.000;
    SenseCurrent = 0.000;

    /* Read the current and grab the raw data from the adc and then apply
    the offset and gain error and set it to the sensecurrent variable */  
    ReadADC(0);
    SenseCurrent = ((ReadValue[0] - Offset[0])/(Gain_error[0])) - offsetCurrentZero;

    /* This is used to measure the system voltage rail and get an accurate 
    reading of the rail voltage.  This is needed because the current sensor is
    bidirectional and sets the 0A current value at half of VCC.  So in order 
    to get an accurate current reading we need an accurate reading of the system
    voltage to apply the 0A point. */
    ReadADC(2);
    tempCurrentZero = (ReadValue[2] - Offset[2])/(Gain_error[2]);
    SenseCurrentZero = (tempCurrentZero/2.000);

    /* Here we compare the sensed current value to the zero point, positive 
    current value or negative current value.  Then after that is determined
    we subtract the vcc offset value and convert the voltage reading to a 
    current value by dividing by the sensativity mV/A variable */
    if (SenseCurrent == SenseCurrentZero)
    {
        CurrentNow = 0.000;
    }
    else if (SenseCurrent > SenseCurrentZero)
    {
        CurrentNow = -1*(SenseCurrent - SenseCurrentZero)/mV_A;
    }
    else if (SenseCurrent < SenseCurrentZero)
    {
        CurrentNow = (SenseCurrentZero - SenseCurrent)/mV_A;
    }
}

////////////////////////////////////////////////////////////////////////////////
// Serial print current, voltage, and power values
////////////////////////////////////////////////////////////////////////////////
void WireDisplay()
{
  if (currentTime - deltaTime >= Timer)
    {
        // elapsed time for coulomb counting
        dt = currentTime - deltaTime;
        Coulomb = Coulomb + CurrentNow*(float)dt; // Units of A*ms

        Ah_Now = Coulomb*(1.00/1000.00)*(1.00/60.00)*(1.00/60.00);
        SOC = ((Ah_Pack - Ah_Now)/(Ah_Pack))*100;

        //Serial.print("Voltage: ");
        //Serial.print(Vpack,3);
        //Serial.print(",");
    
        //Serial.print("Current: ");
        //Serial.print(CurrentNow,3);
        //Serial.print(",");
    
        //Serial.print("Power: ");
        //Serial.println(Power,3);

        //Serial.print("Amp-Hour: ");
        //Serial.println(Ah_Now,3);

        //Serial.print("Time Elapsed: ");
        //Serial.println(count);
        //Serial.println(SenseCurrent,3);

        deltaTime = currentTime;
    } 
}
////////////////////////////////////////////////////////////////////////////////
// Function that will detect an over voltage condition and turn of the charging
// mosfet
////////////////////////////////////////////////////////////////////////////////
void OVP_Function()
{
    /*  Condition used to open the switch to stop current flow for an 
        overvoltage event 
        Digital Pin D9 = Charge FET */
    if (Vpack >= OVP && ResetFaultV == 0)
    {
        digitalWrite(9, LOW);
        /* This prevents the ovp function from constantly retriggering the
        mosfet value if the an ovp condition is still in place */
        ResetFaultV = 1;    
        OVPGood = 0;
    }  

    else if ((Vpack < OVP) && ResetFaultV == 0)
    {
        OVPGood = 1;
    }
}
////////////////////////////////////////////////////////////////////////////////
////////////////////////////////////////////////////////////////////////////////
void UVP_Function()
{
    /*  Condition used to open the switch to stop current flow for an 
        undervoltage event
        Digital Pin D8 = Discharge FET 
    */
    if (Vpack < UVP && ResetFaultU == 0)
    {
        digitalWrite(8, LOW);
        /* This prevents the uvp function from constantly retriggering the
        mosfet value if the an uvp condition is still in place */
        ResetFaultU = 1;
        UVPGood = 0;
        Serial.println("UVP Fault Detected");
    }  


    else if ((Vpack >= UVP) && ResetFaultU == 0)
    {
        UVPGood = 1;
    }
}
////////////////////////////////////////////////////////////////////////////////
////////////////////////////////////////////////////////////////////////////////
void OCP_Function()
{
    /*  Condition used to open the switch to stop current flow for an 
        overcurrent event 
        Digital Pin D8 and D9 = Discharge and Charge FETs
    */
     if ((CurrentNow >= OCP || (-1*CurrentNow >= OCP)) && ResetFaultO == 0)
     {
        digitalWrite(9, LOW);
        digitalWrite(8, LOW);
        /* This prevents the ocp function from constantly retriggering the
        mosfet value if the an ocp condition is still in place */
        ResetFaultO = 1;  
        OCPGood = 0;
        digitalWrite(5,LOW);
        Serial.println("OCP Fault Detected");
     }  

    else if ((CurrentNow < OCP) && ResetFaultO == 0)
    {
        OCPGood = 1;
    }

}
////////////////////////////////////////////////////////////////////////////////
// This function checks to see if the fault has been removed and then re-enables
// the mosfets for normal operation
////////////////////////////////////////////////////////////////////////////////

void EnableSwitch()
{
  OVP_Function();
  UVP_Function();
  OCP_Function();

  if (UVPGood == 1 && OCPGood == 1 && ResetFaultU == 0)
  {
    digitalWrite(8,HIGH);
    digitalWrite(5,HIGH);
  }

  if (OVPGood == 1 && OCPGood == 1 && ResetFaultV == 0)
  {
    digitalWrite(9,HIGH);
    digitalWrite(5,HIGH);
  }

  if (OCPGood == 1 && ResetFaultO == 0 && ResetFaultV == 0 &&  ResetFaultU == 0)
  {
    digitalWrite(9,HIGH);
    digitalWrite(8,HIGH);
    digitalWrite(5,HIGH);
  }
  else
  {
    //Serial.println("Fault Detected, Switch off");
  }
}

////////////////////////////////////////////////////////////////////////////////
// This function is called everytime a uart command is received.  We use it 
// combined with the arduino serial monitor to set variables and perform
// certain commands.
// example of command to send via serial monitor:
// ex. 1004, OCP, OVP, UVP
//     1004,30.00,29.00,21.00
//------------------------------------------------------------------------------
// List of commands
//------------------------------------------------------------------------------
// 1. 1001,2.500  | This is for performing a two point calibration for the 
//                | current measurement and then storing those values in 
//                | the eeprom.
//------------------------------------------------------------------------------
// 2. 1002,29.00  | This is for performing a two point calibration for the 
//                | voltage of the battery and then storing is in eeprom
//------------------------------------------------------------------------------
// 3. 1003,5.00   | This is for performing a two point calibration for the 
//                | system rail voltage and then storing is in eeprom
//------------------------------------------------------------------------------
// 4. 1004,30.00, | This is to enter new values for over current limit,
//    29.00,21.00 | over voltage limit, and under voltage limit
//------------------------------------------------------------------------------
// 5. 1005        | Future command place holder
//------------------------------------------------------------------------------
// 6. 1006        | Turns off the mosfets to prevent current flow
//------------------------------------------------------------------------------
// 7. 1007        | This resets any and all fault conditions and returns system
//                | to normal conditions
//------------------------------------------------------------------------------
// 8. 1008,0.01333| This sets the sensativity value for the current sensor
//------------------------------------------------------------------------------
// 9. 1009        | Outputs limits and revision number
//------------------------------------------------------------------------------
// 10. 1010       | Sets the interval value for display output
//------------------------------------------------------------------------------
// 11. 1011       | Sets the offsetcurrentzero value to help with getting a 
//                | a better current measurement
// -----------------------------------------------------------------------------
// 12. 1012,50.00 | Here you set the Amp hour pack value ex. 50.00
// -----------------------------------------------------------------------------
// 13. 1013,27.8  | Here you set the voltage value of the pack when it is 
//                | considered full. ex. for an 8S LiFePO4 I set my value to 
//                | to 27.8 which means cell values are 3.475
// -----------------------------------------------------------------------------
// 14. 1014,22.7  | Here you set the voltage value of the pack when it is 
//                | considered empty. ex. for an 8S LiFePO4 I set the value to
//                | to 22.7 which means cell values are 2.8375
////////////////////////////////////////////////////////////////////////////////
void serialEvent()
{
    while (Serial.available())
    {
        a = Serial.parseInt();
        if (a == 1001)
        {
            float v_high = Serial.parseFloat();
            Serial.println(v_high,3);
            delay(1000);
            ReadADC(0);
            Code_low[0] = ReadValue[0];
            delay(100);

            Serial.print("Code low ");
            Serial.print("Current");
            Serial.print(": ");
            Serial.println(Code_low[0]);

            int temp3 = 0;
            Serial.println("Connect Full scale reference and enter value 1");
            while(temp3 == 0)
            {
              temp3 = Serial.parseInt();
              wdt_reset();
            }

            float temp2 = 0.000;

            ReadADC(0);
            
            Code_high[0] = ReadValue[0];

            Serial.print("Code high ");
            Serial.print("Current");
            Serial.print(": ");
            Serial.println(Code_high[0]);

            Gain_error[0] = (Code_high[0] - Code_low[0])/(v_high-0.000);
            Offset[0] = Code_high[0] - Gain_error[0]*v_high;

            Serial.print("Offset ");
            Serial.print("Current");
            Serial.print(": ");
            Serial.println(Offset[0]);

            Serial.print("Gain Error ");
            Serial.print("Current");
            Serial.print(": ");
            Serial.println(Gain_error[0]);

            ReadADC(0);

            temp2 = (ReadValue[0] - Offset[0])/(Gain_error[0]);

            Serial.print("Current ");
            Serial.print(": ");
            Serial.println(temp2,3);
          
            EEPROM.put(0,Offset[0]);
            EEPROM.put(30,Gain_error[0]);

        }

        if (a == 1002)
        {
          float v_high = Serial.parseFloat();
          Serial.println(v_high,3);

          ReadADC(1);

          Code_low[1] = ReadValue[1];
          delay(100);

          Serial.print("Code low ");
          Serial.print("Voltage");
          Serial.print(": ");
          Serial.println(Code_low[1]);

          int temp3 = 0;
          
          Serial.println("Connect Full scale reference and enter value 1");
          while(temp3 == 0)
          {
            temp3 = Serial.parseInt();
            wdt_reset();
          }

          float temp2 = 0.000;

          ReadADC(1);
            
          Code_high[1] = ReadValue[1];

          Serial.print("Code high ");
          Serial.print("Voltage");
          Serial.print(": ");
          Serial.println(Code_high[1]);

          Gain_error[1] = (Code_high[1] - Code_low[1])/(v_high-0.000);
          Offset[1] = Code_high[1] - Gain_error[1]*v_high;

          Serial.print("Offset ");
          Serial.print("Voltage");
          Serial.print(": ");
          Serial.println(Offset[1]);

          Serial.print("Gain Error ");
          Serial.print("Voltage");
          Serial.print(": ");
          Serial.println(Gain_error[1]);

          ReadADC(1);

          temp2 = (ReadValue[1] - Offset[1])/(Gain_error[1]);

          Serial.print("Voltage ");
          Serial.print(": ");
          Serial.println(temp2,3);
          
          EEPROM.put(4,Offset[1]);
          EEPROM.put(34,Gain_error[1]);
          
        }

        if (a == 1003)
        {
          float v_high = Serial.parseFloat();
          Serial.println(v_high,3);

          ReadADC(2);

          Code_low[2] = ReadValue[2];
          delay(100);

          Serial.print("Code low ");
          Serial.print("Voltage");
          Serial.print(": ");
          Serial.println(Code_low[2]);

          int temp4 = 0;
          
          Serial.println("Connect Full scale reference and enter value 1");
          while(temp4 == 0)
          {
            temp4 = Serial.parseInt();
            wdt_reset();
          }

          float temp2 = 0.000;

          ReadADC(2);
            
          Code_high[2] = ReadValue[2];

          Serial.print("Code high ");
          Serial.print("Voltage");
          Serial.print(": ");
          Serial.println(Code_high[2]);

          Gain_error[2] = (Code_high[2] - Code_low[2])/(v_high-0.000);
          Offset[2] = Code_high[2] - Gain_error[2]*v_high;

          Serial.print("Offset ");
          Serial.print("Voltage");
          Serial.print(": ");
          Serial.println(Offset[2]);

          Serial.print("Gain Error ");
          Serial.print("Voltage");
          Serial.print(": ");
          Serial.println(Gain_error[2]);

          ReadADC(2);

          temp2 = (ReadValue[2] - Offset[2])/(Gain_error[2]);

          Serial.print("Voltage ");
          Serial.print(": ");
          Serial.println(temp2,3);
          
          EEPROM.put(8,Offset[2]);
          EEPROM.put(38,Gain_error[2]);
          
        }

        if (a == 1004)
        {
            float tempNow01 = Serial.parseFloat();
            float tempNow02 = Serial.parseFloat();
            float tempNow03 = Serial.parseFloat();

            OCP = tempNow01;
            OVP = tempNow02;
            UVP = tempNow03;

            Serial.print("OCP: ");
            Serial.println(OCP);
            Serial.print("OVP: ");
            Serial.println(OVP);
            Serial.print("UVP: ");
            Serial.println(UVP);

            EEPROM.put(100, OCP);
            EEPROM.put(104, OVP);
            EEPROM.put(108, UVP);

            EEPROM.get(100,OCP);
            EEPROM.get(104,OVP);
            EEPROM.get(108,UVP);
        }
        if (a == 1005)
        {
            OCPCount = 0;
            OVPCount = 0;
            UVPCount = 0;
        }
        
        if (a == 1006)
        {
          digitalWrite(9, LOW);
          digitalWrite(8, LOW);
          OVPGood = 0;
          UVPGood = 0;
          OCPGood = 0;
          ResetFaultO = 1;
          ResetFaultU = 1;
          ResetFaultV = 1;
        }
        if (a == 1007)
        {
            digitalWrite(9,HIGH);
            digitalWrite(8,HIGH);
            OVPGood = 1;
            UVPGood = 1;
            OCPGood = 1;
            ResetFaultO = 0;
            ResetFaultU = 0;
            ResetFaultV = 0;
          
        }
        if (a == 1008)
        {
            float temp = Serial.parseFloat();
            EEPROM.put(1000,temp);
            EEPROM.get(1000,mV_A);
            Serial.println(mV_A);
        }
        if (a == 1009)
        {
            Serial.print("OCP Value: ");
            Serial.println(OCP);
            Serial.print("OVP Value: ");
            Serial.println(OVP);
            Serial.print("UVP Value: ");
            Serial.println(UVP);

            Serial.println("Revision #: A9");
        }
        if (a == 1010)
        {
            long temp = Serial.parseInt();
            EEPROM.put(1004,temp);
            EEPROM.get(1004,Timer);
        }
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

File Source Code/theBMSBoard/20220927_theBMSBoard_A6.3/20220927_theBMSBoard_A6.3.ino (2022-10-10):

////////////////////////////////////////////////////////////////////////////////
// 
// Title: 8S Arduino BMS
// Date: 20220927
// Version: A6.3
// Description: This code will work with hardware version A2_00003
// -----------------------------------------------------------------------------
// Bootloader settings: Minicore
// https://github.com/MCUdude/MiniCore#supported-microcontrollers
// -----------------------------------------------------------------------------
// 1. Clock: External 16 MHz 
// 2. BOD: BOD 2.7V
// 3. Compiler LTO: LTO disabled
// 4. Varient: 328PB
// 5. Bootloader: Yes (UART0)
////////////////////////////////////////////////////////////////////////////////


////////////////////////////////////////////////////////////////////////////////
// Libraries used for TFT Screen
////////////////////////////////////////////////////////////////////////////////
#include <Adafruit_GFX.h>    // Core graphics library
#include <Adafruit_ST7789.h> // Hardware-specific library for ST7789
#include <SPI.h>

#include <Wire1.h>
#include <Wire.h>
#include <EEPROM.h>
#include <avr/wdt.h>
#include "ADS1119.h"

////////////////////////////////////////////////////////////////////////////////
// Defines for TFT screen
////////////////////////////////////////////////////////////////////////////////
#define TFT_CS      2
#define TFT_RST     -1
#define TFT_DC      3
Adafruit_ST7789 tft = Adafruit_ST7789(TFT_CS, TFT_DC, TFT_RST);

// Color definitions
const uint16_t  Display_Color_Black     = 0x0000;
const uint16_t  Display_Color_Blue      = 0x001F;
//const uint16_t  Display_Color_Red       = 0xF800;
const uint16_t  Display_Color_Green     = 0x07E0;
const uint16_t  Display_Color_Cyan      = 0x07FF;
//const uint16_t  Display_Color_Magenta   = 0xF81F;
//const uint16_t  Display_Color_Yellow    = 0xFFE0;
//const uint16_t  Display_Color_White     = 0xFFFF;

// The colors we actually want to use
//uint16_t    Display_Text_Color      = Display_Color_White;
uint16_t    Display_Backround_Color = Display_Color_Black;


////////////////////////////////////////////////////////////////////////////////
// Array used for setting digital pins output
////////////////////////////////////////////////////////////////////////////////
int DigitalPin[8] = {5,6,7,8,9,10,4,12};

////////////////////////////////////////////////////////////////////////////////
// Variables used for counters to ensure that other functions can run during the
// off time of other functions
////////////////////////////////////////////////////////////////////////////////
int currentTime = 0;
int previousTimeDisplay = 0;
int previousTimeLoop = 0;
int previousTimeTFTDisplay = 0;
int previousTimeReset = 0;

////////////////////////////////////////////////////////////////////////////////
// Variables used for fault conditions when triggered in order to know what 
// fault scenario was triggered
////////////////////////////////////////////////////////////////////////////////
int flag[6] = {0,0,0,0,0};  // {UVP cell, OVP cell, UVP pack, OVP pack, OCP}
int resetP = 0;
int countOVP = 0;
int countUVP = 0;
int faultCase = 0;
char *faultCondtion[] = {"No fault          ", "Cell UVP Triggered ", "Cell OVP Triggered ", "Pack OVP Triggered", "Pack UVP Triggered", "OCP Triggered"};
int fc = 0;


////////////////////////////////////////////////////////////////////////////////
////////////////////////////////////////////////////////////////////////////////
float diff[8];
float cell[8] = {0.000, 0.000, 0.000, 0.000, 0.000, 0.000, 0.000, 0.000};
float BAT[8] = {0.000, 0.000, 0.000, 0.000, 0.000, 0.000, 0.000, 0.000};

////////////////////////////////////////////////////////////////////////////////
// Two point calibration method values
////////////////////////////////////////////////////////////////////////////////
int Code_low[8];
int Code_high[8];

float Gain_error[8];
unsigned int Offset[8];

////////////////////////////////////////////////////////////////////////////////
// Configurable variables via Serial monitor and stored in EEPROM
////////////////////////////////////////////////////////////////////////////////
int revision = 6.3;
int onTime = 1000;

float tol = 0.02;
float OVP = 3.75;
float UVP = 2.70;
float CurrentPack = 0.000;
float AhPack = 0.000;
float Runtime = 0.000;

int NodeNum = 1;

////////////////////////////////////////////////////////////////////////////////
////////////////////////////////////////////////////////////////////////////////
char balanceState[8];
char Current_Pack[6];
char Ah_Pack[6];


void(* resetFunc) (void) = 0;


void setup()
{
    Serial.begin(115200);

    Wire1.begin(); // Server I2C address 
    Wire.begin(); //  Start I2C for ADC

    /* Store ADC calibration values in EEPROM memory */
    for (int t = 0; t < 8; t++)
    {        
        EEPROM.get((t*4),Offset[t]);
        Serial.println(Offset[t],3);
    }

    for (int t = 0; t < 8; t++)
    {        
        EEPROM.get((t*4)+100,Gain_error[t]);
        Serial.println(Gain_error[t]);
    }

    for (int t = 0; t < 5; t++)
    {
      EEPROM.get((t*2)+500,flag[t]);
      Serial.print("Flag ");
      Serial.print(t);
      Serial.print(": ");
      Serial.println(flag[t]);
    }

    /* Store tolerance value (delta between the lowest cell and the rest of 
    the cells.  Also store cell level over-voltage and under-voltage limits */
    EEPROM.get(200,tol);
    Serial.println(tol,3);

    EEPROM.get(204,UVP);
    Serial.println(UVP,3);

    EEPROM.get(208,OVP);
    Serial.println(OVP,3);

    EEPROM.get(212,onTime);

    /* Configure I/O ports */
    for (int x = 0; x < 8; x++)
    {
        pinMode(DigitalPin[x],OUTPUT);
    }

    pinMode(PIN_PB7,INPUT_PULLUP);
    pinMode(A1, INPUT_PULLUP);

    PORTD = PORTD & B00001111;
    PORTB = PORTB & B11101000;


    /* Setup for TFT screen and for template for measurement */
    tft.init(135, 240);

    tft.fillScreen(ST77XX_BLACK);
    tft.setRotation(0);
    
    tft.setCursor(0,0);
    tft.setTextSize(2);
    tft.print("B1: ");

    tft.setCursor(0,20);
    tft.setTextSize(2);
    tft.print("B2: ");

    tft.setCursor(0,40);
    tft.setTextSize(2);
    tft.print("B3: ");

    tft.setCursor(0,60);
    tft.setTextSize(2);
    tft.print("B4: ");

    tft.setCursor(0,80);
    tft.setTextSize(2);
    tft.print("B5: ");

    tft.setCursor(0,100);
    tft.setTextSize(2);
    tft.print("B6: ");

    tft.setCursor(0,120);
    tft.setTextSize(2);
    tft.print("B7: ");

    tft.setCursor(0,140);
    tft.setTextSize(2);
    tft.print("B8: ");

    tft.setCursor(0,160);
    tft.setTextColor(Display_Color_Cyan , ST77XX_BLACK);
    tft.setTextSize(1);
    tft.print("V_Pack: ");

    tft.setCursor(0,170);
    tft.setTextColor(Display_Color_Cyan , ST77XX_BLACK);
    tft.setTextSize(1);
    tft.print("Current: ");

    tft.setCursor(0,180);
    tft.setTextColor(Display_Color_Cyan , ST77XX_BLACK);
    tft.setTextSize(1);
    tft.print("Power: ");
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

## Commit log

2021-07-03 Adding the Protection Board schematic files
    [20190720_Project_OCP-OVP-UVP.kicad_pcb, 20190720_Project_OCP-OVP-UVP.sch, InputConnector.sch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]
2021-07-03 Adding gerber files
    [20190720_Project_OCP-OVP-UVP-B_Mask.gbs, 20190720_Project_OCP-OVP-UVP-B_Paste.gbp, 20190720_Project_OCP-OVP-UVP-B_SilkS.gbo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]
2021-07-03 Adding the BMS board kicad files
    [20200103_8SBMS_A0-B_Mask.gbs, 20200103_8SBMS_A0-B_Paste.gbp, 20200103_8SBMS_A0-B_SilkS.gbo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]
2021-07-03 Added the Passive Balance Board
    [20210213_Projects_PassiveBalanceBoard-B_Mask.gbs, 20210213_Projects_PassiveBalanceBoard-B_Paste.gbp, 20210213_Projects_PassiveBalanceBoard-B_SilkS.gbo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]
2021-07-03 Added source code for the BMS Board
2021-10-17 Adding wiring diagram for single 8S pack system
    Here we have a wiring diagram for a single 8S pack that will be charged by solar or external psu. Also shows the connection for providing power to an inverted or a dc load.
2022-10-10 Updated firmware for mBMS main board
    Version A6.3 adds some tft on screen features like SoC which is actually runtime in minutes at the moment but could be changed to actual percentage
2022-10-10 Updated Protection Board code
    Added basic coulomb counter and full charge pack voltage recalibration for the counter. When the pack has his the full pack voltage value set in the parameter then the Ah of the pack will reset to entered Ah of pack. Need to optimize later down the road but this is good enough for most people.
    [20220901_Projects_Protection_PB_A10.ino]
2023-01-13 Updated multi battery diagram
    Updated multi parallel battery diagram. Ideal diodes were incorrectly represented in position

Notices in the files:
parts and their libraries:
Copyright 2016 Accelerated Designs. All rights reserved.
